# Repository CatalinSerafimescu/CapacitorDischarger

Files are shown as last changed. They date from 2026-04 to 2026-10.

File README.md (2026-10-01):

# 600V Capacitor Discharger

A professional, handheld capacitor discharger designed for safely discharging high-voltage capacitors in hobby electronics restoration — tube amplifiers, vintage radios, CRT televisions, and consumer power supplies.

---

## Features

- Discharges capacitors up to **600V** in **under 60 seconds** (up to ~1200µF)
- **Adaptive discharge:** controlled current above ~63 V (slow resistive path); fast dump below (MOSFET-switched). Switch point 55–83 V across Q1 hFE (25–300) and 0–60 °C corners; peak fast-dump current ≤ 1.6 A
- **Red LED danger indicator:** ON above ~10V, OFF when safe — powered directly from the capacitor, no external supply. Uses a low-current (2 mA) LED: the chain current is only ~50 µA at 30 V, where a standard LED looks dark
- **Integrated digital voltmeter:** Axiomet PM-128 3½-digit LCD reading volts directly ("600" at 600 V, 1 V steps) via a 10 000:1 divider, powered by any floating external 9 V source plugged into a panel DC jack (5.5×2.1)
- **Reverse polarity protection:** 1N4007 full-bridge rectifier
- **Protection fuse:** 600V-rated 2A fuse on the HV+ line guards against single-fault conditions
- **Thermal cutoff on R_fast:** if the probes touch a *live* supply below the threshold, Q2 stays on and R_fast would dissipate 41–74 W indefinitely (the 2 A fuse never blows) — a one-shot 133 °C thermal fuse clamped to R_fast opens the fast path; the slow path keeps working. **Still: never connect the tool to a powered circuit.**
- Designed for **DIY assembly** with through-hole components
- A residual ~1.2–1.4V remains on the capacitor (two bridge-diode drops) — below the 10V safe threshold

---

## Building it

Step-by-step build, wiring, test, calibration and use: **[instruction.md](instruction.md)**.
Single-sided board files: `KiCAD/fab_1s/`. 3D-printed case: [mechanical/enclosure/](mechanical/enclosure/README.md).

---

## Schematic

Schematic

---

## Bill of Materials

See **[bom.md](bom.md)** for the full component list with sourced vs. to-buy status.

**Note on DVM power:** the PM-128 draws ~1 mA from a 9 V source on its own DC jack (~500 h from an alkaline 9 V cell on a plug). Its datasheet requires the supply and the measured input to have separate grounds, so the source must float (battery or double-insulated adapter) — it is **not** connected to circuit GND.

**Note on DVM calibration:** set with the PM-128's own trimmer (R4) against a known DC voltage. The meter's >100 MΩ input doesn't load the divider. (The earlier 0–100 V LED module was dropped: its 0.525 MΩ input made the 6:1 divider uncalibratable.)

---

## Reference Designs

This design consolidates ideas from three published reference designs:

| Source | Designer | Reference File |
|---|---|---|
| [Pieraisa capacitor discharger kit](https://www.pieraisa.it) | Mark Maher/Pieraisa | [pieraisa.md](pieraisa.md) |
| [DIY 600V Capacitor Discharger — Constant Current](https://retronics.no/2024/03/30/diy-600-volts-capacitor-discharger-constant-current/) | Retronics.no | [600V_constant_current.md](600V_constant_current.md) |
| [Capacitor Discharger Deluxe – Smart, Fast & Safe High-Voltage Discharge](https://www.youtube.com/watch?v=5_QUd8iT3_g) | Manuel Caldeira / MAC Electronics | [deluxe.md](deluxe.md) |

---

## Improvements Over Reference Designs

### vs. Pieraisa
- Rated for **600V** (Pieraisa: 500V)
- **Automatic** threshold switching via MOSFET+NPN — no relay, no moving parts, no manual button
- Sharper LED cutoff: **~10.2V** Zener-defined threshold (Pieraisa: ~44V, divider-based)
- LED powered directly from HV+ — independent of relay state
- **Direct-reading voltmeter** with a 10 000:1 divider for the 600V range (Pieraisa's divider is mismatched at ~5:1)
- Each slow-path resistor explicitly stress-derated at 61% of rating at 600V

### vs. Retronics.no (constant current)
- **Faster discharge for large caps:** adaptive resistance allows higher initial current, not capped at 10mA
- Standard **FR4 through-hole PCB** — no aluminium PCB or SMD required
- No exotic ICs (Retronics requires LR8K4-G + 800V CoolMOS MOSFET pre-stage)
- **Integrated voltmeter**, calibratable (not present in Retronics design)
- Defined **10.2V LED cutoff** (Retronics LED is always in the current path — no threshold)

### vs. DeLuxe (Manuel Caldeira)
- MOSFET upgraded to **STP10NK80Z (800V, 0.9 Ω)** — IRF840 (500V) is marginal at 600V
- Slow path split into **5× 4.7kΩ/5W** in series — distributes heat; single 820Ω/10W in DeLuxe is a thermal bottleneck at high voltage with large caps
- **R1 and R5 properly rated** for 600V: 3W, 750V working voltage (DeLuxe leaves ratings unspecified)
- **Zener-defined LED threshold at 10.2V** — DeLuxe LED fades naturally with no defined safe cutoff; note the LED is dim below ~70V, so a low-current (2mA-rated) LED is used
- **Full voltmeter circuit added** with 10 000:1 divider, open-resistor input clamp, and battery-powered LCD meter (not present in DeLuxe)
- Every component carries explicit power and voltage stress analysis in the BOM

---

## Generating the Schematic and BOM

### Schematic

Requires [schemdraw](https://schemdraw.readthedocs.io/):

```
pip install schemdraw
python blocks/gen_full_schematic.py
```

Outputs `blocks/full_schematic.svg`.

### BOM

```
python bom.py
```

This prints a summary to the terminal **and** writes `bom.md` and the shopping list `TO_BUY_list.csv`.

The BOM (`bom.py`) is the single source of truth for all component data. It combines:
- **Design decisions** — part values, ratings, and stress calculations recorded directly in the BOM entries
- **Sourced components** — parts already in hand from the TME order (see [sourced_components.md](sourced_components.md)), marked `sourced` or `sourced_partial`
- **Parts to buy** — marked `buy`, with suggested part numbers

Schematic labels are generated from the same BOM data via the `LABEL` dictionary, so updating a value in `bom.py` automatically flows through to the schematic on the next generation run.

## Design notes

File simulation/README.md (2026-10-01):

# Simulation — 600 V Capacitor Discharger

Transient and DC-sweep SPICE simulations to verify every operating regime before PCB commit.

## Prerequisites

- **ngspice 46** at `E:\Catalin\Work\Electronics\NGSpice_46\bin\ngspice.exe`
- Python 3.x with `numpy`, `matplotlib`, `pandas`

Verify ngspice:
```
"E:\Catalin\Work\Electronics\NGSpice_46\bin\ngspice.exe" -v
```

## Running

```bash
cd simulation

# Run all scenarios
python run_sim.py --all

# Run one scenario
python run_sim.py A_full_600V_1mF

# List available scenarios
python run_sim.py --list
```

Results land in `results/<scenario_name>/`:
- `sim.cir` — rendered netlist fed to ngspice
- `out.csv` — time + node voltages + branch currents
- `plot.png` — 3-panel plot
- `summary.txt` — PASS/FAIL per assertion

Aggregate: `results/RESULTS.md`

## Scenarios

| Name | V0 | C_dut | Purpose |
|---|----|---|---|
| `A_full_600V_1mF` | 600 V | 1 mF | Full sweep, all regimes |
| `B_mid_300V_470uF` | 300 V | 470 µF  | Typical hobby cap |
| `C_mid_100V_100uF` | 100 V | 100 µF  | Brief slow then fast |
| `D_low_50V_100uF` |  50 V | 100 µF  | Fast-path-only from t=0 |
| `E_below_LED_8V_100uF` | 8 V | 100 µF  | LED stays OFF |
| `F_steady_state_600V`  | 600 V | 100 mF  | Quasi-steady-state probes |
| `G_threshold_sweep` | DC sweep 0→200 V | — | Confirm ~63 V switch point |
| `G2_threshold_lowbeta` | DC sweep 0→200 V | — | Worst-case low-hFE (BF=40) Q1 corner: switch point shifts only to ~68 V with R3 = 10 kΩ |
| `G3_threshold_cold_lowhfe` | DC sweep 0→200 V | — | Datasheet-min hFE (BF=25) at 0 °C: highest switch point (~83 V) → worst peak I_fast ≈ 1.6 A, still < 2 A |
| `G4_threshold_hot_highhfe` | DC sweep 0→200 V | — | BF=300 at 60 °C: lowest switch point (~55 V) |
| `H_dvm_divider_clamp` | DC sweep 0→600 V | — | PM-128 10 000:1 divider (5 × 100 kΩ over 2 × 100 Ω): reads 599.9 at 600 V (before R4 trim) and 10.00 at 10 V; with the bottom resistors open, D_clamp holds the meter input at 0.72 V |
| `I_reverse_600V_1mF` | −600 V | 1 mF | Reverse polarity: same 45 s discharge, −1.05 V residual, DVM still reads positive |
| `J_hotplug_600V` | 600 V | 1 mF | Probe contact onto a charged cap (1 µH leads, 1 µs contact): Q2 must not conduct |
| `K_bigcap_60V_47mF` | 60 V | 47 mF | ~85 J fast dump into R_fast — TF1 must not nuisance-trip |
| `L_live_supply_48V` | 48 V source | — | Probes on a live supply: R_fast would see ~41 W forever (F1 never blows) — TF1 must open |

(Scenario `H_dvm_led_module` was removed 2026-07-29: it documented that the parasitic Vcc dropper could not power a 20–30 mA LED-display DVM module; the real module measured 12–15 mA, so the dropper was replaced by an internal 9 V battery and the Vcc branch no longer exists in the netlists.)

## Adding a scenario

1. Add an entry to `scenarios.py::SCENARIOS` with `name`, `template`, `v0`, `cdut`, `tstep`, `tstop`, and an `assertions` function.
2. The assertions function receives a `pandas.DataFrame` (columns = ngspice output names) and returns `list[(bool, str)]`.
3. Run `python run_sim.py <your_name>`.

## Key nodes

| Node | Meaning |
|---|---|
| `V(HVp)` | Post-bridge discharge-network rail — ~1.2 V below the actual capacitor voltage (two diode drops through the reverse-polarity bridge D1-D4); all existing assertions are written against this rail |
| `V(n_probe_a)`, `V(n_probe_b)` | Capacitor terminals (transient scenarios only) — `V(n_probe_a) - V(n_probe_b)` is the true cap voltage, including the ~0.4-2.5 V permanent residual left by the bridge |
| `V(n_gate)` | MOSFET gate (~12 V = on, <1 V = off) |
| `V(n_sigout)` | PM-128 input — V(HVp) / 10 000 (×10 000 = displayed reading) |
| `I(V_islow)` | Slow path current |
| `I(V_ifast)` | Fast path (MOSFET) current |
| `I(V_iled)` | LED chain current |
| `V(n_temp)` | R_fast/TF1 body temperature in °C (behavioural thermal model) |
| `V(n_tf_latch)` | TF1 state: > 0.5 V = thermal cutoff has opened (one-shot) |

## Model notes

- **Q2 (fast-path MOSFET):** `STP10NK80Z` is a generic SPICE level-1 model standing in for the sourced BOM part (0.9 Ω Rds(on), 800 V, 9 A). It is not a vendor-supplied model — replace with one if available.
- **Q1 (threshold detector):** `QMPSA42` uses BF=150 (optimistic hFE). `QMPSA42LB` is a worst-case corner with BF=40, matching real MPSA42 hFE at ~1 mA collector current. With R3 = 10 kΩ (reduced from 100 kΩ on 2026-07-29) the switch point is nearly hFE-independent: scenario G measures 63 V with the nominal model, scenario G2 measures 68 V at the low-hFE corner. (With the old R3 = 100 kΩ these were 76 V and 154 V — the reduction was made precisely to close that spread.)
- **TF1 thermal model (assumed values):** R_fast power heats a 3 J/K heat capacity that leaks to 25 °C ambient through 25 K/W; TF1 (SEFUSE SF129E) opens permanently at 133 °C. These thermal constants are estimates for an Ohmite 27J (7 W) body with the TCO clamped on — confirm on the bench (48 V PSU on the probes should open TF1 within roughly 5–20 s; a 47 mF/60 V dump must not).
- **Corners:** G3/G4 use `discharger_dc_corner.cir.tmpl` with per-scenario `QMODEL`/`TEMP` substitutions. Scenarios can pass extra template substitutions through a `"subs"` dict; the transient template takes `DUT` and `IC` overrides (defaults in `run_sim.py`).
- **Error handling:** `run_sim.py` fails a scenario if ngspice exits non-zero *or* prints `fatal`/`error` anywhere in its output.
- **DVM power:** not modeled — the module is powered by an internal 9 V battery (its measured 12–15 mA draw exceeded what the former parasitic dropper could supply), so it presents no load to the HV circuit. Only its 600 kΩ signal divider remains in the netlists.

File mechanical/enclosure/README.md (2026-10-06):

# Enclosure: 3D-printable case for the single-sided board

There is one parametric FreeCAD script, [`gen_enclosure.py`](gen_enclosure.py), with all dimensions at the top.
[`assembly.py`](assembly.py) places the real board, the DC jack and stand-ins for the sockets, the PM-128 and the LED. It then
reports overlaps and HV distances. The result is saved as [`Enclosure_assembly.FCStd`](Enclosure_assembly.FCStd).

To regenerate, run both scripts inside FreeCAD (Python console or MCP), from `mechanical/enclosure/`:
```
exec(open("gen_enclosure.py", encoding="utf-8").read()); exec(open("assembly.py", encoding="utf-8").read())
```

The outside is **106.8 W × 132.8 D × 52 H mm**. It is designed for `CapacitorDischarger_1S` (100 × 75, FEPCU-075).

| Part | What it is | How to print |
|---|---|---|
| `Enclosure_base` (.step / .stl) | Open box: floor plus four walls, board standoffs, support posts, snap hooks, 4 screw bosses, socket, LED and jack holes, engraved 9 V warning | Floor down, no supports |
| `Enclosure_cover` (.step / .stl) | Top plate: meter window, baffled vents, lip inside the walls, 4 counterbored screw holes | **Upside down** (top on the bed), no supports |

- **Filament:** PETG or ASA, not PLA, because the resistors run hot.
- **Strength:** at least 3 perimeters and 25 % infill.
- **Style:** the same as the SursaTensiune case. It has R6 vertical corners, a 3 mm chamfer on the top edge and a 1.2 mm chamfer on the bottom edge.

## Layout
- **Front wall.** The sockets sit low (Z 15), in a 50 mm gap in front of the board.
  - **Danger LED (LED1)** at the top left, labelled "HV". It is on a 2-wire cable to J6 (JST XH) on the board.
  - It sits in a 5 mm panel clip (Ø8 collar, Ø6.5 body, 7 mm long) in a Ø6.6 hole at X 14.4. The hole is centred in the 8 mm gap between the front-left cover boss and the meter. Clip in from the front, LED pushed in from inside, no glue.
  - The black **−** socket (J2 → J4) and the green **+** socket (J1 → J3) are on the right, 20.5 mm apart.
  - Each socket lines up with the inner wire entry of its MKDS terminal block. Its M4 ring lug points straight into that entry, about 7 mm short of the block. The probe wires are short and straight, so they don't cross.
  - The terminal-block screws stay free to reach from the top.
- **Left wall, front end.** The 9 V DC jack sits low (Z 15) under an engraved warning triangle. Next to it:
  "9 V DC IN + centre / FLOATING SUPPLY ONLY / 9 V battery or isolated adapter. / NEVER an earthed / grounded supply!".
  The rear wall has no room for it: the board fills the box right up to it.
- **Cover.**
  - **PM-128 meter.** It sits above the socket gap: window 44.5 × 19.7 mm, plus two Ø3.2 holes 57.15 mm apart.
  - **Label.** "600 V MAX" is engraved under the meter.
  - **Vents.** Five 2 mm slots sit above R_slow1–5. Each slot has a solid baffle strip 3 mm below it, wide enough that no straight wire or probe tip can reach HV through a slot.
- **Board fixing.** The PCB has only 2 holes, so the base adds the rest:

  | Feature | Where | Job |
  |---|---|---|
  | 2 standoffs (6 mm) | H1, H3 | M3×12 **nylon** screws from the top, nuts in hex pockets under the floor |
  | 4 support posts | under J3/J4 (screwdriver force) and under the two F1 clip centres (pushing the fuse in) | carry the load |
  | 3 snap hooks | front-left, front-right and rear-left corners | a 45° ledge under the copper-free edge, and a nose 0.8 mm over the board top |
  | 4 side ribs | side walls | locate the board in X with 0.3 mm play |

  - The board clicks down into the hooks. To lift it out, take out the two screws and push the hooks outwards.
  - The board's top side has no copper, so the hooks only touch FR4. Leave the F1 clip centre holes empty, because the posts sit under them.
- **Cover fixing.** 4 × **M3×10** go into M3 heat-set inserts (Ø4.0 × 6.5 mm holes) in bosses hanging from the walls. The bosses have a 45° underside, so they print without support.
  - Three bosses are in corners. The fourth sits on the rear wall at X 20, so the LED cable can rise from J6 in that corner.
  - Opening the box needs a tool, which is right for an HV device. The magnets aren't needed.
- **Below the board.** The standoffs are 6 mm tall and all the HV copper is on the underside, so **trim every lead to ≤ 3 mm**. The stock TO-220 3D model shows uncut Q2 legs reaching the floor.

## Assembly
1. Fit the sockets (front wall) and the DC jack (left wall), with their nuts on the inside. Push the LED clip into the front wall from the outside,
   with its slots vertical so the body spreads up/down, away from the boss and the meter. Push the LED into it from inside:
   heat-shrink both legs, then crimp the XH housing onto ~15 cm of 1 kV silicone wire. Pin 1 = cathode (GND), pin 2 = anode.
2. Wire the sockets to J3/J4 with 1.5 mm² silicone wire (0.6/1 kV) and M4 ring lugs, and put heat-shrink over the lugs.
3. Press in the heat-set inserts.
4. Put the board on the standoffs, let it click into the hooks, and fit the two nylon screws. Plug the LED into J6
   (rear-left). Run its cable up and along the left wall, above the Q2 heatsink, then down to the front.
5. Fit the meter under the cover: two screws through the cover into the bezel. Wire the meter:
   - **Supply:** DC jack → PM-128 supply pins.
   - **Input:** J5 → PM-128 VIN / IN GND. This cable runs over the HV area, so use the same 1 kV silicone wire.
6. Leave the wires long enough that the cover can be laid down beside the box. Close it with the 4 M3×10 screws.
7. Stick rubber feet under the floor.

**9 V input:** any **floating** 9 V source on a 5.5×2.1 plug (centre +). A battery on a plug or a double-insulated adapter is fine. Never use a supply whose − is earthed or connected to the device under test, because circuit GND sits at the capacitor's negative terminal (see BOM, BT1).

## Fit check (FreeCAD, `assembly.py`)
- **Overlaps.** None between base and cover, or between either of them and the board, jack, sockets, meter or LED. The one exception is Q2's uncut 3D-model legs (see above).
- **Height.** The tallest part, R_fast1, tops out at Z 47.0, and the inner face of the cover is at Z 49.6.
  - Baffle strips → R_slow: ≥ 6.6 mm.
  - LED clip / LED flange → meter: 1.1 mm (clip → boss 0.75 mm). Both are LV; the meter only moves in Z when the cover goes on.
  - DC jack → meter: 8.3 mm.
- **HV clearances, all at least 6 mm:**
  - Meter → socket lugs/bolts: 6.9 mm.
  - Socket A metal → socket B metal: 12.5 mm.
  - Socket B → DC jack: 45.9 mm.
- **Tightest gap:** J3's terminal block and the front-right hook are 0.1 mm apart. That hook is 3 mm wide so it stays clear of the block.

## Check before printing
- **PM-128 (VERIFY):** 70 × 40 mm bezel, 23 mm deep, window 1.75 × 0.775 in, Ø3.2 holes 2.25 in apart (MPJA PM128 sheet). Measure your meter; the values are `MET`, `MET_WIN` and `MET_HOLE_*`.
- **Stäubli SLB4-G:** Ø12.1 hole with a flat 11.0 mm across, printed with the flat on top. The socket and nut in `assembly.py` are stand-ins; the real nut size isn't on the datasheet.
- **Heat-set inserts:** use one that fits a Ø4.0 hole and is ≤ 6 mm long. Otherwise change `INS_D` / `INS_L`. With `INS_D = 2.6` the screws thread straight into the PETG.
- **Test print:** print the front-right corner first (sockets, hook, boss) to check the socket fit and the hook snap.

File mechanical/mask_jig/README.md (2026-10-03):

# Solder-mask jig (single-sided board)

`Mask_jig.step` / `.stl`, made by `gen_mask_jig.py` (run in the FreeCAD GUI). For `CapacitorDischarger_1S`
(100 × 75 mm, Bungard FEPCU-075, 1.5 mm). 120.8 × 95.8 × 4.4 mm, print floor-down, no supports.

- **Pocket** 100.8 × 75.8 mm (0.4 mm per side around the board), **1.4 mm deep**: the 1.5 mm board sits 0.1 mm
  proud, so the film is pressed onto the board and then lies flat on the 10 mm frame. If your board is thinner
  than 1.4 mm, put a paper shim under it.
- **2 × Ø3.2 through holes** at the board's M3 holes H1 and H3, laid out for the board **copper side up**.
  Use Ø3 drill-bit shanks or M3 screws pushed up from below as registration pins. H1 and H3 aren't symmetric,
  so the board only fits one way round.
- Corner reliefs (square board corners in an FDM pocket) and 2 × Ø12 holes to push the board out from below.

## Use (UV solder mask)
1. Etched board **drilled**, cleaned, copper side up in the pocket. Pins up through H1 and H3.
2. Film: the B.Mask image on page 2 of `KiCAD/fab_1s/1S_films_1to1.pdf`, printed on transparency, **toner side down**.
   Punch or drill Ø3.2 through the two big H1/H3 dots. For a denser film, print it twice and stack the copies.
3. Paste on the board, film down over the pins, squeegee from the centre outwards. Excess goes into the gap and
   onto the frame. Tape the film edges to the frame.
4. Pull the pins out **downwards**, lay a sheet of glass on top for even pressure, expose. Ordinary picture-frame
   glass passes 395–405 nm LEDs well but cuts a lot at 365 nm: expose longer, or skip the glass with a 365 nm lamp.
5. Paste squeezed onto the frame cures there too. Cover the frame with one layer of packing tape before step 3 and
   peel it off afterwards, so the frame stays flat for the next board.
6. The HV slot under R1/R5 is already cut at this point (instruction.md step 4), so paste can squeeze through
   it onto the jig floor. Wipe the slot clean before exposing. Don't leave cured mask in it.

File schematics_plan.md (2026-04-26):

# Schematic Generation Plan

## Part 1 — HV Section (`hv_section.kicad_sch`)

**Components:**
- J1, J2 (banana sockets), J3, J4 (screw terminals) — input connectors
- D1–D4 (1N4007) — full-bridge rectifier
- R_slow1–R_slow5 (4.7 kΩ / 5W) — slow discharge path, series string to GND
- R_fast (50 Ω / 5W) — fast discharge path resistor
- Q2 (STF7NM80, TO-220) — MOSFET switch

**Interface nets (global labels):**
- `HV+` — rectified rail output
- `GATE` — Q2 gate input (driven by LV section)
- `GND`

---

## Part 2 — LV Section (`lv_section.kicad_sch`)

**Components:**
- Q1 (2N3904), R1 (1 MΩ), R2 (10 kΩ), R3 (100 kΩ), R4 (100 Ω), R5 (470 kΩ), D9 (12V Zener) — threshold detector + gate drive
- R_LED1–R_LED3 (100 kΩ), D_LED (8.2V Zener), LED1 (red 5mm) — danger indicator
- R_sig1–R_sig5 (100 kΩ), R_sig_bot (100 kΩ), R_cal (200 kΩ trimmer) — DVM divider
- R_drop1–R_drop4 (15 kΩ / 3W), D_Vcc (15V Zener), C_Vcc (10 µF), C_byp1, C_byp2 (100 nF) — DVM Vcc dropper
- DVM connector (3-pin: GND, Vcc, Signal)

**Interface nets consumed (global labels):**
- `HV+`, `GATE`, `GND`

---

## Part 3 — Assembly (`schematic.kicad_sch`)

- Combine both files into one `schematic.kicad_sch`
- Merge `lib_symbols` sections (deduplicate)
- Verify all global label pairs are matched
- Add `sheet_instances`, `title_block`, PWR_FLAGs

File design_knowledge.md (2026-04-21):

# Capacitor Discharger — Design Knowledge Base

---

# PART 1: Reference Designs

## Source 1: Pieraisa Kit (500V, Italian design)

See `pieraisa.md` for full analysis.

**Key lessons:**
1. Relay-based adaptive discharge is an excellent passive approach (no IC, no firmware)
2. Diode bridge polarity protection works but 1N4007 is marginal at high voltage — prefer IC-based ideal diode
3. Fast discharge bypass switch is a useful safety feature
4. Multiple series resistors validated for heat distribution
5. Zener-based LED threshold is clean and reusable — tune Zener + divider ratio for desired cutoff voltage
6. Voltmeter powered from same rail works, but only when cap is charged — ensure adequate voltage at all relevant levels

---

## Source 2: Capacitor Discharger DeLuxe (MAC / Electronics Old & New, REV 1.0, 2025-12-22)

See `deluxe.md` for full analysis.

**Key lessons:**
1. MOSFET + NPN transistor gives clean automatic threshold switching with no moving parts (vs. relay)
2. 71V threshold set by R1/R2 divider + Q1 Vbe — above: slow controlled discharge; below: fast discharge via low-side MOSFET
3. Gate clamp zener (12V) protects MOSFET gate and sets clean gate drive regardless of cap voltage
4. Q1 can be any common NPN (2N3904, BC547) — no high-voltage rating needed
5. IRF840 is marginal at 600V (rated 500V Vds) — substitute with 700V+ device (e.g. STF7NM80, IXTP2N80)
6. 1N4007 bridge adequate for 600V (PIV = 1000V) but IC-based protection is our preference
7. PCB is compact (74×30mm) — design fits a handheld tool form factor

---

# PART 2: Our Design Knowledge & Decisions

---

## PCB Design — High Discharge Current Requirements

### Peak Current Analysis

| Path | Condition | Resistance | Peak current |
|---|---|---|---|
| High-V path | V_cap = 600V, R ≈ 820Ω | 820Ω | ~731mA |
| Low-V path (via MOSFET) | V_cap = 71V (switch point), R = 56Ω | 56Ω | **~1.27A** |

Design target: traces and pads must handle **2A continuous** with adequate margin.

### Trace Width

Per IPC-2221A (1oz copper, 10°C temperature rise):
- 1A → ~0.5mm minimum
- 2A → ~1.0mm minimum
- **Recommendation: 1.5–2.0mm on all discharge-path traces**; use copper pour (polygon fill) on GND and HV discharge return nodes

### High-Voltage Clearance and Creepage (600V, uncoated PCB)

| Metric | Rule of thumb | 600V value |
|---|---|---|
| Air clearance | 1mm per 100V | **≥6mm** |
| Creepage (external, uncoated) | IPC-2221, 300–900V range | **≥6mm** |
| Creepage (conformal coated) | Reduced per IEC 60664-1 | ~3mm (if coated) |

- Apply between: HV input traces, discharge resistor pads, MOSFET drain pad, and any GND/LV traces
- The DeLuxe PCB (74×30mm) achieves this by physically separating the HV resistor area from the control section

### Input Terminal Pads

- Use **≥4mm diameter** copper pads (confirmed from DeLuxe Gerbers)
- Screw terminals or banana jack sockets rated for ≥600V, ≥2A
- 1.5mm slotted drill holes (as in DeLuxe) suit standard 4mm banana terminals
- Solder with adequate fillet; consider through-hole reinforcement for mechanical stress

### Power Resistors

- Use **axial wirewound** resistors (e.g. Arcol HS, Vishay RH series) — better pulse energy handling than ceramic
- Mount with **minimum 3mm standoff** from PCB surface for convection cooling
- Orient resistors so airflow is not blocked by adjacent tall components
- Footprint pad spacing must match resistor body length at rated wattage (10W axial body ≈ 30–40mm)

### MOSFET

- TO-220 package preferred — easy heatsink attachment
- Include **heatsink mounting hole** on PCB or thermal pad area
- Place MOSFET at board edge for heatsink clearance
- Drain pad should connect directly to the wide discharge trace; avoid long thin drain neck

### Layout Zones

```
[ INPUT TERMINALS ] ─── [ HV DISCHARGE PATH ] ─── [ POWER RESISTORS ]
                               │
                         [ MOSFET + Heatsink ]
                               │
                    ─────────────────────────────
                    [ CONTROL / BIAS CIRCUIT     ]   ← Low voltage
                    [ LED + VOLTMETER DIVIDER    ]   ← Keep separated from HV
```

- Physical separation of ≥10mm between HV discharge traces and LV bias/LED/voltmeter traces
- Route voltmeter divider resistors away from the discharge current loop to avoid inductive interference

### Additional Notes

- **No 90° corners** on HV traces — use 45° or curved routing
- **Conformal coating** strongly recommended on finished board — especially over HV traces, divider resistors, and input pad area
- **Silkscreen warning** on PCB: mark polarity, voltage rating, and "HIGH VOLTAGE" near input terminals

---

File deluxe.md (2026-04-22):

# Capacitor Discharger DeLuxe — Schematic Analysis

**Source:** https://www.youtube.com/watch?v=5_QUd8iT3_g
**Schematic** https://drive.google.com/drive/folders/14RW6CgVl9O2DX6QJiTpvzaHROwtBKmW-
**Designer:** MAC / Electronics Old & New — REV 1.0  

---

## Core Design Intent

> "At high voltage → controlled, safe discharge. As voltage drops → discharge speed increases."

The circuit automatically adjusts discharge resistance based on capacitor voltage — no manual switching needed.

---

## Circuit Topology

### 1. Reverse Polarity Protection — Diode Bridge
- **D1–D4:** 4× 1N4007, full-bridge rectifier
- Probes can be connected in either polarity; rectified rail is always correct polarity internally
- 1N4007 PIV = 1000V — adequate margin for 600V use
- Voltage drop: ~1.4V across two diodes in series (negligible at high voltage)

### 2. Voltage-Sensing / Threshold Circuit
- **R1 (1MΩ) + R2 (10kΩ):** Voltage divider from rectified rail to GND
- **R3 (100kΩ):** Base resistor into Q1
- **Q1 (MPSA42 or 2N3904 NPN):** Turns ON when cap voltage exceeds threshold

**Threshold calculation:**
```
V_base = V_cap × R2 / (R1 + R2) = V_cap × 10k / 1.01M
Q1 turns ON when V_base > 0.7V → V_cap > ~71V
```

### 3. Gate Drive Circuit
- **R5 (470kΩ):** Pulls IRF840 gate toward rail voltage
- **R4 (100Ω):** Series gate resistor (limits gate charge/discharge speed)
- **D9 (12V Zener, 1.3W):** Clamps gate to 12V max (protects IRF840 gate oxide)
- **Q1 collector → R4 → gate:** When Q1 is ON, pulls gate low (overrides R5 pull-up)

**Gate voltage with Q1 ON (KCL, R5=470k, R4=100Ω, Q1 Vce_sat=0.2V):**
```
V_gate ≈ (V_cap/R5 × R4) + 0.2V ≈ 0.33V at 600V → IRF840 OFF
```

**Gate voltage with Q1 OFF:**
```
V_gate = min(V_cap, 12V) via R5 and D9 clamp → IRF840 ON
```

### 4. Main Discharge Paths

| Condition | Q1 | IRF840 | Active Path | Resistance | Behavior |
|---|-----|---|---|---|---|
| V_cap > 71V | ON | OFF | R7 (820Ω/10W) | 820Ω | Controlled, safe |
| V_cap < 71V | OFF | ON | IRF840 + R6 (56Ω/10W) | ~56Ω | Fast discharge |
| V_cap < 3–4V | OFF | OFF (Vgs < Vth) | None | ∞ | Fully discharged |

- **R7 (820Ω/10W):** Always-on high-resistance path — handles high-voltage discharge safely  
  - At 600V, peak power = 600²/820 = **439W** (brief pulse — acceptable for small caps)  
  - At 90V, peak power = 90²/820 = **9.9W** — right at rating; suitable for large caps (33,000µF range)
- **R6 (56Ω/10W):** Low-resistance fast path — active only below 71V via IRF840

### 5. LED Danger Indicator
- **R8 (100kΩ) + LED1:** Series from rail to GND
- Powers directly from capacitor — no external supply
- At 600V: I ≈ 6mA (bright)
- Dims as voltage drops; effectively invisible below ~3–5V
- **LED ON = charge present / dangerous; LED OFF = safe**

---

## Component List

| Ref | Value | Rating | Function |
|-----|---|---|---|
| D1–D4 | 1N4007 | 1000V / 1A | Bridge rectifier (reverse polarity protection) |
| Q1 | MPSA42 or 2N3904 | NPN | Voltage threshold sense transistor |
| IRF840 | Power MOSFET | 500V / 8A | Main discharge switch |
| D9 | 12V Zener | 1.3W | IRF840 gate clamp |
| R1 | 1MΩ | — | Voltage divider top leg |
| R2 | 10kΩ | — | Voltage divider bottom leg (sets 71V threshold) |
| R3 | 100kΩ | — | Q1 base resistor |
| R4 | 100Ω | — | IRF840 gate series resistor |
| R5 | 470kΩ | — | IRF840 gate pull-up |
| R6 | 56Ω | 10W | Fast (low-V) discharge resistor |
| R7 | 820Ω | 10W | Slow (high-V) discharge resistor |
| R8 | 100kΩ | — | LED current limiter |
| LED1 | Red LED | — | Voltage/danger indicator |

---

## Design Notes & Observations

### Switching Threshold (71V)
- Derived from R1/R2 divider and Q1 Vbe (0.7V)
- Adjustable by changing R1 or R2: `V_th = 0.7 × (R1 + R2) / R2`
- Example: for 50V threshold → R1 ≈ 700kΩ; for 100V → R1 ≈ 1.43MΩ

### IRF840 Voltage Rating
- IRF840 rated for 500V Vds — **marginal for 600V use**
- For 600V designs, consider: IRFBF20 (900V), STP6NK90Z (900V), or IRFP9240 (200V P-ch, not suitable) — prefer a 700V+ N-ch MOSFET with similar gate characteristics
- Alternatively: IRF740 (400V — too low), IXTP2N80 (800V), STF7NM80 (800V)

### Q1 Transistor Note
- Original schematic listed MPSA42 (high-voltage NPN, 300V), but designer corrected: **any common NPN works** (2N3904, BC547, etc.)
- Q1 never sees more than a few volts (gate/base voltages are clamped) — voltage rating is irrelevant

### Reverse Polarity — Bridge vs. IC
- This design uses a 1N4007 bridge (passive, robust, no power needed)
- 1N4007 PIV = 1000V; adequate for 600V with margin
- Per our project preference, an IC-based ideal diode (e.g. LTC4359) would reduce voltage drop and is preferred — **bridge can be replaced if needed**

### R7 Power Handling — Large Capacitors
- At high voltage (>71V), only R7 (820Ω/10W) is in the discharge path
- **Safe for small/medium caps** at high voltage (energy = ½CV²; low C means low total energy)
- **Marginal for very large caps** (e.g. 33,000µF @ 90V → ~134J through R7 at ~9.9W average; borderline)
- For large caps at high voltage, consider increasing R7 wattage or splitting into 2× 1kΩ/10W in parallel = 500Ω/20W

---

## Adaptations Needed for Our Requirements

| Requirement | Original DeLuxe | Action Needed |
|---|---|---|
| 600V rating | IRF840 = 500V (marginal) | Replace with 700V+ MOSFET (e.g. STF7NM80) |
| Voltmeter (0–100V DVM, 6:1 divider) | Not present | Add R_high (500kΩ) + R_low (100kΩ) divider; power DVM from divider output |
| IC-based polarity protection | 1N4007 bridge | Optional: replace bridge with LTC4359/MAX16141 |
| Series resistor network | R6 + R7 only | Current distribution is limited; consider 2 resistors per path for heat spread |
| LED threshold (5–10V cutoff) | Fades naturally below ~5V | Acceptable; or add Zener for sharper threshold (Pieraisa approach) |
| Digital voltmeter power | Not present | Tap from rectified rail via series resistor (e.g. 470kΩ) to power 5–30V DVM |

---

## Voltage Divider for Voltmeter (to add)

6:1 divider for 0–600V → 0–100V (DVM input):
```
R_high = 500kΩ (HV-rated, e.g. 5× 100kΩ/2W in series)
R_low  = 100kΩ (1% tolerance)
Divider ratio = 100k / (500k + 100k) = 1/6
At 600V input → 100V DVM input ✓
```
DVM powered from the R_low node (0–100V range covers the 5–30V DVM supply requirement only if cap voltage > 5V; for lower voltages DVM may power off — acceptable).

---

## Key Design Strengths

1. **Fully automatic adaptation** — no switches, no user interaction
2. **Simple, few components** — Q1, one MOSFET, two resistors, zener
3. **LED indicator** powered directly from cap — no external supply needed
4. **Inherent LED shutoff** at ~3–5V (safe voltage)
5. **Fast at low voltage** — 56Ω gives fast final discharge

---

## PCB Information (from Gerber v2.0, 2025-11-12)

- **Board size:** 73.66mm × 30.48mm (~74mm × 30mm) — compact, single PCB
- **Designed in:** EasyEDA v6.5.51
- **Layers:** 2-layer (top + bottom copper)
- **Notable pad/drill sizes:**
  - 4.0mm circular pads — large input/output terminal pads (high current)
  - 2.6×1.8mm oval+rect pads — power resistor pads (R6, R7 axial footprints)
  - 1.5mm slotted drill holes (×4, at corners) — input connectors (banana jack or screw terminal)
  - 0.75mm holes (×3, in-line) — TO-92 transistor Q1
  - 0.90mm slotted holes — diodes (D1–D4, D9)
  - 1.0–1.2mm holes — standard resistor/MOSFET leads

---

## Key Limitations vs. Our Requirements

1. IRF840 is marginal at 600V → needs substitute
2. No voltmeter circuit (must be added)
3. No IC-based polarity protection (bridge is functional but not preferred)
4. R7 (820Ω/10W) may overheat with very large caps at high voltage

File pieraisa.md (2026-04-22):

# Source 1: Pieraisa Kit — Reference Analysis

**Origin:** https://www.pieraisa.it/forum_share/KITS/Discharge.Tool.Datasheet.pdf
**Based on Mend It Mark design** https://www.youtube.com/watch?v=pNkEchLQWDU

**Rating:** 500V max, RDS = 120Ω min / 940Ω typ / 5640Ω max  

---

## Topology: Diode Bridge for Reverse Polarity Protection

- 4× 1N4007 diodes form a full bridge (D1+D3 on top rail, D4+D5 on bottom rail)
- Ensures discharge current always flows in the same direction through the circuit regardless of probe polarity
- Simple, passive, no IC needed
- **Limitation:** 1N4007 PIV = 1000V — right at the limit for 1000V designs; at 1000V, voltage spikes or transients will exceed the rating
- **Trade-off:** ~1.4V forward drop across two diodes in series (acceptable for high-voltage discharge, minimal energy loss)
- **For 1000V designs:** Need higher-rated diodes (e.g., 1N5408 = 1000V, or HV series like FR107, P6KE series), or move to IC-based protection

---

## Topology: Relay-Based Adaptive Discharge (Passive, Elegant)

- R2 (10kΩ, 7W) connects directly from the rectified high-voltage rail to the relay (RL1) coil
- At high capacitor voltage → sufficient current through R2 → relay energizes → connects low-resistance discharge path (R5 = 120–220Ω, 5W)
- As voltage drops → coil current decreases → relay drops out at its dropout voltage → circuit switches to higher resistance path (R1+R4 = 940Ω)
- **This is fully passive and automatic — no control IC, no comparator, no firmware**
- The relay dropout voltage determines the switching threshold (typically 8–10V for a 12V relay)
- **Key insight:** The relay coil itself acts as a current sensor and threshold detector simultaneously

---

## Resistor Network

| Resistor | Value | Power | Role |
|---|---|---|---|
| R5 | 120 or 220Ω | 5W | Fast/low-resistance discharge path (relay energized) |
| R1 | 470Ω | 5W | Series discharge resistor (relay dropped out) |
| R4 | 470Ω | 5W | Series discharge resistor (relay dropped out), R1+R4 = 940Ω |
| R2 | 10kΩ | 7W | Relay coil current limiter / adaptive threshold setter |
| R6 | 4.7kΩ | 7W | Auxiliary discharge / part of resistor ladder |

- Multiple resistors in series distributes thermal load — no single large ceramic resistor
- Power rating must account for worst-case: E = ½CV² for largest expected capacitor

---

## Fast Discharge Override (Manual Switch)

- SW T2 and SW T4: two switches that bypass the diode bridge legs
- When both closed: R5 is connected directly in the discharge path, bypassing diode drops
- Activated by button W1 (labeled "FAST" mode)
- **Recommended use: only when voltage is above 70V** — below 70V the relay has dropped out and the slower path is sufficient
- At high voltage (>70V): R5 (120/220Ω) is included in the path, giving minimum resistance and maximum discharge current
- **Note:** Bypassing diodes means polarity protection is lost in fast discharge mode — user must ensure correct probe orientation
- **Design insight:** Fast mode is a user-initiated safety assist, not automatic — the operator judges when to use it based on voltage reading

---

## LED Danger Indicator

- Voltage divider: R3 (680kΩ) + R8 (100kΩ) scales down the capacitor voltage
  - Divider ratio: 100k / (680k + 100k) ≈ 0.128
- D2 (5.6V Zener, 1W) + R9 (470Ω) + LED1 form a threshold indicator
- **Behavior: LED ON = dangerous (high voltage present); LED OFF = safe**
  - High cap voltage → sufficient current through divider → D2 conducts → LED lights (warning)
  - Cap voltage drops below threshold → D2 stops conducting → LED goes OFF (safe to touch)
- The Zener threshold + divider ratio sets the turn-off point:
  - D2 threshold ≈ 5.6V at divider node → cap voltage at turn-off ≈ 5.6V / 0.128 ≈ **44V**
- Pieraisa's Zener-threshold approach is directly reusable for our design

---

## Voltmeter Integration

- Digital voltmeter W2 (P1): 3-wire type (VCC+, signal IN, GND)
- Powered from VCC rail (same as capacitor voltage through divider/relay)
- Input signal = output of R3/R8 voltage divider
- R3 (680kΩ) also doubles as the voltmeter VCC source resistor
- DVM range: 0–100V, so divider must scale max cap voltage to ≤100V
  - For 500V max: ratio needed = 100/500 = 0.2 → but actual ratio here is 0.128 → max reading = 64V at 500V (under-ranges slightly or voltmeter is calibrated)
  - **For our 600V design:** Need 6:1 divider (0–100V DVM → 6:1 → 0–600V range)

---

## Key Design Lessons from Pieraisa

1. **Relay-based adaptive discharge is an excellent passive approach** — worth adopting; need a 600V-capable relay or place relay on low-voltage side of divider
2. **Diode bridge polarity protection** works well but 1N4007 is marginal at high voltage; for our design use IC-based ideal diode (as per our requirement)
3. **Fast discharge bypass switch** is a useful safety feature — bypassing bridge or adding a direct low-resistance path
4. **Multiple series resistors** for discharge is validated — distribute heat across R1, R4, R5, R6
5. **Zener-based LED threshold** is clean — tune Zener voltage and divider ratio for desired safe threshold (5V or 10V per our requirement)
6. **Voltmeter powered from same rail** through a resistor — simple but means voltmeter only works when cap is charged; our design should ensure voltmeter has adequate power at all relevant voltages

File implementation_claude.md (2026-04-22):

# Capacitor Discharger — Implementation Plan

## Context

Build a professional handheld **600V Capacitor Discharger** for hobby electronics restoration — tube amps, vintage radios, CRT TVs, consumer linear/SMPS PSUs. The tool must:

- Discharge typical hobby caps (100µF–1mF at up to 600V) in **under 60 s**
- Adapt automatically: controlled current above ~71 V, fast dump below
- Red "danger" LED ON whenever V > ~10 V, OFF below (no external supply)
- Continuous **0–100 V digital voltmeter** readout via **6:1 input divider**
- Tolerate reverse probe polarity
- Reuse already-sourced components where possible; new parts limited to power-rated resistors (Ohmite WN-series), a higher-V MOSFET, and a handful of Zeners/diodes

This plan consolidates the **DeLuxe (MAC)** adaptive MOSFET topology, the **Pieraisa** parasitic DVM-power approach, and our PCB rules into one coherent design adapted for 600 V rating.

## Design decisions (confirmed with user)

| Decision | Chosen |
|---|---|
| Slow-path resistor network | **5× 4.7 kΩ / 5 W** Ohmite WN-series (or equivalent wirewound / ceramic cement) |
| Threshold detection | **Q1 NPN (DeLuxe-style)** — 2N3904 + divider, self-biased |
| DVM power | **Parasitic from cap rail (Pieraisa-adapted)** — dropper + 15 V Zener + smoothing cap |
| LED safe-cutoff | **~10 V** — 8.2 V Zener + red LED + 300 kΩ current limit |
| Polarity protection | **4× 1N4007 full-bridge** (bridge chosen over LTC4359: avoids a second HV bias rail that doubles circuit complexity for marginal gain at these voltages) |

## Topology

```
PROBE_A ─┐
         ├── [4× 1N4007 bridge] ─── HV+ RAIL ────────┬── R_slow  (5× 4.7kΩ/5W) ─────────────────── GND
PROBE_B ─┘                                           │
                                                     ├── R_fast (50Ω/5W) ── Q2 Drain
                                                     │                      Q2 Source ─ GND
                                                     │                      Q2 Gate ← R4 ← Q1_collector (GND when V>71V)
                                                     │                                   ← R5 ← HV+  (pull-up, clamped by D9 12V)
                                                     ├── R1 (1MΩ) ── node_A ── R2 (10kΩ) ── GND
                                                     │                 └── Q1 base (2N3904, emitter=GND)
                                                     ├── R_LED (3× 100kΩ) ── D_LED (8.2V Z) ── LED1 ── GND
                                                     ├── R_sig_top (5× 100kΩ) ── node_sig ── R_sig_bot (100kΩ) ── GND
                                                     │                            └── DVM Signal-In
                                                     └── R_drop (4× 15kΩ/3W) ── node_Vcc ── D_Vcc (15V Z) // C_Vcc (10µF) ── GND
                                                                                  └── DVM Vcc+
```

## Block-by-block design

### 1. Reverse-polarity protection
- **D1–D4**: 4× 1N4007 (DO-41 through-hole) — PIV 1000 V, I_F 1 A. 400 V margin over 600 V, ~1.4 V total forward drop (negligible at HV).

### 2. Slow discharge path (always on, dominant above 71 V)
- **R_slow**: 5× **4.7 kΩ / 5 W wirewound** in series (Ohmite WN series or equivalent ceramic cement).
- Total **23.5 kΩ / 25 W / 1750 V** working voltage.
- At 600 V: 25.5 mA, **3.06 W per resistor (61 % of rating)**, 120 V per resistor (well under 350 V part limit).
- 600 V → 71 V transition: τ · ln(600/71) = 23.5 s × 2.135 × C_cap
  - 100 µF → 5 s   ·   470 µF → 22 s   ·   1 mF → 50 s ✓   ·   1.2 mF → 60 s (practical ceiling)
- **Mount**: axial, ≥3 mm PCB standoff, in a row oriented for airflow.

### 3. Fast discharge path (MOSFET-switched, active below 71 V)
- **R_fast**: 50 Ω / 5 W wirewound (Ohmite WN or equivalent).
- **Q2**: **STF7NM80** (TO-220, 800 V V_ds, 6 A I_d, R_ds(on) 1.7 Ω typ). Alternatives: STP10NK80Z, IXTP2N80. IRF840 (500 V) rejected — marginal for 600 V.
- At switch-on (V_cap = 71 V): I_peak = 1.42 A, P_peak ≈ 100 W for τ = 50 Ω·C_cap seconds; energy for 1 mF cap = 2.5 J (trivial for TO-220 SOA).
- **Mount**: TO-220 at board edge with clip-on heatsink (~10 °C/W, e.g. Wakefield 637-10ABPE).

### 4. Threshold detector (Q1 NPN, DeLuxe-style)
| Ref | Value / Part | Source |
|---|---|---|
| Q1 | 2N3904 NPN TO-92 | **buy** |
| R1 | 1 MΩ / 1 W / ≥600 V metal film | **buy** |
| R2 | 10 kΩ / 0.25 W | **buy** |
| R3 | 100 kΩ / 0.6 W (Q1 base) | **stock** (MF006FF1003A50) |
| R4 | 100 Ω / 0.25 W (gate series) | **buy** |
| R5 | 470 kΩ / 1 W / ≥600 V metal film (gate pull-up) | **buy** |
| D9 | 12 V / 1.3 W Zener (BZX85C12) | **buy** |

- **Threshold**: V_th = 0.7 V · (R1 + R2) / R2 = **71 V**. Tune via R2 if desired.
- V_cap > 71 V → Q1 saturates → gate pulled to ~0.33 V → Q2 **OFF** → slow path only.
- V_cap < 71 V → Q1 off → gate pulled to V_rail clamped at 12 V by D9 → Q2 **ON** → fast path adds.

### 5. LED danger indicator (~10 V cutoff)
- **Chain**: HV+ → R_LED (3× 100 kΩ series = 300 kΩ) → D_LED (8.2 V / 0.5 W Zener, BZX55C8V2) → LED1 (5 mm red, V_f ≈ 2 V) → GND.
- **Cutoff**: V_cap > V_Z + V_f ≈ **10.2 V** → conduction; below → LED OFF.
- 600 V: I_LED ≈ 2 mA (bright);  100 V: 0.3 mA (dim-visible);  <10 V: 0.
- R_LED per-resistor stress: 200 V / 0.4 W at 600 V input (inside 250 V / 0.6 W rating).

### 6. DVM signal divider (6:1)
- **R_sig_top**: 5× 100 kΩ / 0.6 W / 250 V in series = 500 kΩ (each resistor sees 100 V at 600 V rail — well within 250 V rating).
- **R_sig_bot**: 1× 100 kΩ.
- Ratio **100 k / 600 k = 1/6**. At 600 V cap → 100 V at DVM signal pin (full scale).
- String current 1 mA total; 0.1 W per resistor (cool).
- **Optional calibration**: sourced 200 kΩ trimmer (T93YA200K) in series with R_sig_bot allows fine-tune of full-scale reading.

### 7. DVM Vcc dropper (parasitic, Pieraisa-adapted)
- **R_drop**: 4× **sourced MOF3WS-15K** (15 kΩ / 3 W / 500 V metal-oxide) in series = 60 kΩ / 12 W capacity.
- **D_Vcc**: 15 V / 1 W Zener (1N4744A) — shunt regulator.
- **C_Vcc**: 10 µF / 25 V electrolytic (reuse **sourced EEAGA1E100H**) across Zener for ripple smoothing.
- 600 V cap: I = (600−15) / 60 k = **9.75 mA** → P per resistor 1.42 W (49 % of 3 W — comfortable).
- DVM live when V_cap > ~20 V; below that DVM turns off (same behaviour as Pieraisa — acceptable because LED is also off by then).
- **Verify DVM current rating**: if the sourced DVM draws > 9 mA at 15 V V_cc, reduce R_drop to 3× 15 kΩ (45 kΩ, 13 mA headroom).

## Complete BOM

### Reuse from stock
| Qty | Used for | Part / sourced # |
|---|---|---|
| 10 | R3, R_LED×3, R_sig_top×5, R_sig_bot | 100 kΩ / 0.6 W / 250 V (MF006FF1003A50) |
| 4 | R_drop×4 | 15 kΩ / 3 W / 500 V MOF3WS-15K |
| 1 | C_Vcc | 10 µF / 25 V electrolytic (EEAGA1E100H) |
| 1 (optional) | DVM calibration trimmer | 200 kΩ (T93YA200K) |
| 2 | Input terminals | SLB4-G-21/-22 banana sockets or MKDS5/2-9.5 screw terminals |
| 2 (bypass) | Local decoupling near Q1/DVM | 100 nF / 50 V ceramic (K104K10X7RF5UH5) |

### To buy
| Qty | Ref | Part / value | Suggested P/N |
|---|---|---|---|
| 5 | R_slow | 4.7 kΩ / 5 W wirewound | Ohmite WN-series or Vishay AC05 |
| 1 | R_fast | 50 Ω / 5 W wirewound | Ohmite WN-series |
| 1 | Q2 | 800 V N-MOSFET TO-220 | STF7NM80 / STP10NK80Z / IXTP2N80 |
| 4 | D1–D4 | Bridge diodes | 1N4007 |
| 1 | Q1 | Small-signal NPN | 2N3904 |
| 1 | R1 | 1 MΩ / 1 W / ≥600 V metal film | any (verify voltage rating) |
| 1 | R2 | 10 kΩ / 0.25 W | any |
| 1 | R4 | 100 Ω / 0.25 W | any |
| 1 | R5 | 470 kΩ / 1 W / ≥600 V metal film | any (verify voltage rating) |
| 1 | D9 | 12 V / 1.3 W Zener | BZX85C12 |
| 1 | D_LED | 8.2 V / 0.5 W Zener | BZX55C8V2 |
| 1 | D_Vcc | 15 V / 1 W Zener | 1N4744A |
| 1 | LED1 | 5 mm red LED | any (V_f ≈ 2 V) |
| 1 | Heatsink | TO-220 clip-on, ~10 °C/W | Wakefield 637-10ABPE |

## PCB design rules (from `design_knowledge.md`)

- Trace width ≥ **1.5 mm** on all discharge-current nets (HV+, drain, source, slow/fast resistor strings); copper pour on GND return.
- HV clearance/creepage ≥ **6 mm** (IPC-2221, 600 V, uncoated).
- Input pads ≥ **4 mm** diameter.
- Axial power resistors on ≥ 3 mm standoff, aligned in a row for airflow.
- Q2 at board edge with heatsink mounting hole; wide drain trace, no narrow neck.
- Physical separation ≥ **10 mm** between HV section (bridge → R_slow / R_fast / Q2) and LV section (Q1, LED, DVM divider, Vcc dropper).
- No 90° corners on HV traces — use 45° or curves.
- Silkscreen: "HIGH VOLTAGE — UP TO 600 V DC" near input terminals; polarity hint; Zener / LED / electrolytic polarity marks.
- Conformal coating strongly recommended on finished board, especially across HV nets and divider strings.

## Critical files / deliverables

| File | Purpose |
|---|---|
| `schematic.kicad_sch` (new) | Full KiCad 7+ schematic — ideally mirror block structure above |
| `pcb.kicad_pcb` (new) | 2-layer PCB following the rules section |
| `bom.md` (new) | Consolidated BOM with sourced vs. to-buy status |
| `assembly_notes.md` (new) | Mount orientation for R_slow, Q2 heatsink, polarity of bridge / Zeners / electrolytic |
| `CLAUDE.md` (reference) | Top-level requirements, voltage rating, PCB rules |
| `design_knowledge.md` (reference) | PCB / layout guidance, reused verbatim |
| `deluxe.md`, `pieraisa.md` (reference) | Cross-check topology and component-value rationale |
| `sourced_components.md` (reference) | Confirm stock parts before ordering |

## Verification / test procedure

### Phase 1 — low-voltage bench test (≤ 30 V, on breadboard)
1. Wire up threshold + MOSFET + LED + DVM sections with breadboard jumpers; use a bench DC supply in place of cap+bridge.
2. Sweep 0 → 30 V at the "HV+" node:
   - LED turns ON above ~10 V, OFF below ✓
   - DVM reads proportionally (use optional 200 kΩ trimmer to zero the span)
   - At these voltages Q1 stays OFF, Q2 stays ON, fast path is live — verify with a small test cap (1 µF) that it discharges quickly.

### Phase 2 — mid-voltage test (100–300 V, assembled PCB, charged electrolytic)
1. Charge a 100 µF / 450 V cap to 300 V via a current-limited HV source (variac + bridge, or HV bench supply).
2. Connect probes; time the discharge with a scope on the DVM signal node (or the DVM itself).
3. Verify:
   - LED stays on until V_cap ≈ 10 V, then off
   - DVM tracks from 300 V down to ~20 V (then goes dark as dropper output dips below 5 V)
   - No visible smoke, resistor body temps < 80 °C after 10 consecutive discharges (IR gun)

### Phase 3 — full 600 V test (post-conformal-coat)
1. Charge a test cap rated ≥ 700 V (e.g. 470 µF / 700 V film or a test jig with 2× 450 V electrolytics in series) to exactly 600 V.
2. Discharge via tool; measure time with a stopwatch + DVM:
   - 470 µF / 600 V → expect ~22 s to reach 71 V, then sub-second fast path. Total < 25 s ✓
   - 1 mF / 600 V → expect ~50 s. Total < 52 s ✓
3. Repeat 5× to confirm repeatability. Inspect for discolouration on R_slow bodies.
4. **Safety checks**:
   - Reverse-polarity test: apply 50 V backwards, confirm bridge routes correctly, no smoke.
   - Probe short-circuit test: short probes together with tool powered — nothing should happen (no current unless a cap is attached).
   - Leave tool connected to a charged 1 mF / 600 V cap after discharge completes; verify MOSFET + dropper resistors do not heat up in steady state (MOSFET should be OFF below 71 V and no sustained current should flow after cap reaches ~10 V).

### Calibration
- With a known reference voltage (e.g. a 300 V bench HV supply), adjust the optional 200 kΩ trimmer in series with R_sig_bot until DVM reads 50.0 V (300 V / 6).
- Repeat at 100 V and 500 V to confirm linearity.

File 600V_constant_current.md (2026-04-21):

# 600V Constant Current Capacitor Discharger — Circuit Analysis

**Source:** https://retronics.no/2024/03/30/diy-600-volts-capacitor-discharger-constant-current/  
**Schematic:** https://retronics.no/wp-content/uploads/2024/03/capdisc_constantcurrent2.jpg  
**GitHub:** https://github.com/donpivo/CapacitorDischarger/tree/main/Discharger_ConstantCurrent

---

## Operating Principle

Constant current discharge using the **LR8K4-G** high-voltage adjustable linear regulator configured as a current source. The LR8 maintains 1.2V (its internal reference) between its OUT and ADJ pins. A shunt resistor R1 between ADJ and OUT sets the discharge current:

```
I_discharge = V_ref / R1 = 1.2V / 120Ω = 10mA (constant)
```

This is a **true constant-current** discharge regardless of capacitor voltage (within operating range), unlike resistive designs where current drops with voltage.

---

## Full Component List (from BOM + KiCAD)

| Ref | Value | Package | Function |
|---|---|---|---|
| U1 | LR8K4-G | TO-252-2 | HV adjustable linear regulator (CC source) |
| Q1 | IPD80R1K0CEATMA1 | TO-252-2 | N-ch MOSFET, 800V, series pass / voltage limiter |
| D3 | ABS10 | Diode_Bridge_Diotec  | Bridge rectifier — polarity protection |
| D4 | 200V 3W | D_SMB (handsoldering)| Zener — gate voltage clamp / voltage limiter |
| D2 | 10V 0.5W | SOD-123 | Zener — Q1 gate-source protection |
| D1 | LED | 1206 | Visual discharge indicator |
| R1 | 120Ω | 0805 | LR8 current-set shunt (10mA) |
| R2 | 100Ω 1W (KiCAD) / 1kΩ 1W (BOM) | 2512 | Protective fuse/series resistor |
| R3 | 100kΩ 1W | 2512 | Gate voltage divider (1/3) |
| R4 | 100kΩ 1W | 2512 | Gate voltage divider (2/3) |
| R5 | 100kΩ 1W | 2512 | Gate voltage divider (3/3) |
| C1 | 1µF | 0805 | LR8 output/ADJ filter |
| C2 | 100nF 250V | 1206 | Slows voltage rise, prevents transients |
| J1/J2  | Input pads | TestPoint D4.0mm | Probe connection |
| H1–H8  | M3 holes | MountingHole 3.2mm | PCB mounting |

> **Note:** R2 value discrepancy between KiCAD (100Ω 1W) and BOM (1kΩ 1W) — likely a revision difference. Either value functions as a protective series element.

---

## Circuit Topology

### 1. Polarity Protection — ABS10 Bridge Rectifier (D3)
- Input probes (J1/J2) feed into a full-bridge rectifier
- Output is always positive regardless of probe polarity
- Rated: 1kV, 1A — handles the full voltage range
- **Trade-off:** ~1.4V forward drop (2 diodes in series) — negligible at high voltage but dissipates heat

### 2. Voltage Limiting Stage — Q1 + D4 + R3/R4/R5
The LR8K4-G is rated for a maximum of **450V input**. To support 600V operation, a MOSFET source-follower stage limits the voltage seen by the LR8:

- **Q1 (IPD80R1K0CEATMA1):** 800V N-channel CoolMOS, very low RDS(on) (~1Ω)
  - Drain: connected to high-voltage rail (post-bridge, up to 600V)
  - Source: feeds LR8 input — clamped to ~200V max
  - Gate: driven by R3+R4+R5 voltage divider from input rail
- **D4 (200V zener):** In the gate drive network, clamps gate or Vds to limit LR8 input to ≤200V
- **D2 (10V zener):** Gate-source protection (Vgs clamp), prevents Vgs from exceeding 10V
- **C2 (100nF 250V):** Slows gate voltage rise, prevents transient spikes on power-up

**Operating behavior:**
- When Vcap > ~200V: Q1 absorbs excess voltage across Vds; LR8 sees ~200V
- When Vcap < ~200V: Q1 passes voltage through with minimal loss; LR8 follows input
- The 300kΩ divider (R3+R4+R5 in series) provides high-impedance gate bias with low power loss (~2mA at 600V)

### 3. Constant Current Source — U1 (LR8K4-G) + R1
- LR8K4-G configured with R1 (120Ω) between ADJ and OUT pins
- Internal Vref = 1.2V → I = 1.2V / 120Ω = **10mA constant**
- Current stays at 10mA for any input voltage within LR8 operating range

### 4. LED Indicator — D1
- LED is in the discharge current path
- Illuminates whenever current flows (capacitor voltage > LED Vf)
- Brightness decreases as voltage drops (current is constant, but at very low voltage the LED circuit changes behavior)
- No separate supply needed — powered directly from capacitor

### 5. Filtering — C1
- 1µF capacitor on LR8 output/ADJ node
- Stabilizes the regulation loop

---

## Discharge Performance

Constant current discharge follows:
```
dV/dt = I / C = 10mA / C
```

| Capacitor | Voltage | Discharge Time |
|---|---|---|
| 100µF | 600V | 6 seconds |
| 1000µF | 600V | 60 seconds |
| 10000µF | 600V | 600 seconds |
| 100µF | 400V | 4 seconds |

> **Key insight:** Discharge time scales linearly with capacitance. For the 1 minute target, this design supports up to **1000µF at 600V**. Larger caps will take longer.

**Power dissipation during discharge (worst case, Vcap = 600V):**
- Total: V × I = 600V × 10mA = **6W** (distributed between Q1 and LR8)
- Q1 handles: (Vcap - 200V) × 10mA = 400V × 10mA = 4W
- LR8 handles: 200V × 10mA = 2W
- Heat on aluminum PCB is negligible at these power levels

---

## Design Decisions & Trade-offs

| Decision | Rationale |
|---|---|
| LR8K4-G as CC source | Simple, elegant — just one IC + one resistor for constant current |
| MOSFET voltage limiter | Extends operation to 600V while protecting 450V-rated LR8 |
| Bridge rectifier D3 | Simple polarity protection without external supply |
| 3× series 100kΩ resistors | Distributes power dissipation vs. single resistor |
| Aluminum PCB | Better thermal performance vs. FR4 (requires hot-plate soldering) |
| 10mA current | Conservatively safe for probes and components at high voltage |

---

## Limitations Relative to Our Requirements

| Our Requirement | This Design | Gap |
|---|---|-----|
| Up to 1000V | Max 600V | LR8 + MOSFET stage would need redesign for 1000V |
| Under 1 min for large caps | ~60s for 1000µF | Fails for caps > 1000µF |
| No bridge rectifier | ABS10 bridge used | Conflicts with our preferred IC-based polarity protection |
| Digital voltmeter | Not included | Missing |
| 10:1 voltage divider | Not included | Missing |

---

## Applicable Ideas for Our Design

1. **LR8K4-G as current source:** Elegant approach — single IC sets constant current. But 450V limit means we need a MOSFET pre-stage for 1000V.
2. **MOSFET voltage limiter concept:** Using a CoolMOS MOSFET to absorb excess voltage above the regulator's rating is a valid technique to extend range. For 1000V, we'd need an 800V+ MOSFET and a higher zener voltage or different clamping strategy.
3. **Series resistor network (R3+R4+R5):** Distributing high-voltage bias resistors across multiple 1W components is a sound approach we should adopt.
4. **C2 for slowing voltage rise:** Good practice for protecting the IC from inrush transients.
5. **LED in discharge path:** Simple, no-power-required indicator — works for us as the high-voltage danger LED.

---

## Concerns for Adaptation to 1000V / Our Design

- **LR8K4-G is only rated to 450V input.** For 1000V, we cannot use it directly — even with a MOSFET pre-stage, we'd need Vgs clamping designed for a higher voltage swing, and the MOSFET Vds would see up to 800V.
- **Discharge current of 10mA may be insufficient** for large capacitors (>1000µF at 1000V would take >100 seconds).
- **Increasing current to 50–100mA** would require a different current-setting resistor (R1 = 1.2V / 50mA = 24Ω or 12Ω) but increases power dissipation proportionally.
- **Bridge rectifier vs. IC polarity protection:** The ABS10 solution is simple but our design spec requires IC-based protection.

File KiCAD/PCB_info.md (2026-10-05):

# PCB Design Notes — Capacitor Discharger

---

## Status — 2026-10-01: two boards, both script-generated

| Board | Files | Size | Copper | Parts | Height |
|---|---|---|---|---|---|
| **Single-sided, home etch** | `CapacitorDischarger_1S.*` + `fab_1s/` | **100 × 75 mm** (Bungard FEPCU-075) | B.Cu only, no jumpers | power resistors and small parts **standing** | ~40 mm (R_fast1 standing) |
| **2-layer, for a PCB fab** | `CapacitorDischarger.*` | **120 × 90 mm** (was 180 × 130) | both layers, autorouted | R_slow / R_fast / TF1 **flat**, small parts standing | ~25 mm |

Both pass DRC with schematic parity: **0 errors, 0 unconnected, 0 parity issues**. The only findings are 2 silkscreen notes where the R1/R5 outlines cross their milled slot, which is intended.

**Edit the scripts, not the KiCad files.** Run them from `KiCAD/`:

| Step | Command | Produces / checks |
|---|---|---|
| 0 | `python gen_3d.py` (needs CadQuery; only when a part changes) | `CapDis.3dshapes/`: true-size STEP bodies for the custom footprints (MKDS 5, CSO clips + fuse, Ohmite 45F/27J, SEFUSE, FMP300, HS-S01 on Q2) |
| 1 | `python gen_footprints.py` | `CapDis.pretty/`: custom footprints (F1 CSO clips, MKDS 5, Ohmite 45F/27J flat + standing, SEFUSE flat + standing, FMP300 standing, TO-220 with spread legs) |
| 2 | `python gen_kicad_sch.py` and `python gen_kicad_sch.py --project CapacitorDischarger_1S` | Two schematics: same circuit, footprints per board (`VARIANTS`) |
| 3 | `python check_kicad.py` | Netlist vs. `simulation/discharger.cir.tmpl`, pin by pin, plus ERC. **PASS.** |
| 4 | `"C:\Program Files\KiCad\10.0\bin\python.exe" gen_pcb.py --freerouting <freerouting-2.4.1.jar>` | 2-layer board: placement, slot, Q2/chain/GND pre-routes, Freerouting, DRC |
| 5 | `"C:\Program Files\KiCad\10.0\bin\python.exe" board_1s.py` | Single-sided board: placement and hand routes, DRC |

**Clearance rules (`hv_rules.py` → `*.kicad_dru`).**
- CLAUDE.md asks for ≥ 6 mm, based on 1 mm per 100 V. Each net pair gets **1 mm per 100 V of the worst-case difference it can actually see**. The worst case is taken over normal / reversed probes, F1 blown, TF1 open, and Q2 conducting at 85 V.
- **HV to GND/LV, probes and BRIDGE_P to anything: 6 mm.** HVp to the R_fast–TF1 node: 0.9 mm. Neighbouring chain nodes: 1.2–1.5 mm. Minimum 0.4 mm.
- The 2-layer board passes the same matrix to Freerouting as per-net classes plus `class_class` rules, so the router and the DRC agree.
- **One exception, the Q2 pin field.** Only drain-related items get 2.5 mm: the legs are bent out to 5.08 mm, and the part is rated 800 V between pins.

**Single-sided layout (100 × 75).**
- **Probes:** they enter at the top edge (J3 = PROBE_A, J4 = PROBE_B, both poles of each block on the same net).
- **Bridge and F1:** the bridge is four vertical diodes right below the probes, with the GND anodes on the outside. F1 sits below it, and its right clip is the HVp hub.
- **GND ring and pour:** a 2 mm GND ring along the board edge joins both bridge anodes and every return. This is what lets a single layer work without jumpers. A GND pour fills the rest of the bottom, using the voltage-aware rules (6 mm from HV copper, 0.4 mm from LV). It cuts the copper to etch to about 40 % for home etching, and gives a low-impedance return. `board_1s.py` fills it with `kicad-cli pcb drc --refill-zones --save-board`.
- **Track widths for home etching:** HV 2 mm, chains 1.2 mm, LV 1 mm. One exception: the D_LED1-K link is 0.8 mm, to keep 1.5 mm from R_LED4.
- **Top-right pocket:** R_fast1 standing, with TF1 standing 0.5 mm from its body (clamp them together). Q2 has the HS-S01 slipped onto its tab. The gate drive is LV and runs along the GND ring. R1 and R5 stand on their LV pad, with the bare HVp lead across a 17.5 × 3 mm slot.
- **Bottom-left:** R_slow1–5 standing, 2.3 mm air between bodies.
- **Bottom-right:** the divider and LED chains as staircases, then D_LED1, J6 (XH, front-panel LED cable) with its clamp zener D_clamp2, the divider bottom, D_clamp1 and J5.
- **Holes:** two M3 holes, H1 and H3. Use nylon screws; H2 and H4 don't fit on this board.
- **`fab_1s/`:**
  - `1S_B.Cu_exposure_1to1.pdf`: positive, as seen from the component side. Print 1:1 on transparency and lay it **toner side down** on the copper. Small drill marks help centring the drill.
  - `1S_films_1to1.pdf` (made by `gen_films.py`): A4 portrait, boards turned 90° and both at the top of the sheet. Page 1 has the B.Cu positive and negative, for toner transfer or photoresist. Page 2 has the B.Cu positive and the B.Mask film, where black = pad openings, for UV solder mask with `mechanical/mask_jig/`. Every image is seen from the component side: print at 100 % and lay it toner side down.
  - `1S_copper_components_1to1.pdf`: B.Cu positive plus the components (F.Fab + F.SilkS), the latter **mirrored**, for toner transfer onto the component side.
  - `1S_solder_mask_1to1.pdf`: two copies of the B.Mask image, to stack for a denser UV film.
  - Both are also made by `gen_films.py`.
  - `1S_assembly_top.pdf`: part references and outlines.
  - `CapacitorDischarger_1S.drl`: hole sizes.
  - `CapacitorDischarger_1S.step`: 3D board with parts, for designing the enclosure (`fab_2l/CapacitorDischarger_2L.step` for the 2-layer board).
- **The slot** is the outlined rectangle: cut it with a saw or rotary tool.

**2-layer layout (120 × 90).**
- **Same top-left block** as the single-sided board.
- **Fast path:** R_fast1 lies flat along the top, with TF1 under it (1 mm body gap) and Q2 tab-down with the HS-S01.
- **Gate drive:** packed right of Q2, with R1/R5 across a 23 × 3 mm slot.
- **Slow path:** the R_slow columns are flat, bottom-left.
- **Divider and LED chains:** the same staircases as on the single-sided board.
- **No copper pours.** Four M3 holes; use nylon screws.

**Check before building:**
- **MKDS 5/2-9.5:** which face the pin row is 4.6 mm from. This sets the wire-entry side.
- **Schurter CSO clip:** the 3.4 mm centre hole is plated as part of the pad; make sure it doesn't foul the clip.
- **HS-S01 on Q2 with the MST 220 insulator:** check it fits. It must not touch R4/C_byp2 (2-layer) or the GND ring (single-sided).
- Print the board 1:1 and lay the real parts on it.

---

## Q: Where does the HV part end? I have to separate it from the LV part, right? How would I do that on the PCB?

**HV zone** — high voltage AND significant current:
- Input terminals (HVp, GND)
- Slow path: R_slow1–5 (4.7kΩ × 5) — carry up to 25mA at 600V, get hot
- Fast path: R_fast (50Ω) → Q2 drain/source — up to 1.35A peak

**Boundary components** — high voltage on one pin, LV on the other (they straddle the slot):
- R1 (1MΩ) → Q1 base divider
- R5 (470kΩ) → gate clamp
- R_LED4 (100kΩ) — bottom of the LED chain (top pin ≈ ¼ of HVp, bottom ≈ 10 V)
- R_sig5 (100kΩ) — bottom of the signal divider (top pin ≈ ⅕ of HVp, bottom ≤ 60 mV)

R_LED1–3 and R_sig1–4 are entirely HV (their nodes sit at 120–480 V) and stay in the HV zone.

**LV zone** — everything downstream of the zeners:
- D9 clamps n_gate_top to 12V → Q1, R2, R3, R4, C_byp2
- R_sig_bot1/2 + D_clamp, J5 (2-pin, to the off-board PM-128)
- LED

The standard separation method is a **PCB slot (moat)**:

```
┌─────────────────────────────────────────────────┐
│  HV ZONE                                        │
│  [Input+]──[R_slow1-5]──[GND]──[Input−]         │
│       └──[R_fast]──[Q2 TO-220 + heatsink]──[GND]│
│                                                  │
│  R1, R5, R_LED4, R_sig5 (top pins)              │
│                                                  │
│══════════ PCB SLOT (≥1mm wide) ════════════════  │  ← enforces creepage ≥6mm
│                                                  │
│  LV ZONE                                        │
│  R1, R5, R_LED4, R_sig5 (bottom pins)           │
│  Q1, D9, J5 (DVM), LED, R_sig_bot1/2, D_clamp   │
└─────────────────────────────────────────────────┘
```

Key PCB rules:

| Rule | Value |
|---|---|
| Min trace clearance HV↔GND | 8mm |
| Min trace clearance HV↔LV signals | 6mm |
| Creepage (enforced by slot) | 6mm |
| HVp / GND return traces | 2mm min or copper pour |
| Q2 drain/source traces | 2mm min |
| Slow path resistors | standoff from PCB surface, no copper pour underneath |
| Spacing between consecutive resistor bodies | 3–5mm |
| Q2 | TO-220 with heatsink tab, mounting hole |

Practical layout tips:
1. Put input terminals and Q2 at the top edge — short HV current loop
2. Run the GND return as a copper pour directly under the discharge path
3. The four boundary resistors straddle the slot — top pin in HV zone, body across the gap, bottom pin in LV zone
4. Leave 3–5mm air gap between consecutive resistor bodies (R_slow1–5) — reduces creepage risk between adjacent HV nodes
5. No copper pour under resistor bodies — bare FR4 only; reduces surface tracking risk under high dissipation
6. R_sig_bot1/2 + D_clamp right next to J5 in the LV zone
7. DVM connector on the board edge, in LV zone only

---

## Q: The slot is an area where copper is missing, right? But then how do I pass GND from HV to LV?

The slot doesn't span the full board width — it's a targeted partial cut. GND routes **around the ends** of the slot:

```
                    board edge
┌──────────────────────────────────────────┐
│                                          │
│  HVp ══════════════════════              │
│                            ║             │
│  GND ══════════════════════╝ (HV zone)   │
│                     │                    │
│              ╔══════╝  ← GND goes        │
│              ║            around end     │
│   ┌──────────╨──────────────┐            │
│   │       S L O T           │  ← cut     │
│   └─────────────────────────┘            │
│              ║                           │
│              ╚══ GND (LV zone) ══════    │
│                                          │
│  LV signals ═════════════════════════    │
└──────────────────────────────────────────┘
```

- The slot interrupts the shortest surface path between HVp and LV signal traces → enforces ≥6mm creepage
- GND is at 0V so needs no separation from anything — routes freely around the slot end
- HVp never crosses the slot — stays entirely in the HV zone

---

## Q: Is the slot a physical cut in the board, or just a copper-free area? Is GND a copper pour? Does HVp reach the LV zone only through those resistors? Do LV signals have zero contact with HV?

**Slot** — physical cut through the PCB material (FR4 milled away), not just copper-free.  
Reason: surface contamination (flux residue, humidity, dust) allows current to creep along the PCB surface. A physical cut forces the creepage path to go around the slot edges through air, which is far more resistant. Copper-free alone is not sufficient.

**GND** — yes, copper pour for GND is the standard and correct approach. Individual traces for all other signals. This also minimises return-path inductance and resistance for the discharge current.

**HVp to LV** — all four boundary resistors bridge the gap (not just R1 and R5):
- R1 (1MΩ), R5 (470kΩ), R_LED4 (100kΩ), R_sig5 (100kΩ)

The HVp copper trace stays entirely in the HV zone. Each resistor's top pin solders to HVp in the HV zone, body spans the cut, bottom pin lands in the LV zone. Voltage is already reduced before the LV copper begins.

**LV signals** — zero copper contact with HVp. GATE, GATE_TOP, SIGOUT, LED_A are all LV-only nodes, entirely within the LV copper zone. The only thing crossing the slot is the physical body of those four resistors.

---

## Q: The slot does not have to cut the whole board, right? I want it to stay one piece.

Correct — the slot is a partial cut, not a full separation. It's a rectangle milled into the board, closed on both ends. The board stays physically one piece. GND copper connects around both ends of the slot.

```
┌────────────────────────────────────────┐
│  HVp ══════════════════                │
│                          ║             │
│  GND pour (HV zone)      ║             │
│                     ┌────╨─────────┐   │
│                     │   S L O T    │   │  ← partial cut, board stays one piece
│                     └──────────────┘   │
│  GND pour (LV zone)      ║             │
│                          ║             │
│  GATE, GATE_TOP, SIGOUT  ║             │
└────────────────────────────────────────┘
```

The only rule: shortest path from any HVp copper to any LV copper — measured along the board surface going around the slot — must be ≥6mm.

---

## Q: I have two 2-pin screw terminals to connect the banana sockets to the PCB. Should I use one connector for both probes (with a copper cut between pins), or two separate connectors?

Both screw terminals are in the HV zone — they are the PCB entry points for the two probes. Full chain:

```
Capacitor → banana plug → banana socket (on enclosure) → wire → PCB screw terminal
```

**Do not use one 2-pin connector for both probes.** Standard screw terminal pitch is 3.5–5mm — that puts 600V across a gap below the 6mm minimum. The connector body is not rated for that.

**Use two separate connectors**, one per probe, placed in the HV zone with ≥6mm copper clearance between the HV+ pad and GND pad on the PCB:

```
HV ZONE
┌────────────────────────────┐
│ [PROBE_A screw term]  HV+  │
│         ← ≥6mm →           │
│ [PROBE_B screw term]  GND  │
│                            │
│ discharge resistors, Q2... │
└────────────────────────────┘
```

Each connector uses one functional pin (the probe wire). The second pin of each 2-pin block can be left unused or used to daisy-chain to the discharge resistors.

---

## Q: Is it OK to link HV and LV to the same GND?

Yes — correct and intentional for this design. The LV section is **not isolated**: it derives all power directly from HVp through resistive dividers. All sections (slow path, fast path, gate drive, LED, signal divider) share the same GND, which is the negative terminal of the capacitor under test.

The PM-128 **input** (VIN / IN GND via J5) must share GND with the divider for the reading to be correct. Its **supply** is the opposite: the PM-128 needs separate supply and input grounds, so the 9 V source (BT1, on the panel DC jack) floats and never touches circuit GND.

The one real concern: PCB GND is at whatever potential the capacitor's negative terminal is at relative to earth. Touching the PCB while probing is dangerous — handled by enclosure design, not circuit isolation. The probes are the only user-touch points and are rated 1000V.

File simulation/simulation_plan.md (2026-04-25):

# Simulation Plan — 600 V Capacitor Discharger

## Context

The schematic in `implementation_claude.md` and `blocks/full_schematic.svg` describes an adaptive 600 V capacitor discharger with five interacting analog blocks (slow R-string, MOSFET fast path with NPN threshold detector, LED danger indicator, 6:1 DVM signal divider, parasitic 15 V DVM Vcc dropper). Before committing to PCB, we want a transient simulation that proves every operating regime works: slow-only above 71 V, fast-path takeover below 71 V, LED on/off at the ~10 V cutoff, DVM signal tracking 1/6 of V_cap, and DVM Vcc losing regulation below V_cap ~195 V (Zener cutout) and DVM going dark below V_cap ~27 V. The simulation must also let us read instantaneous current through every branch so we can verify resistor stress numbers in `bom.py` and the timing claims in `implementation_claude.md` (e.g. 50 s for 1 mF / 600 V).

The project has **no existing SPICE infrastructure** (verified — no `.cir`/`.sp`/`.asc`/PySpice). All deliverables are new.

## Tooling decision

- **Engine: ngspice** — already shipped with KiCad 10 (as `ngspice.dll`) and also available standalone. Two ways to run; pick whichever is more convenient:
  - **(A) Standalone ngspice CLI (preferred for automated batch runs).** Install with `winget install ngspice` or `scoop install ngspice`, then `ngspice -b sim.cir`. KiCad's bundled DLL is **not** a standalone executable on Windows — there is no `ngspice.exe` inside `C:\Program Files\KiCad\10.0\bin\`, so KiCad cannot drive headless batch runs.
  - **(B) KiCad 10 Simulator GUI** (interactive, no extra install). See "Running in KiCad" below.
- Output: `wrdata` to dump CSV; post-process in Python with `numpy` + `matplotlib`. PySpice is **not** used (extra dependency for no gain since ngspice CLI suffices).
- **Models** ship in-tree as `simulation/models.lib`:
  - `1N4007`: `.model D BV=1000 IS=1e-9 N=2`.
  - `2N3904`: standard Gummel-Poon `.model` (well-known parameter set).
  - `STF7NM80`: vendor SPICE model from ST (download `STF7NM80.lib`); fallback = generic 800 V N-MOSFET subckt with `Vto=4 Kp=2 Rds=1.7`.
  - Zeners (BZX85C12 12 V, BZX55C8V2 8.2 V, 1N4744A 15 V): `.model DZxx D BV=Vz IBV=5mA N=1.5`.
  - LED: `.model DLED D IS=1e-20 N=2 Vj=2.0` to give Vf ≈ 2 V at 2 mA.
  - 10 µF electrolytic: ideal `C` (ESR irrelevant at these frequencies).

## Architecture

```
simulation/
  simulation_plan.md      # this file
  models.lib              # all .model / .subckt definitions
  discharger.cir.tmpl     # parameterised netlist with {{V0}} {{CDUT}} placeholders
  discharger_dc.cir.tmpl  # DC sweep variant for scenario G
  run_sim.py              # renders template, runs ngspice, parses .csv, plots, asserts
  scenarios.py            # list of (name, V0, Cdut, expected) tuples
  results/<scenario>/
      sim.cir             # rendered netlist actually fed to ngspice
      out.csv             # time + node voltages + branch currents
      plot.png            # multi-panel plot
      summary.txt         # PASS/FAIL line per assertion + key timestamps
  README.md               # how to run + how to read results
```

## Netlist structure (`discharger.cir.tmpl`)

The reverse-polarity bridge is a no-op for simulation purposes (DUT is connected straight; bridge polarity tested only in scenario F). All measurement points use **0 V voltage sources as ammeters** so currents are exact and easy to extract.

```
* 600V Capacitor Discharger — transient
.include models.lib
.param V0={{V0}} CDUT={{CDUT}}

* DUT capacitor with initial condition
C_dut HVp 0 {CDUT} IC={V0}

* --- Slow path (5 × 4.7 k) ---
V_islow HVp n_slow1 0           ; ammeter: I(V_islow) = slow current
R_slow1 n_slow1 n_slow2 4.7k
R_slow2 n_slow2 n_slow3 4.7k
R_slow3 n_slow3 n_slow4 4.7k
R_slow4 n_slow4 n_slow5 4.7k
R_slow5 n_slow5 0       4.7k

* --- Fast path (R_fast → Q2 drain → source → GND) ---
V_ifast HVp n_rfast 0
R_fast  n_rfast n_drain 50
M_Q2    n_drain n_gate 0 0 STF7NM80
* gate drive: pull-up R5 from HVp to gate, clamped by D9 to 12 V; Q1 collector pulls gate low
R5      HVp n_gate_top 470k
D_D9    0   n_gate_top DZ12               ; clamps n_gate_top at 12 V (cathode at top, BV=12)
R4      n_gate_top n_gate 100
* Q1 NPN: base from R1/R2 divider via R3, collector to n_gate_top, emitter to GND
R1      HVp n_base_top 1Meg
R2      n_base_top 0   10k
R3      n_base_top n_q1b 100k
Q1      n_gate_top n_q1b 0 Q2N3904

* --- LED danger indicator ---
V_iled  HVp n_led1 0
R_LED1  n_led1 n_led2 100k
R_LED2  n_led2 n_led3 100k
R_LED3  n_led3 n_dled 100k
D_DLED  n_dled n_led_a DZ8V2              ; 8.2 V Zener, reversed in chain
D_LED1  n_led_a 0      DLED               ; red LED, Vf ≈ 2 V

* --- DVM signal divider 6:1 ---
V_isig  HVp n_sig1 0
R_sig1  n_sig1 n_sig2 100k
R_sig2  n_sig2 n_sig3 100k
R_sig3  n_sig3 n_sig4 100k
R_sig4  n_sig4 n_sig5 100k
R_sig5  n_sig5 n_sigout 100k
R_sigb  n_sigout 0     100k                ; node n_sigout is the DVM signal probe

* --- DVM Vcc dropper + 15 V Zener + smoothing cap ---
V_idrop HVp n_drop1 0
R_drop1 n_drop1 n_drop2 15k
R_drop2 n_drop2 n_drop3 15k
R_drop3 n_drop3 n_drop4 15k
R_drop4 n_drop4 n_vcc   15k
D_DVcc  0       n_vcc   DZ15
C_Vcc   n_vcc 0 10u
* Optional resistive load to model DVM current draw (≈3 mA typical)
R_dvm_load n_vcc 0 5k

.ic V(HVp)={V0} V(n_vcc)=0

.tran 10m 120 uic                          ; 0–120 s, 10 ms step
.save V(HVp) V(n_gate) V(n_gate_top) V(n_sigout) V(n_vcc) V(n_led_a)
.save I(V_islow) I(V_ifast) I(V_iled) I(V_isig) I(V_idrop)

.control
run
wrdata results/{{NAME}}/out.csv
+   V(HVp) V(n_gate) V(n_gate_top) V(n_sigout) V(n_vcc) V(n_led_a)
+   I(V_islow) I(V_ifast) I(V_iled) I(V_isig) I(V_idrop)
quit
.endc
.end
```

## Scenarios (`scenarios.py`)

| Name | V0 | C_dut | Purpose | Expected (assertions) |
|---|---|---|---|---|
| `A_full_600V_1mF` | 600 V | 1 mF | full sweep, all regimes | t(V<71V) ≈ 31 s (not 50 s — parallel branches add ~15 mA load, effective R ~15 kΩ not 23.5 kΩ); t(V<10V) < 42 s; LED off ≤ ~10.2 V; max I_slow ≈ 25.5 mA; max I_fast > 1 A; V(n_sigout)/V(HVp) ≈ 1/6 within 1 % from 600 V down to 30 V |
| `B_mid_300V_470uF` | 300 V | 470 µF | typical hobby cap | LED on until V_cap ~10 V; t(V<71V) ≈ 10 s; V(n_vcc) ≥ 5 V while V(HVp) > 30 V (Zener regulates at 15 V above ~195 V; below that Vcc tracks V_cap/13; DVM goes dark at V_cap ~27 V by design) |
| `C_mid_100V_100uF` | 100 V | 100 µF | brief slow segment then fast | slow segment < 1 s; fast path turns on near t≈0.7 s; total to 10 V < 2 s |
| `D_low_50V_100uF` | 50 V | 100 µF | fast-path-only from t=0 | I_fast > 0 at t=0+; gate near 12 V; total to 10 V < 1 s |
| `E_below_LED_8V_100uF` | 8 V | 100 µF | LED stays OFF | I(V_iled) < 1 µA throughout; V(n_vcc) < 5 V (DVM dark) |
| `F_steady_state_600V` | 600 V | 100 mF (≈ rail) | quasi-steady probes | at t=1 s: I_slow=25.5 mA ±5%; I_drop=9.75 mA ±5%; V(n_vcc)=15 V ±0.5 V; V(n_sigout)=100 V ±2 V; V(n_gate)<1 V (Q2 off) |
| `G_threshold_sweep` | (DC sweep, not transient) | n/a | confirm 71 V switch point | DC sweep V(HVp) 0→200 V: V(n_gate) flips from ~12 V to <1 V at V(HVp) = 71 V ±3 V |

Scenario G uses a separate `.dc` analysis netlist (`discharger_dc.cir.tmpl`) — same topology but `.tran` swapped for `.dc V_HVp 0 200 0.5`, and `C_dut` replaced by a stimulus voltage source `V_HVp HVp 0 0`.

## Meter / probe placement (rationale)

| Quantity | How read | Conversion |
|---|---|---|
| V_cap (HV+) | `V(HVp)` | direct volts |
| Slow path I | `I(V_islow)` | direct A; P_total = V·I, per-resistor = I² × 4.7 k |
| Fast path I (through MOSFET) | `I(V_ifast)` | direct A; instantaneous P_R_fast = I² × 50 |
| LED chain I | `I(V_iled)` | direct; LED on iff > 50 µA |
| DVM signal divider I | `I(V_isig)` | direct; divider loading negligible vs DVM input |
| DVM Vcc dropper I | `I(V_idrop)` | direct; per-resistor P = I² × 15 k |
| Q2 gate state | `V(n_gate)` | <1 V = off, ~12 V = on |
| DVM signal output | `V(n_sigout)` | should equal V(HVp)/6 |
| DVM Vcc rail | `V(n_vcc)` | 15 V Zener-regulated while V_cap > ~195 V; tracks V_cap/13 below that; drops below 5 V (DVM dark) at V_cap ~27 V |
| LED anode (post-Zener) | `V(n_led_a)` | ≈ V_f ≈ 2 V when on, 0 when off |

Placing each ammeter as a **0 V source at the head of the branch** (between HVp and the first element of that branch) means the per-branch current is read directly with no extra arithmetic — Sonnet doesn't need to subtract anything.

## Running the simulation

### Option A — Standalone ngspice CLI (recommended for batch / automation)

ngspice 46 is already installed at `E:\Catalin\Work\Electronics\NGSpice_46\bin\ngspice.exe`.

Verify it works:
```
"E:\Catalin\Work\Electronics\NGSpice_46\bin\ngspice.exe" -v
```

`run_sim.py` must invoke it with the full path (it is not on the system PATH):
```python
NGSPICE = r"E:\Catalin\Work\Electronics\NGSpice_46\bin\ngspice.exe"
```

1. Run all scenarios:
   ```
   cd simulation
   python run_sim.py --all
   ```
   `run_sim.py` renders each `*.cir.tmpl` to `results/<name>/sim.cir`, then invokes `ngspice -b results/<name>/sim.cir`, parses `out.csv`, runs assertions, writes `summary.txt` and `plot.png`.
3. Run a single scenario:
   ```
   python run_sim.py A_full_600V_1mF
   ```
4. Inspect: open `results/<name>/plot.png` and `summary.txt`.

### Option B — KiCad 10 built-in Simulator (interactive GUI)

KiCad 10 ships ngspice as a DLL inside `C:\Program Files\KiCad\10.0\bin\ngspice.dll` and exposes it via the schematic editor's Simulator tool. Use this when you want to eyeball waveforms without leaving KiCad, or if you don't want to install standalone ngspice.

Two ways to load our netlist into KiCad's simulator:

**B1. Load a hand-written .cir directly (fastest)**

1. Open KiCad → **Tools → Simulator** (or open *any* schematic and use **Inspect → Simulator** — KiCad needs a schematic context window even to run a raw netlist).
2. In the Simulator window: **File → Open Workbook…** is for `.wbk` only. Instead use **Simulation → Settings…** *or* edit the netlist directly: click the **"Custom"** tab in Simulation Command, paste the contents of `simulation/results/<name>/sim.cir` (already rendered by `run_sim.py`), and uncheck "Generate netlist from schematic" so the simulator uses your custom netlist verbatim.
   - Alternative: launch KiCad's bundled ngspice in interactive mode from a terminal — it isn't on PATH, but you can call it via Python's `ctypes` against the DLL. Not worth it; just install standalone ngspice (Option A) if you want CLI.
3. Click **Run**. Add signals to the plot via **Add Signals…** — enter `V(HVp)`, `V(n_gate)`, `V(n_sigout)`, `V(n_vcc)`, `I(v_islow)`, `I(v_ifast)`, etc. (KiCad lower-cases vsource names).
4. Cursors: right-click on a trace → **Add Cursor** to read out (t, V) pairs. Use this to measure t(V_HVp = 71 V) and t(V_HVp = 10 V) for the timing assertions.
5. Export: **File → Export Plot as CSV** to compare with `out.csv` from Option A.

**B2. Build a KiCad schematic and let KiCad netlist it**

Only worth doing if you also want a KiCad-native schematic deliverable. Steps: place SPICE-modeled symbols (the `pspice` library has `R`, `C`, `D`, `Q_NPN`, `MOS_N` with editable model fields), wire them to match `discharger.cir.tmpl`, set initial condition on `C_dut` via `Symbol Properties → Simulation Model → Initial Condition (IC)`, and add a `.tran 10m 120 uic` directive via **Simulation → Settings**. Then **Run**. This duplicates information already in the `.cir` template — skip unless we decide to maintain the schematic in KiCad as a second source of truth.

**Common pitfalls in KiCad's simulator:**
- KiCad's simulator quietly **lower-cases all node and reference names**. `I(V_islow)` becomes `i(v_islow)`. Match case in plot expressions.
- `wrdata` works inside `.control` blocks but writes relative to KiCad's working directory (usually the project folder), not the netlist directory. Use absolute paths if you need scripted output from inside KiCad.
- KiCad 10 simulator does **not** support `.include` with relative paths the way the CLI does — if `models.lib` isn't found, copy its contents inline or use an absolute path.
- For long transients (scenario A is 120 s simulated time with 10 ms step = 12 000 points), KiCad's plotter is fine but the GUI may stutter on pan/zoom; export CSV and plot in Python if it gets sluggish.

### Sanity check (either option)

Smoke-test the Zener and MOSFET models in isolation **before** running the full discharger:

```
* zener_test.cir
.include models.lib
V1 1 0 PWL(0 0 1 20)
R1 1 2 1k
D1 0 2 DZ12
.tran 1m 1
.control
run
print V(2)
.endc
.end
```

Should clamp `V(2)` at ≈ 12 V once V1 > 12 V. Repeat for `DZ8V2`, `DZ15`, `DLED`. Five-line tests per device take <1 s and catch model errors before they confuse the main simulation.

## Critical files to be created

- `simulation/models.lib` — all device models in one file
- `simulation/discharger.cir.tmpl` — main transient netlist (above)
- `simulation/discharger_dc.cir.tmpl` — DC sweep variant for scenario G
- `simulation/scenarios.py` — table above as Python data, plus per-scenario assertion lambdas
- `simulation/run_sim.py` — for each scenario: render template → write `.cir` to `results/<name>/sim.cir` → `subprocess.run(["ngspice", "-b", "sim.cir"])` → load `out.csv` with `numpy.loadtxt` → compute derived quantities → run assertions → write `summary.txt` → produce `plot.png` (3 panels: V_cap & V_gate & V_sigout vs t; I_slow & I_fast vs t; I_led & I_drop & V_vcc vs t) → print PASS/FAIL line.
- `simulation/README.md` — short version of the "Running the simulation" section above, plus how to add a new scenario.

## Reuse from existing project

- `bom.py` — Sonnet should `from bom import BOM` and pull resistor / Zener / cap values from there rather than hard-coding them, so a BOM change auto-propagates to the netlist (mirror the same single-source-of-truth pattern as `gen_full_schematic.py`).
- Layout convention (HV section / LV section, grouped branches) from `blocks/gen_full_schematic.py` — keep the same grouping in the netlist comments so a reader can map netlist ↔ schematic.

## Execution order for Sonnet

1. Install ngspice (Option A); verify with `ngspice -v`. *Or* confirm KiCad 10 is installed if going Option B.
2. Create `simulation/models.lib` with the five device models above. Smoke-test each with the 5-line standalone netlist shown above before integrating.
3. Write `discharger.cir.tmpl` and run scenario **F (steady state, 100 mF rail) first** — easiest assertions, validates the topology before any timing math is involved.
4. Run scenario **G (DC threshold sweep)** — validates the Q1/Q2 gate logic in isolation.
5. Run **A → E** in order; each is a strictly easier transient than A.
6. Generate plots; eyeball them against the expected curves in `implementation_claude.md` §2 (timing) and §5 (LED cutoff).
7. Write `summary.txt` per scenario, plus a top-level `simulation/results/RESULTS.md` aggregating all PASS/FAIL.

## Verification

End-to-end test = `python simulation/run_sim.py --all` exits 0 and every scenario shows PASS in `RESULTS.md`. Spot-check expected against `implementation_claude.md`:

- Scenario A: time-to-71 V is **~31 s** (sim confirmed), not the 50 s single-path estimate. The 50 s figure assumes only the 23.5 kΩ slow path; in practice the LED chain, DVM signal divider, DVM Vcc dropper, and base divider add ~15 mA of parallel load, reducing effective R to ~15 kΩ and τ to ~15 s.
- Scenario F: I_slow = 600 V / 23.5 kΩ = **25.5 mA**; I_drop = (600−15)/60 kΩ = **9.75 mA**; per-resistor stresses match `bom.py` notes within 5 %.
- Scenario G: threshold at V_th = 0.7·(1 M+10 k)/10 k = **70.7 V** ±3 V tolerance for V_BE variation.

If any of those three numerical anchors disagrees with sim by > 10 %, stop and re-check models before running the rest.

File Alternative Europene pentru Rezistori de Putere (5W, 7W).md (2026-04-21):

# Alternative Europene pentru Rezistori de Putere (5W, 7W)

Utilizatorul caută rezistori de putere de 5W și 7W, non-ceramici (similari cu Ohmite WN/WH - military grade, molded wirewound), disponibili la distribuitori din Europa.

## 1. Vishay Seria RS (Military Grade / Precision)
- **Descriere**: Rezistori bobinați de precizie, înveliți în silicon (nu ceramici), echivalenți cu standardele militare (MIL-PRF-26).
- **Disponibilitate**: 
  - **TME.eu**: Disponibili sub brandul Vishay.
  - **Mouser Europe**: Stoc mare pentru seria RS.
  - **Farnell**: Disponibili (de verificat stocul specific pentru 5W/7W).
- **Modele**: RS005 (5W), RS007 (7W).

## 2. Welwyn (TT Electronics) Seria WHS
- **Descriere**: Rezistori bobinați de putere, cu înveliș ignifug (flameproof coating), performanțe ridicate.
- **Disponibilitate**:
  - **TME.eu**: Stoc semnificativ pentru seria WHS (ex: WHS5, WHS7).
  - **Farnell**: Disponibilitate bună în România/Europa.
- **Modele**: WHS5 (5W), WHS7 (7W).

## 3. Arcol (Ohmite) Seria RWS
- **Descriere**: Rezistori de precizie bobinați, optimizați pentru montare THT, profil redus.
- **Disponibilitate**:
  - **TME.eu**: Arcol este un brand european (UK) acum parte din Ohmite, foarte prezent pe TME.
  - **Mouser Europe**: Stoc disponibil.

## 4. Ohmite Seria WH/WN (Originalul)
- **Disponibilitate**: 
  - **Mouser Europe**: Este principala sursă pentru seria originală WH/WN. Deși Mouser este un distribuitor global, site-ul lor european (eu.mouser.com) gestionează livrările către România, incluzând adesea taxele vamale în prețul final sau oferind transport gratuit peste o anumită valoare (aprox. 50 EUR).
  - **TME.eu**: Oferă o gamă largă de produse **Arcol/Ohmite**. Arcol (brand britanic achiziționat de Ohmite) produce serii echivalente care sunt stocate direct în Europa (Polonia), oferind cel mai rapid timp de livrare pentru România.
  - **Farnell România**: Are în stoc anumite valori pentru seria WH, dar stocul este mai limitat comparativ cu Mouser.

## Distribuitori Recomandați în Europa:
1. **TME (Transfer Multisort Elektronik)** - tme.eu (Depozit în Polonia, livrare rapidă în România).
2. **Farnell România** - ro.farnell.com (Livrare din UK/Belgia).
3. **Mouser Europe** - eu.mouser.com (Livrare rapidă, taxe incluse pentru România la comenzi peste o anumită sumă).
4. **RS Components România** - ro.rsdelivers.com.

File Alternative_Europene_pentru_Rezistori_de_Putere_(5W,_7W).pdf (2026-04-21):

# Alternative Europene pentru Rezistori de Putere (5W, 7W)

Utilizatorul caută rezistori de putere de W și W, non-ceramici (similari cu Ohmite WN/WH -military grade, molded wirewound), disponibili la distribuitori din Europa.

## . Vishay Seria RS (Military Grade / Precision)

- Descriere: Rezistori bobinați de precizie, înveliți în silicon (nu ceramici), echivalenți cu

standardele militare (MIL-PRF-).
- Disponibilitate:
- TME.eu: Disponibili sub brandul Vishay.
- Mouser Europe: Stoc mare pentru seria RS.
- Farnell: Disponibili (de verificat stocul specific pentru W/W).
- Modele: RS (W), RS (W).

## . Welwyn (TT Electronics) Seria WHS

- Descriere: Rezistori bobinați de putere, cu înveliș ignifug (flameproof coating),

performanțe ridicate.
- Disponibilitate:
- TME.eu: Stoc semnificativ pentru seria WHS (ex: WHS, WHS).
- Farnell: Disponibilitate bună în România/Europa.
- Modele: WHS (W), WHS (W).

## . Arcol (Ohmite) Seria RWS

- Descriere: Rezistori de precizie bobinați, optimizați pentru montare THT, profil redus.
- Disponibilitate:
- TME.eu: Arcol este un brand european (UK) acum parte din Ohmite, foarte prezent

pe TME.
- Mouser Europe: Stoc disponibil.

## . Ohmite Seria WH/WN (Originalul)

- Disponibilitate:

- Mouser Europe: Este principala sursă pentru seria originală WH/WN. Deși Mouser

este un distribuitor global, site-ul lor european (eu.mouser.com) gestionează livrările către România, incluzând adesea taxele vamale în prețul final sau oferind transport gratuit peste o anumită valoare (aprox. EUR).
- TME.eu: Oferă o gamă largă de produse Arcol/Ohmite. Arcol (brand britanic

achiziționat de Ohmite) produce serii echivalente care sunt stocate direct în Europa (Polonia), oferind cel mai rapid timp de livrare pentru România.
- Farnell România: Are în stoc anumite valori pentru seria WH, dar stocul este mai

limitat comparativ cu Mouser.

## Distribuitori Recomandați în Europa:

. TME (Transfer Multisort Elektronik) - tme.eu (Depozit în Polonia, livrare rapidă în România).

. Farnell România - ro.farnell.com (Livrare din UK/Belgia).

. Mouser Europe - eu.mouser.com (Livrare rapidă, taxe incluse pentru România la comenzi peste o anumită sumă).

. RS Components România - ro.rsdelivers.com.

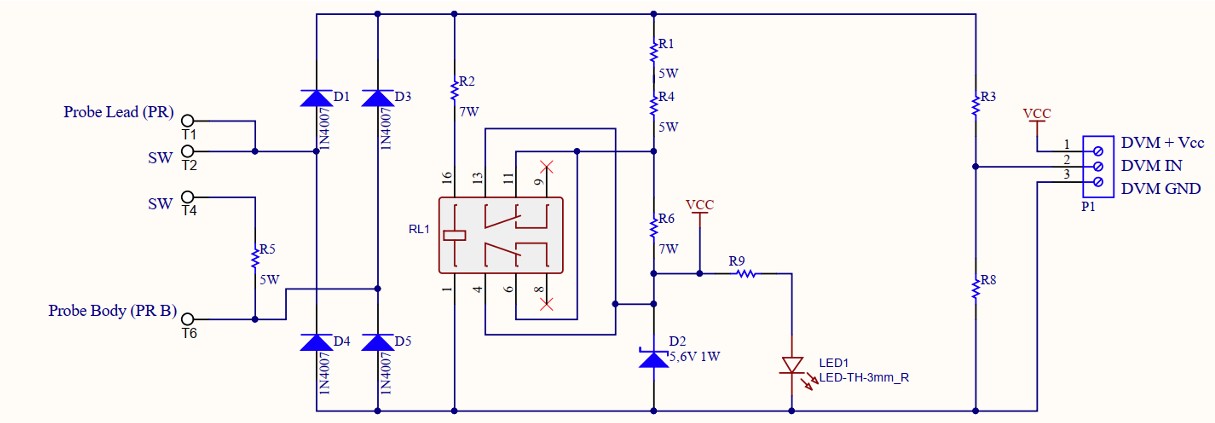
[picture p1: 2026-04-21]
Pieraisa.jpg

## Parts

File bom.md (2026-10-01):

# Bill of Materials — 600V Capacitor Discharger

> Generated by `bom.py`. Edit that file to update this document.

## To Buy

| Ref(s) | Qty | Description | Part Number / Suggestion |
|---|-----|---|---|
| F1 | 1 | Fuse, 2 A, 1000 VDC, gR (super-fast, full-range), 30 kA breaking capacity, ceramic, 10.3×38 mm cartridge | ESKA 1038820  (TME 1038820, in stock 2026-10-01; alt DF ELECTRIC 491602, Littelfuse KLKD002.T) — buy 2 (1 spare) |
| — | 2 | Fuse clip, PCB through-hole solder, for 10.3×38 mm cartridge fuses, silver-plated copper, 1500 VAC/VDC, 32 A | SCHURTER 0751.0506  (CSO, TME 0751.0506) — 2 per fuse |
| TF1 | 1 | Thermal cutoff (thermal fuse), one-shot, organic-pellet type, Tf 133 °C, 15 A / 250 VAC, metal case, axial leads | SCHOTT SEFUSE SF129R0  (TME SF129R0; alt AUPO BF133) — buy 2 (1 spare) |
| LED1 | 1 | LED, red, 5 mm (T-1¾), low-current type (specified at 2 mA), Vf ≈ 1.8–2 V, diffused, THT | HLMP-4700  (Broadcom, low-current red, TME HLMP-4700)  — fallback: kit 5 mm red LED (ComponentsDB) |
| R_sig_bot1, R_sig_bot2 | 2 | Resistor, metal film, 100 Ω, 0.6 W, ±1%, 50 ppm/°C, axial THT | YAGEO MF0207FTE52-100R  (TME MF0207FTE-100R; any 100 Ω 1% metal film fits) |
| DVM1 | 1 | Digital panel meter, 3½-digit LCD, 13 mm digits, 199.9 mV full scale, input >100 MΩ, ±0.5 %, 7–11 V DC supply at ~1 mA, decimal point by wire jumper, 68×44 mm | AXIOMET PM-128  (TME PAN.PM128) — 1 needed, 2nd optional as a spare |
| — | 1 | Enclosure, 3D-printed PETG (not PLA), 106.8 × 132.8 × 52 mm: base + screwed top cover, holding the single-sided PCB, PM-128, front-panel LED, 2 banana sockets and the 9 V DC jack | Self-printed — mechanical/enclosure/ (gen_enclosure.py → Enclosure_base / Enclosure_cover .stl/.step) |
| — | 1 | 4× M3 heat-set insert (Ø4.0 hole, ≤ 6 mm long), 4× M3×10 socket-head screw (cover), 2× M3×12 nylon screw + 2× M3 nut (PCB H1/H3), 4 stick-on rubber feet | Any — M3 hardware, PMMA rod Ø5 |

## Sourced (In Hand)

| Ref(s) | Qty | Part Number |
|---|-----|---|
| D1, D2, D3, D4 | 4 | 1N4007  (Diotec, Mouser 637-1N4007) |
| R_slow1, R_slow2, R_slow3, R_slow4, R_slow5 | 5 | 45F4K7E  (Ohmite, Mouser 588-45F4K7E) |
| R_fast | 1 | 27J50RE  (Ohmite, Mouser 588-27J50RE) |
| Q2 | 1 | STP10NK80Z  (alt: STF7NM80, IXTP2N80) |
| — | 1 | TO-220 insulating mounting set — Fischer Elektronik MST 220  (ComponentsDB; alt: Stonecold TO220-SET) |
| HS1 | 1 | Stonecold HS-S01  (TME, ComponentsDB comp_225 — 1 left) |
| R4 | 1 | RN60D1000FB14  (Vishay, Mouser 71-RN60D-F-100) |
| R5 | 1 | FMP300FRF73-470K  (YAGEO, Mouser 603-FMP300FRF73-470K) |
| D9 | 1 | BZX85C12  (onsemi, Mouser 512-BZX85C12) |
| Q1 | 1 | MPSA42-FAI  (onsemi, TME MPSA42-FAI) |
| R1 | 1 | FMP300FRF73-1M  (YAGEO, Mouser 603-FMP300FRF73-1M) |
| R2 | 1 | MFR-25FTE52-10K  (YAGEO, Mouser 603-MFR-25FTE52-10K) |
| R3 | 1 | MFR-25FTE52-10K  (YAGEO, Mouser 603-MFR-25FTE52-10K) |
| R_LED1, R_LED2, R_LED3, R_LED4 | 4 | MF006FF1003A50 |
| D_LED | 1 | BZX55C8V2-TAP  (Vishay, Mouser 78-BZX55C8V2-TAP) |
| J6 | 1 | B2B-XH-A + XHP-2  (ComponentsDB comp_156, XH2.54 connector kit) |
| D_clamp2 | 1 | BZX55C8V2-TAP  (ComponentsDB comp_126, same as D_LED) |
| R_sig1, R_sig2, R_sig3, R_sig4, R_sig5 | 5 | MF006FF1003A50 |
| D_clamp | 1 | 1N4007  (spare from the bridge batch, ComponentsDB) |
| J5 | 1 | TE narrow flat pin header 2P  (ComponentsDB) |
| BT1 | 1 | Mufa DC mama 5.5x2.1 (ComponentsDB comp_231, same jack as SursaTensiune J5) |
| C_byp2 | 1 | K104K10X7RF5UH5 |
| J1 | 1 | SLB4-G-21 |
| J2 | 1 | SLB4-G-22 |
| J3, J4 | 2 | MKDS5/2-9.5 |
| — | 1 | Silicone wire 1.0 mm², red + black — LAPP 1249584 (red) + 1249524 (black)  (TME HEAT180SIF-A1.0RD/BK, ComponentsDB) |
| — | 1 | CT2900A test leads — CT2900A |

## Sourced — Not Used in Current Revision

| Part Number | Description | Notes |
|---|---|---|
| 647-10ABEP, 637-10ABPE  (Wakefield, Mouser order 39007986) | Heatsinks, TO-220, board-mount with solder pins (3.8 / 5.8 °C/W) | Too big for the 100 × 75 / 120 × 90 mm boards; replaced by the HS-S01. |
| Voltmetru de panou 0-100V cu 3 fire  (ComponentsDB) | Digital panel voltmeter module, 0–100 V, 3-wire, LED display, 5–30 V supply, 12–15 mA, input 0.525 MΩ (measured) | Replaced 2026-10-01 by the PM-128: 0.525 MΩ input loaded the 6:1 divider beyond the trimmer's range, display read V/6, 12–15 mA battery drain. |
| 3296W-1-103LF  (Bourns, TME 3296W-1-103LF) | Potentiometer, cermet trimmer, 10 kΩ, 25-turn, 0.5 W, THT | Was R_cal (DVM trim); removed 2026-10-01 — the PM-128 is calibrated with its own trimmer R4. |
| EEAGA1E100H, K104K10X7RF5UH5, B2B-XH-A | C_Vcc (EEAGA1E100H), C_byp1 (K104K10X7RF5UH5), former J6 (B2B-XH-A; ref J6 now reused for the LED cable) | Were the battery-fed Vcc rail on the PCB; removed 2026-10-01 — the floating battery now wires straight to the PM-128. |
| MOF3WS-15K | Resistor, metal oxide, 15 kΩ, 3 W, ±5%, 500 V, Ø5×15 mm, axial THT | 20 pcs sourced. Was R_drop1–4 (DVM Vcc dropper); removed 2026-07-29 — DVM (12–15 mA measured) is battery-powered now. |
| 1N4744A-T50A  (onsemi, Mouser 512-1N4744AT50A) | Zener diode, 15 V, 1 W, DO-41, THT | Was D_Vcc (parasitic 15 V shunt regulator); removed 2026-07-29 together with the dropper. |
| MF006FF8203A50 | Resistor, metal film, 820 kΩ, 0.6 W, ±1%, 250 V, axial THT | 100 pcs sourced. Not used in current design revision. |
| MF0207FTE-1M8 | Resistor, metal film, 1.8 MΩ, 0.6 W, ±1%, 350 V, axial THT | 5 pcs sourced. Not used in current design revision. |
| MBB0207VC2204FCT00 | Resistor, metal film, 2.2 MΩ, 0.6 W, ±1%, 350 V, axial THT | 10 pcs sourced. Not used in current design revision. |
| 3386P-1-103LF  (Bourns, TME 3386P-1-103LF) | Potentiometer, cermet trimmer, 10 kΩ, 1-turn, 0.5 W, THT | 5 pcs sourced. Single-turn variant of R_cal trimmer. Not placed — 3296W (25-turn) used instead for finer adjustment. |
| LM393AP | IC, dual comparator, 300 ns, 2–30 V supply, DIP-8, THT | 3 pcs sourced. Not used — NPN transistor threshold detector chosen instead. |

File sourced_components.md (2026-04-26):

# Sourced Components

## Previously Sourced
- 1000V-rated probes and input sockets
- 0–100V digital voltmeter (3-wire, 5–30V DC powered)
- LED, red, 5 mm, Vf ≈ 2 V (from kit, no part number)

---

## TME Order (2026-04-15)

### Capacitors
| Qty | Part Number | Description | Manufacturer |
|-----|---|---|---|
| 5 | EEAGA1E100H | Electrolytic, 10µF, 25VDC, Ø4×7mm, 2.5mm pitch, THT | PANASONIC |
| 5 | K104K10X7RF5UH5 | Ceramic, 100nF, 50V, X7R, ±10%, 5mm pitch, THT | VISHAY |

### Resistors
| Qty | Part Number | Description | Manufacturer |
|-----|---|---|---|
| 5 | MF0207FTE-1M8 | Metal film, 1.8MΩ, 0.6W, ±1%, 350V, axial THT | YAGEO |
| 10 | MBB0207VC2204FCT00 | Metal film, 2.2MΩ, 0.6W, ±1%, 350V, axial THT | VISHAY |
| 100 | MF006FF1003A50 | Metal film, 100kΩ, 0.6W, ±1%, 250V, axial THT | ROYALOHM |
| 100 | MF006FF8203A50 | Metal film, 820kΩ, 0.6W, ±1%, 250V, axial THT | ROYALOHM |
| 20 | MOF3WS-15K | Metal oxide, 15kΩ, 3W, ±5%, 500V, Ø5×15mm, THT | SR PASSIVES |

### Potentiometers
| Qty | Part Number | Description | Manufacturer |
|-----|---|---|---|
| 2 | T93YA200K | Trimmer, wirewound, 200kΩ, 500mW, ±10%, THT | VISHAY |

### ICs
| Qty | Part Number | Description | Manufacturer |
|-----|---|---|---|
| 3 | LM393AP | Dual comparator, 300ns, 2–30V supply, DIP-8, THT | TEXAS INSTRUMENTS |

### Connectors & Hardware
| Qty | Part Number | Description | Manufacturer |
|-----|---|---|---|
| 1 set | CT2900A | Test leads, 12A, 1.2m, -20÷80°C | CAL TEST |
| 1 | SLB4-G-21 | 4mm banana socket (green), 1kV, 32A, Ø12.2mm hole | STÄUBLI |
| 1 | SLB4-G-22 | 4mm banana socket (black), 1kV, 32A, Ø12.2mm hole | STÄUBLI |
| 2 | MKDS5/2-9.5 | PCB screw terminal block, 2-pin, 32A, 1kV, 9.5mm pitch | PHOENIX CONTACT |

---

## Mouser Order 39007986 (2026-04-26)

### Resistors
| Qty | Part Number | Description | Manufacturer |
|-----|---|---|---|
| 5 | 45F4K7E | Wirewound, 4.7 kΩ, 5 W, ±1%, axial THT | Ohmite |
| 1 | 27J50RE | Wirewound, 50 Ω, 7 W, ±5%, axial THT | Ohmite |
| 1 | RN60D1000FB14 | Metal film, 100 Ω, 0.25 W, ±1%, axial THT | Vishay |
| 1 | FMP300FRF73-470K | Metal film, 470 kΩ, 3 W, ±1%, 750 V, axial THT | YAGEO |
| 1 | FMP300FRF73-1M | Metal film, 1 MΩ, 3 W, ±1%, 750 V, axial THT | YAGEO |
| 1 | MFR-25FTE52-10K | Metal film, 10 kΩ, 0.25 W, ±1%, axial THT | YAGEO |

### Semiconductors
| Qty | Part Number | Description | Manufacturer |
|-----|---|---|---|
| 4 | 1N4007 | Rectifier diode, 1 A, 1000 V, DO-41, THT | Diotec |
| 1 | STP10NK80Z | MOSFET N-Ch, 800 V, 9 A, TO-220, THT | STMicroelectronics |
| 1 | 2N3904TFR | BJT NPN, 40 V, 200 mA, TO-92, THT | onsemi |
| 1 | BZX85C12 | Zener, 12 V, 1 W, DO-41, THT | onsemi |
| 1 | BZX55C8V2-TAP | Zener, 8.2 V, 0.5 W, DO-35, THT | Vishay |
| 1 | 1N4744A-T50A | Zener, 15 V, 1 W, DO-41, THT | onsemi |

### Heatsinks
| Qty | Part Number | Description | Manufacturer |
|-----|---|---|---|
| 1 | 637-10ABPE | Heatsink, TO-220, 5.8 °C/W, 25.4×34.9×12.7 mm | Wakefield Thermal |
| 1 | 647-10ABEP | Heatsink, TO-220, 3.8 °C/W, 41.9×25.4×25.4 mm | Wakefield Thermal |

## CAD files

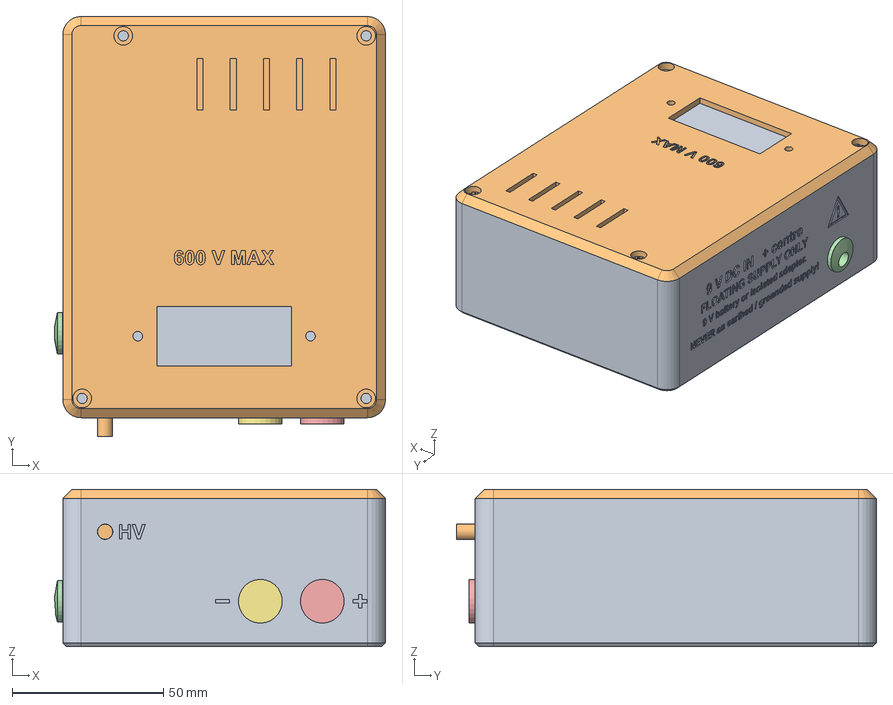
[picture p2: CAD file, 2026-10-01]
mechanical/enclosure/Enclosure_assembly.FCStd
109.6 x 139.0 x 52.0 mm
Base
Cover
Board
Jack
Sock_A
Sock_A_metal
Sock_B
Sock_B_metal
Meter
LED

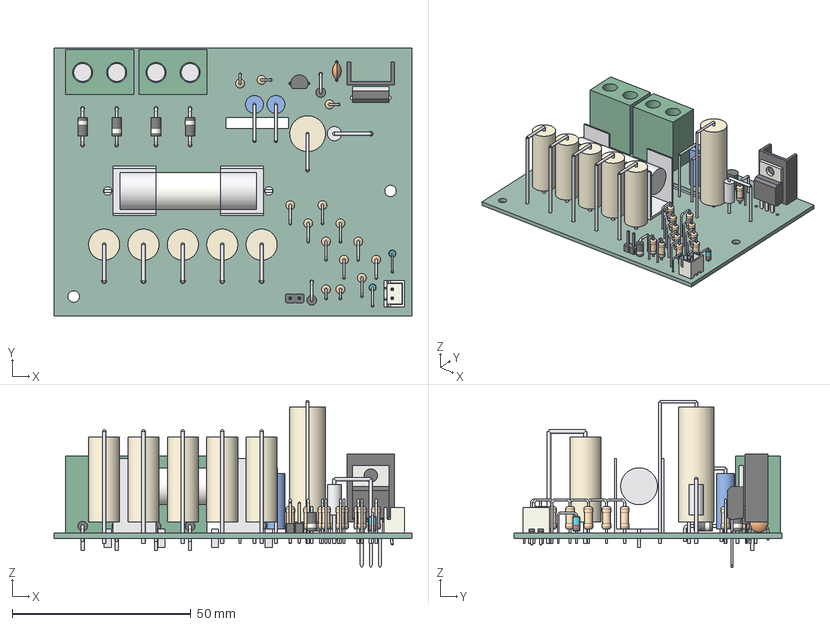
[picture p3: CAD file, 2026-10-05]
KiCAD/fab_1s/CapacitorDischarger_1S.step
100.0 x 75.0 x 46.8 mm
D_DO-41_SOD81_P10.16mm_Horizontal x 4
D_DO-35_SOD27_P5.08mm_Vertical_AnodeUp x 2
R_Axial_DIN0207_L63mm_D25mm_P508mm_Vertical x 9
p0 x 13
p1 x 12
R_Axial_DIN0207_L63mm_D25mm_P254mm_Vertical x 5
PinHeader_1x02_P254mm_Vertical
D_DO-41_SOD81_P5.08mm_Vertical_AnodeUp x 2
JST_B2B_XH_A
C_Disc_D50mm_W25mm_P500mm
TO-220-3_Vertical
TO-92_Inline_Wide
CapacitorDischarger_1S_PCB

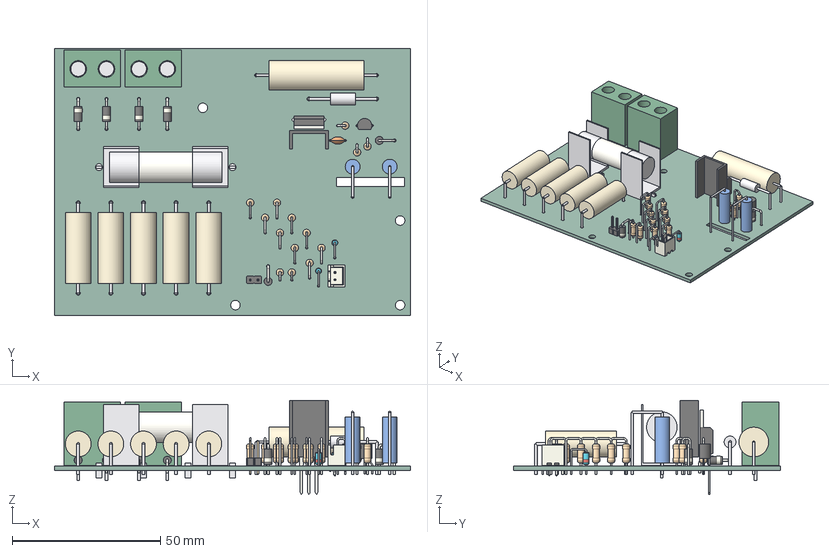
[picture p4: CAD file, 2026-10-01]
KiCAD/fab_2l/CapacitorDischarger_2L.step
120.0 x 90.0 x 31.8 mm
R_Axial_DIN0207_L63mm_D25mm_P254mm_Vertical x 5
JST_B2B_XH_A
PinHeader_1x02_P254mm_Vertical
R_Axial_DIN0207_L63mm_D25mm_P508mm_Vertical x 9
p0 x 13
p1 x 12
D_DO-35_SOD27_P5.08mm_Vertical_AnodeUp x 2
D_DO-41_SOD81_P10.16mm_Horizontal x 4
D_DO-41_SOD81_P5.08mm_Vertical_AnodeUp x 2
TO-92_Inline_Wide
TO-220-3_Vertical
C_Disc_D50mm_W25mm_P500mm
CapacitorDischarger_PCB

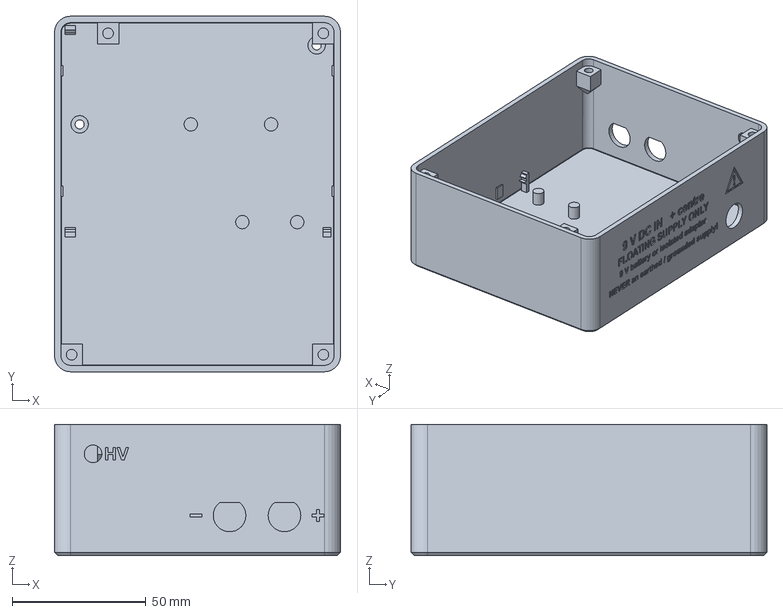
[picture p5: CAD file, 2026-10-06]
mechanical/enclosure/Enclosure_base.step
106.8 x 132.8 x 49.0 mm

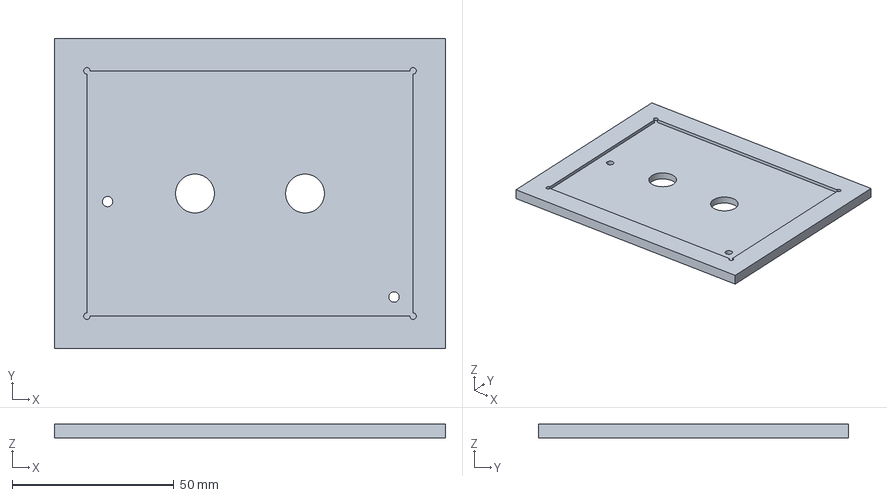
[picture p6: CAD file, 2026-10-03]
mechanical/mask_jig/Mask_jig.step
120.8 x 95.8 x 4.40 mm

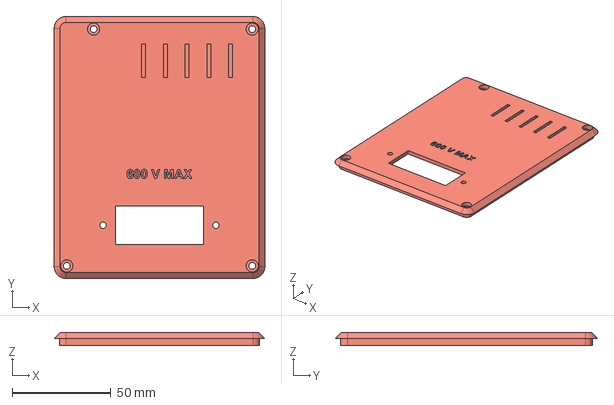
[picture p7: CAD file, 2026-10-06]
mechanical/enclosure/Enclosure_cover.step
106.8 x 132.8 x 6.60 mm

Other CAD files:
mechanical/enclosure/Enclosure_base.stl
mechanical/enclosure/Enclosure_cover.stl
mechanical/mask_jig/Mask_jig.stl

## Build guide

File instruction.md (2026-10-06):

# Build instructions: 600 V capacitor discharger (single-sided board + 3D-printed case)

This guide covers building, wiring, testing, calibrating and using the unit.
- Part data: [bom.md](bom.md).
- Design details: [README.md](README.md), [KiCAD/PCB_info.md](KiCAD/PCB_info.md), [simulation/](simulation/README.md).
- Enclosure: [mechanical/enclosure/README.md](mechanical/enclosure/README.md).

> **HV warning.** This tool is connected to capacitors charged up to 600 V. While a capacitor is connected,
> circuit GND sits at the capacitor's negative terminal and most of the board sits at hundreds of volts.
> Work on the board only with the probes disconnected. Close the cover before use.

---

## 1. What you are building

```
 probe + ─► banana J1 (green) ─► J3 ┐                     ┌─► R_slow1-5 (23.5 kΩ) ─────────────────► GND   always on
 probe − ─► banana J2 (black) ─► J4 ┴─► bridge D1-D4 ─► F1 ┼─► R_fast1 (50 Ω) ─► TF1 ─► Q2 ─────────► GND   only below ~63 V
                                       (any polarity)      ├─► R1/R2 ► Q1 ► R5/D9 (threshold, gate drive of Q2)
                                                           ├─► R_LED1-4 ► D_LED1 ► J6 ═ cable ═► LED1 (front panel)   on above ~10 V
                                                           └─► R_sig1-5 ► R_sig_bot (10 000:1) ► J5 ═ cable ═► PM-128 (cover)
 floating 9 V ─► DC jack (left wall) ═ cable ═► PM-128 supply
```

- **Above ~63 V:** only R_slow is connected, so the current stays at 25 mA or less. A 1 mF cap at 600 V takes about 45 s to discharge.
- **Below ~63 V:** Q2 adds R_fast, so the rest goes in under a second.
- **LED:** it is ON above ~10.2 V and OFF below.
- **Meter:** it reads in volts, with 1 V resolution ("600" at 600 V).
- **Protection:**
  - F1 (2 A, 1000 V DC) opens if Q2 fails short at high voltage.
  - TF1 (133 °C, mounted on R_fast) opens if the probes stay on a live supply below 63 V.

---

## 2. Parts and tools

Every part is in [bom.md](bom.md) with its inventory ID. The **still to buy** list is
[TO_BUY_list.csv](TO_BUY_list.csv). It includes the fuse, the CSO clips, TF1, the HLMP-4700 LED and the enclosure hardware:
- 4× M3 heat-set inserts.
- 4× M3×10 screws.
- 2× M3×12 **nylon** screws and nuts.
- Rubber feet.

**Wire:**
- **Probe leads (J1/J2 → J3/J4):** 1.5 mm² silicone, rated 0.6/1 kV.
- **J5 cable, LED cable and 9 V wires:** thin silicone wire rated 1 kV. They run over HV parts.
- **Lugs:** M4 ring lugs for the banana sockets.

**Tools:**
- UV exposure box, NaOH developer, etchant, 0.8–3.4 mm drills and a saw or rotary tool for the slot.
- Soldering iron, multimeter, JST XH crimp tool and heat-shrink.
- Soldering iron tip for the heat-set inserts.

---

## 3. Making the PCB (100 × 75 mm: toner transfer, or Bungard FEPCU-075 photoresist)

The board is **single-sided**: copper only on the bottom, no vias, no jumpers. Parts go on the top.

- **Traces:** HV tracks are 2 mm, the divider/LED chains 1.2 mm and the LV tracks 1 mm (one LED link is 0.8 mm), so they survive toner transfer and etching.
- **GND pour:** the rest of the bottom is copper. It keeps 6 mm from every HV track and pad, and 0.4 mm from LV ones. You only etch away about 40 % of the board, which makes the etch shorter and protects the narrow traces from undercutting.

**Toner transfer (blue paper):**
1. Print page 1, left image (**B.Cu POSITIVE**), of [KiCAD/fab_1s/1S_films_1to1.pdf](KiCAD/fab_1s/1S_films_1to1.pdf) on the blue paper. Use a laser printer at **100 %**, **not mirrored**, with toner density at maximum.
2. Check the 100 × 75 mm outline with a ruler.
3. Lay the print **toner side down on the copper** and iron it evenly. The large GND areas need even pressure and heat.
4. Touch up pinholes in the big black areas with an etch-resist pen, then etch as in step 2 below.
5. **Component outlines on the top side (optional).** [KiCAD/fab_1s/1S_copper_components_1to1.pdf](KiCAD/fab_1s/1S_copper_components_1to1.pdf) has the B.Cu positive and the component outlines and references (F.Fab + F.SilkS) on one A4 sheet.
   - The components image is already **mirrored**. Iron it toner side down onto the bare component side after drilling, and use the holes to line it up.

**Photoresist (Bungard FEPCU-075, positive):**

1. **Print the film.** Print [KiCAD/fab_1s/1S_B.Cu_exposure_1to1.pdf](KiCAD/fab_1s/1S_B.Cu_exposure_1to1.pdf) on transparency. Set the size to **100 %** (not fit-to-page) and toner density to maximum. Check the 100 × 75 mm outline with a ruler.
   - The film is a positive, drawn as seen from the component side. **Lay it toner side down on the copper.**
   - For toner transfer, or for a negative photoresist, use page 1 of [KiCAD/fab_1s/1S_films_1to1.pdf](KiCAD/fab_1s/1S_films_1to1.pdf): B.Cu positive and negative side by side, same orientation.
2. **Expose, develop, etch.** Expose, then develop in NaOH (about 7 g/l). Rinse, then etch: sodium persulfate at 40–45 °C, or FeCl₃.
   - Do a test strip first, because exposure time depends on your UV box.
   - To strip the leftover resist, re-expose the whole board and develop again, or use acetone.
3. **Drill.** The small marks in each pad help centre the drill.

   | Drill | Holes | Parts |
   |---|---|---|
   | 0.8 mm | 37 | small resistors, D_LED1, D_clamp2, Q1, C_byp2 |
   | 1.0 mm | 8 | J5, J6, R1, R5 |
   | 1.1 mm | 14 | D1–D4, D9, D_clamp1, R_fast1 |
   | 1.2 mm | 3 | Q2 |
   | 1.3 mm | 2 | TF1 |
   | 1.4 mm | 14 | J3, J4, R_slow1–5 |
   | 2.35 mm | 4 | F1 clip pins |
   | 3.4 mm | 2 | F1 clip centre holes (leave them empty) |
   | 3.2 mm | 2 | H1, H3 mounting holes |

4. **Cut the slot.** It is the 17.5 × 3 mm outlined rectangle under R1/R5. Cut it with a saw or rotary tool. Its job is to lengthen the 600 V creepage path between the two pads of R1 and of R5.
5. **Protect the copper (recommended).** Clean the board and coat the copper side with your green solder mask, leaving the pads open. For UV mask, use [KiCAD/fab_1s/1S_solder_mask_1to1.pdf](KiCAD/fab_1s/1S_solder_mask_1to1.pdf). It has two identical B.Mask images: print it on transparency, cut them out, and stack them toner to toner, lined up on the pads, for a denser film, and the board goes in the jig in [mechanical/mask_jig/](mechanical/mask_jig/README.md). If you don't have it, use PCB lacquer. Uncoated copper also works, because the clearances are designed for it.

---

## 4. Board assembly (low parts first)

Use [KiCAD/fab_1s/1S_assembly_top.pdf](KiCAD/fab_1s/1S_assembly_top.pdf) as the placement map. Almost every part stands vertically.

1. **Small resistors, standing:** R_sig1–5, R_LED1–4, R_sig_bot1/2, R2–R4. Put the body on the pad marked by the outline circle.
2. **Diodes and zeners** (check the band):
   - D_LED1 and D_clamp2: both BZX55C8V2.
   - D9: BZX85C12.
   - D_clamp1 and D1–D4: 1N4007.

   D_clamp2 sits next to J6. Its cathode connects to LED_A and its anode to GND.
3. **Small parts:** Q1 (MPSA42, flat side as drawn), C_byp2, J5 (pin header), and **J6 (JST XH 2-pin)**.
4. **R1 and R5 (3 W):** the body stands on the LV pad, and the bare lead crosses the slot to the HVp pad. Keep that lead straight and clear of everything else.
5. **J3 and J4 (MKDS 5):** wire entries face the board edge.
6. **F1 clips (Schurter CSO):** solder both pins of each clip. Leave the centre holes empty, because the case has support posts under them.
7. **R_slow1–5 (5 W):** standing, about 3 mm above the board. The gap between bodies is for airflow.
8. **R_fast1 (7 W) and TF1:** stand R_fast1 up. Clamp TF1's body against it with stainless wire or a clip, using a thin layer of thermal compound. TF1's metal case is at HV.
9. **Q2 (STP10NK80Z):**
   - Bend the gate and source legs out to the 5.08 mm pitch.
   - Slip the HS-S01 heatsink onto the tab with the **Fischer MST 220** insulator under it.
   - **Check** with an ohmmeter that the heatsink is not connected to the tab (drain): it must read open.
10. **Trim every lead to ≤ 3 mm** under the board. The case standoffs are only 6 mm high, and all the HV copper is on the underside.
11. **Clean off all flux** with isopropyl alcohol. Flux residue leaks at 600 V.

**Cold checks (multimeter):**

| Check | Expected |
|---|---|
| F1 fitted: clip A ↔ clip B | ~0 Ω |
| R_fast1 pad ↔ Q2 drain (through TF1) | ~0 Ω |
| HVp (F1 clip B, red lead) ↔ GND ring (black lead) | ≈ 22 kΩ: 23.5 kΩ for R_slow, in parallel with the divider chains. With the leads reversed it reads low, through Q2's body diode and R_fast1. |
| Q2 heatsink ↔ Q2 tab | open |

---

## 5. Enclosure

Full details are in [mechanical/enclosure/README.md](mechanical/enclosure/README.md).
1. **Print.** Print `Enclosure_base.stl` floor-down and `Enclosure_cover.stl` upside-down, both in **PETG or ASA (not PLA)**, with no supports. Use at least 3 perimeters and 25 % infill.
2. **Test print (recommended).** Print the front-right corner first to check the socket fit and how the board hooks snap.
3. **Heat-set inserts.** Press the 4 M3 inserts into the corner bosses with the soldering iron.
4. **Check before printing:**
   - **PM-128:** measure yours. The script assumes 70 × 40 mm, 23 mm deep, a 44.5 × 19.7 mm window and holes 57.15 mm apart (`MET*` in `gen_enclosure.py`).
   - **Insert hole:** it is Ø4.0 × 6.5 mm (`INS_D`, `INS_L`).

---

## 6. Wiring and final assembly

1. **Banana sockets (front wall):**
   - Fit the green socket J1 on the right ("+") and the black J2 next to it ("−"). Their nuts go inside, and the flat of each hole is on top.
   - Crimp M4 ring lugs on 1.5 mm² silicone wire. Bolt them to the sockets and heat-shrink the lugs.
   - Each lug points straight at its terminal block: J1 → **J3**, J2 → **J4**.
   - Both poles of a block are the same probe, so use either entry.
2. **DC jack (left wall, under the warning).** Fit it with its nut inside.
3. **Front-panel LED (LED1, HLMP-4700):**
   - Heat-shrink both legs.
   - Crimp the XH housing onto about 15 cm of 1 kV wire: **pin 1 = cathode (GND), pin 2 = anode.**
   - Push the 5 mm panel clip into the front-wall hole from the outside, with its slots vertical. Then push the LED into it from inside until it snaps in.
4. **Board:** put it on the standoffs and press it down until the 3 hooks click. Fit the two **nylon** M3×12 screws (H1, H3), with nuts in the hex pockets under the floor.
5. **Connect the probe wires** into J3/J4 and tighten the screws. They stay reachable from the top.
6. **Plug the LED into J6** (rear-left). Run the cable up and along the left wall, above the Q2 heatsink, then down to the front panel.
7. **PM-128:**
   - Leave the factory **RB** wire jumper in place. Don't fit **RA**, and leave the decimal-point jumpers **P1–P3 open**.
   - Mount the meter under the cover with two screws through the cover into its bezel.
   - **Supply:** DC jack centre (+) → PM-128 +9 V; jack sleeve (−) → PM-128 −9 V. **Never connect the jack to circuit GND.**
   - **Input:** J5 pin 1 (VIN) → PM-128 VIN; J5 pin 2 (GND) → PM-128 IN GND. Use a 2-pin plug on the J5 header.
8. **Close up.** Leave the cover wires long enough that the cover can lie beside the box. Close it with 4× M3×10 screws and stick rubber feet under the floor.

**Wiring table**

| From | To | Wire |
|---|---|---|
| J1 green socket (M4 lug) | J3 (either entry) | 1.5 mm² silicone, 1 kV |
| J2 black socket (M4 lug) | J4 (either entry) | 1.5 mm² silicone, 1 kV |
| DC jack centre (+) / sleeve (−) | PM-128 +9 V / −9 V | thin silicone, 1 kV |
| J5 pin 1 / pin 2 | PM-128 VIN / IN GND | thin silicone, 1 kV |
| J6 pin 1 / pin 2 (XH) | LED1 cathode / anode | thin silicone, 1 kV |

**9 V supply:** any **floating** 9 V source on a 5.5×2.1 plug (centre +), drawing ~1 mA. A 9 V battery on a plug or a double-insulated adapter is fine. Never use a supply whose − is earthed or tied to the device under test (see the warning on the case).

---

## 7. Tests

Do them in this order. Use capacitors rated above the test voltage.

1. **Meter power.**
   - Probes open, 9 V plugged in: the PM-128 shows `0` (or `000`).
   - The jack sleeve ↔ GND ring reads open.
2. **Low voltage.**
   - Charge an electrolytic to about 24 V from a bench supply (e.g. 1000 µF / 35 V through 100 Ω), then disconnect the supply.
   - Touch the probes to it: the LED lights, the meter reads ~24 and drops fast, and the LED goes out around 10 V.
   - **Don't test on a live bench supply below 63 V.** The tool is then a 50 Ω load, and TF1 (one-shot) will open within seconds.
3. **Mid voltage.**
   - Charge a 470 µF / 450 V capacitor to 300 V from a current-limited HV source, then disconnect the source.
   - Expect: the meter reads ~300, the slow phase lasts ~15 s down to 63 V, then a fast drop, and the LED goes off around 10 V. *(Simulation B: 14.7 s.)*
4. **Full voltage.**
   - Charge a 1 mF cap rated ≥ 700 V to 600 V (or a series stack of caps with balancing resistors).
   - Expect ~45 s total *(simulation A: 45.2 s)*, peak R_slow current ≈ 25 mA, and fast-path peak ~1.2 A.
   - Repeat 5×, letting it cool in between. The R_slow bodies must not discolour, and the case must stay below ~60 °C.
5. **Reverse polarity.** Repeat a 300 V discharge with the probes swapped. It should behave the same, and the meter still reads positive.
6. **Probes shorted together.** Nothing happens: no source, no current.

---

## 8. Calibration (PM-128 trimmer R4)

The divider is 10 000:1 within 1 %. The PM-128 trimmer R4 corrects the remaining error.

- **Best method:** apply a steady DC voltage of 100–300 V from an HV bench supply (the tool draws V / ~22 kΩ, e.g. 14 mA at 300 V). Measure it with a DMM at the probes and turn R4 until the display matches. Then check at a second voltage.
- **Without an HV supply:**
  1. Unplug J5.
  2. Feed a stable ~50 mV (a resistor divider from the 9 V) into PM-128 VIN / IN GND.
  3. Set R4 so the display shows the DMM reading in mV × 10. For example, 50.0 mV should read `500`.
  4. Reconnect J5.

  This doesn't correct the divider's own ±1 %.

---

## 9. Using the tool

1. Plug in the 9 V source and check that the meter shows `0`.
   Without it the tool still discharges and the LED still works (both run from the capacitor); only the meter stays blank.
2. Connect both probes to the capacitor (any polarity). The LED lights and the meter shows the voltage.
3. Wait until **the LED is off and the meter reads 0–1**, then keep the probes on for a few more seconds.
4. Check with a separate multimeter before touching the capacitor. Electrolytics recover a few volts after discharge.
5. **Limits:**
   - 600 V maximum.
   - **Never** on live circuits or mains-connected equipment.
   - With large caps (≥ 1 mF at 600 V, ~180 J), let the resistors cool between discharges.

---

## 10. Troubleshooting

| Symptom | Likely cause |
|---|---|
| Discharge slows down and never finishes below ~63 V | TF1 has opened (live supply, or Q2 stuck on). Replace TF1 and check Q1/D9/Q2. The slow path still works. |
| Nothing discharges, LED and meter dead with a charged cap | F1 is blown (check for a shorted Q2 first), or a probe wire is loose in J3/J4. |
| LED never lights | LED plugged in backwards on J6 (pin 1 = cathode), LED wire broken, or D_LED1/D_clamp2 fitted backwards. |
| Meter shows `1` (overrange) as soon as a charged cap is connected | R_sig_bot1/2 open, so the meter input sits at D_clamp1's 0.7 V. Check the divider bottom and J5. |
| Meter dead | 9 V not plugged in, polarity reversed at the jack, or supply below 7 V. |
| Meter reads ~10× too low or high | Decimal-point or RA/RB jumpers changed on the PM-128 (see §6). |

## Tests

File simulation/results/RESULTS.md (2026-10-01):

# Simulation Results

| Scenario | Result |
|---|---|
| A_full_600V_1mF | **PASS** |
| B_mid_300V_470uF | **PASS** |
| C_mid_100V_100uF | **PASS** |
| D_low_50V_100uF | **PASS** |
| E_below_LED_8V_100uF | **PASS** |
| F_steady_state_600V | **PASS** |
| G_threshold_sweep | **PASS** |
| G2_threshold_lowbeta | **PASS** |
| G3_threshold_cold_lowhfe | **PASS** |
| G4_threshold_hot_highhfe | **PASS** |
| H_dvm_divider_clamp | **PASS** |
| I_reverse_600V_1mF | **PASS** |
| J_hotplug_600V | **PASS** |
| K_bigcap_60V_47mF | **PASS** |
| L_live_supply_48V | **PASS** |

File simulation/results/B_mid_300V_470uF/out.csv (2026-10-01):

 5.00000000e-05  2.98287802e+02  5.00000000e-05  4.33362192e-02  5.00000000e-05  5.20034630e-02  5.00000000e-05  2.98257437e-02  5.00000000e-05  2.01201490e+00  5.00000000e-05  2.99143106e+02  5.00000000e-05 -8.55304218e-01  5.00000000e-05  1.26930980e-02  5.00000000e-05  2.91531764e-10  5.00000000e-05  7.20359378e-04  5.00000000e-05  5.96515953e-04  5.00000000e-05  2.50000000e+01  5.00000000e-05  0.00000000e+00
 5.14030629e-05  2.98287758e+02  5.14030629e-05  4.44324174e-02  5.14030629e-05  5.22453116e-02  5.14030629e-05  2.98257393e-02  5.14030629e-05  2.01154409e+00  5.14030629e-05  2.99143062e+02  5.14030629e-05 -8.55304212e-01  5.14030629e-05  1.26930961e-02  5.14030629e-05  2.91524293e-10  5.14030629e-05  7.20360444e-04  5.14030629e-05  5.96515864e-04  5.14030629e-05  2.50000000e+01  5.14030629e-05  0.00000000e+00
 5.42091888e-05  2.98287668e+02  5.42091888e-05  4.64204547e-02  5.42091888e-05  5.27768274e-02  5.42091888e-05  2.98257304e-02  5.42091888e-05  2.01154407e+00  5.42091888e-05  2.99142973e+02  5.42091888e-05 -8.55304191e-01  5.42091888e-05  1.26930923e-02  5.42091888e-05  2.91536189e-10  5.42091888e-05  7.20360221e-04  5.42091888e-05  5.96515685e-04  5.42091888e-05  2.50000000e+01  5.42091888e-05  0.00000000e+00
 5.98214405e-05  2.98287490e+02  5.98214405e-05  4.93814817e-02  5.98214405e-05  5.35771199e-02  5.98214405e-05  2.98257125e-02  5.98214405e-05  2.01154404e+00  5.98214405e-05  2.99142794e+02  5.98214405e-05 -8.55304153e-01  5.98214405e-05  1.26930847e-02  5.98214405e-05  2.91532801e-10  5.98214405e-05  7.20359775e-04  5.98214405e-05  5.96515329e-04  5.98214405e-05  2.50000000e+01  5.98214405e-05  0.00000000e+00
 7.10459438e-05  2.98287133e+02  7.10459438e-05  5.27086860e-02  7.10459438e-05  5.44415137e-02  7.10459438e-05  2.98256769e-02  7.10459438e-05  2.01154397e+00  7.10459438e-05  2.99142437e+02  7.10459438e-05 -8.55304082e-01  7.10459438e-05  1.26930695e-02  7.10459438e-05  2.91524073e-10  7.10459438e-05  7.20358884e-04  7.10459438e-05  5.96514615e-04  7.10459438e-05  2.50000000e+01  7.10459438e-05  0.00000000e+00
 9.34949506e-05  2.98286420e+02  9.34949506e-05  5.48319858e-02  9.34949506e-05  5.49908229e-02  9.34949506e-05  2.98256055e-02  9.34949506e-05  2.01154383e+00  9.34949506e-05  2.99141724e+02  9.34949506e-05 -8.55303951e-01  9.34949506e-05  1.26930391e-02  9.34949506e-05  2.91534439e-10  9.34949506e-05  7.20357101e-04  9.34949506e-05  5.96513189e-04  9.34949506e-05  2.50000000e+01  9.34949506e-05  0.00000000e+00
 1.25772752e-04  2.98285394e+02  1.25772752e-04  5.50572466e-02  1.25772752e-04  5.50379858e-02  1.25772752e-04  2.98255030e-02  1.25772752e-04  2.01154364e+00  1.25772752e-04  2.99140698e+02  1.25772752e-04 -8.55303770e-01  1.25772752e-04  1.26929955e-02  1.25772752e-04  2.91532545e-10  1.25772752e-04  7.20354538e-04  1.25772752e-04  5.96511137e-04  1.25772752e-04  2.50000000e+01  1.25772752e-04  0.00000000e+00
 1.72150814e-04  2.98283920e+02  1.72150814e-04  5.50307149e-02  1.72150814e-04  5.50385342e-02  1.72150814e-04  2.98253556e-02  1.72150814e-04  2.01154335e+00  1.72150814e-04  2.99139224e+02  1.72150814e-04 -8.55303510e-01  1.72150814e-04  1.26929328e-02  1.72150814e-04  2.91525736e-10  1.72150814e-04  7.20350854e-04  1.72150814e-04  5.96508190e-04  1.72150814e-04  2.50000000e+01  1.72150814e-04  0.00000000e+00
 2.54005403e-04  2.98281319e+02  2.54005403e-04  5.50391758e-02  2.54005403e-04  5.50334237e-02  2.54005403e-04  2.98250955e-02  2.54005403e-04  2.01154285e+00  2.54005403e-04  2.99136622e+02  2.54005403e-04 -8.55303052e-01  2.54005403e-04  1.26928221e-02  2.54005403e-04  2.91518735e-10  2.54005403e-04  7.20344354e-04  2.54005403e-04  5.96502988e-04  2.54005403e-04  2.50000000e+01  2.54005403e-04  0.00000000e+00
 4.17714580e-04  2.98276117e+02  4.17714580e-04  5.50343487e-02  4.17714580e-04  5.50395110e-02  4.17714580e-04  2.98245753e-02  4.17714580e-04  2.01154186e+00  4.17714580e-04  2.99131419e+02  4.17714580e-04 -8.55302135e-01  4.17714580e-04  1.26926007e-02  4.17714580e-04  2.91524511e-10  4.17714580e-04  7.20331353e-04  4.17714580e-04  5.96492585e-04  4.17714580e-04  2.50000000e+01  4.17714580e-04  0.00000000e+00
 7.45132936e-04  2.98265713e+02  7.45132936e-04  5.50382911e-02  7.45132936e-04  5.50333696e-02  7.45132936e-04  2.98235350e-02  7.45132936e-04  2.01153986e+00  7.45132936e-04  2.99121013e+02  7.45132936e-04 -8.55300302e-01  7.45132936e-04  1.26921580e-02  7.45132936e-04  2.91494895e-10  7.45132936e-04  7.20305352e-04  7.45132936e-04  5.96471779e-04  7.45132936e-04  2.50000000e+01  7.45132936e-04  0.00000000e+00
 1.39996965e-03  2.98244906e+02  1.39996965e-03  5.50352113e-02  1.39996965e-03  5.50400387e-02  1.39996965e-03  2.98214545e-02  1.39996965e-03  2.01153586e+00  1.39996965e-03  2.99100202e+02  1.39996965e-03 -8.55296635e-01  1.39996965e-03  1.26912726e-02  1.39996965e-03  2.91490151e-10  1.39996965e-03  7.20253352e-04  1.39996965e-03  5.96430169e-04  1.39996965e-03  2.50000000e+01  1.39996965e-03  0.00000000e+00
 2.70964307e-03  2.98203296e+02  2.70964307e-03  5.50389388e-02  2.70964307e-03  5.50341683e-02  2.70964307e-03  2.98172939e-02  2.70964307e-03  2.01152788e+00  2.70964307e-03  2.99058585e+02  2.70964307e-03 -8.55289301e-01  2.70964307e-03  1.26895019e-02  2.70964307e-03  2.91457847e-10  2.70964307e-03  7.20149363e-04  2.70964307e-03  5.96346957e-04  2.70964307e-03  2.50000000e+01  2.70964307e-03  0.00000000e+00
 5.00000000e-03  2.98130542e+02  5.00000000e-03  5.50368594e-02  5.00000000e-03  5.50416118e-02  5.00000000e-03  2.98100193e-02  5.00000000e-03  2.01151391e+00  5.00000000e-03  2.98985818e+02  5.00000000e-03 -8.55276475e-01  5.00000000e-03  1.26864060e-02  5.00000000e-03  2.91380421e-10  5.00000000e-03  7.19967543e-04  5.00000000e-03  5.96201464e-04  5.00000000e-03  2.50000000e+01  5.00000000e-03  0.00000000e+00
 5.26193468e-03  2.98122223e+02  5.26193468e-03  5.50384169e-02  5.26193468e-03  5.50384763e-02  5.26193468e-03  2.98091875e-02  5.26193468e-03  2.01151231e+00  5.26193468e-03  2.98977498e+02  5.26193468e-03 -8.55275007e-01  5.26193468e-03  1.26860520e-02  5.26193468e-03  2.91360821e-10  5.26193468e-03  7.19946752e-04  5.26193468e-03  5.96184827e-04  5.26193468e-03  2.50000000e+01  5.26193468e-03  0.00000000e+00
 5.78580405e-03  2.98105585e+02  5.78580405e-03  5.50387799e-02  5.78580405e-03  5.50387343e-02  5.78580405e-03  2.98075239e-02  5.78580405e-03  2.01150911e+00  5.78580405e-03  2.98960857e+02  5.78580405e-03 -8.55272073e-01  5.78580405e-03  1.26853440e-02  5.78580405e-03  2.91349551e-10  5.78580405e-03  7.19905172e-04  5.78580405e-03  5.96151555e-04  5.78580405e-03  2.50000000e+01  5.78580405e-03  0.00000000e+00
 6.83354279e-03  2.98072312e+02  6.83354279e-03  5.50391046e-02  6.83354279e-03  5.50391564e-02  6.83354279e-03  2.98041969e-02  6.83354279e-03  2.01150272e+00  6.83354279e-03  2.98927578e+02  6.83354279e-03 -8.55266206e-01  6.83354279e-03  1.26839282e-02  6.83354279e-03  2.91321724e-10  6.83354279e-03  7.19822019e-04  6.83354279e-03  5.96085015e-04  6.83354279e-03  2.50000000e+01  6.83354279e-03  0.00000000e+00
 8.92902026e-03  2.98005777e+02  8.92902026e-03  5.50401295e-02  8.92902026e-03  5.50400875e-02  8.92902026e-03  2.97975441e-02  8.92902026e-03  2.01148994e+00  8.92902026e-03  2.98861032e+02  8.92902026e-03 -8.55254472e-01  8.92902026e-03  1.26810969e-02  8.92902026e-03  2.91259665e-10  8.92902026e-03  7.19655741e-04  8.92902026e-03  5.95951959e-04  8.92902026e-03  2.50000000e+01  8.92902026e-03  0.00000000e+00
 1.31199752e-02  2.97872752e+02  1.31199752e-02  5.50418168e-02  1.31199752e-02  5.50418669e-02  1.31199752e-02  2.97842430e-02  1.31199752e-02  2.01146438e+00  1.31199752e-02  2.98727983e+02  1.31199752e-02 -8.55231006e-01  1.31199752e-02  1.26754363e-02  1.31199752e-02  2.91140187e-10  1.31199752e-02  7.19323296e-04  1.31199752e-02  5.95685936e-04  1.31199752e-02  2.50000000e+01  1.31199752e-02  0.00000000e+00
 1.81199752e-02  2.97714126e+02  1.81199752e-02  5.50440935e-02  1.81199752e-02  5.50440525e-02  1.81199752e-02  2.97683819e-02  1.81199752e-02  2.01143388e+00  1.81199752e-02  2.98569329e+02  1.81199752e-02 -8.55203008e-01  1.81199752e-02  1.26686862e-02  1.81199752e-02  2.90971232e-10  1.81199752e-02  7.18926868e-04  1.81199752e-02  5.95368714e-04  1.81199752e-02  2.50000000e+01  1.81199752e-02  0.00000000e+00
 2.31199752e-02  2.97555583e+02  2.31199752e-02  5.50461381e-02  2.31199752e-02  5.50461873e-02  2.31199752e-02  2.97525293e-02  2.31199752e-02  2.01140338e+00  2.31199752e-02  2.98410758e+02  2.31199752e-02 -8.55175008e-01  2.31199752e-02  1.26619397e-02  2.31199752e-02  2.90815033e-10  2.31199752e-02  7.18530653e-04  2.31199752e-02  5.95051662e-04  2.31199752e-02  2.50000000e+01  2.31199752e-02  0.00000000e+00
 2.81199752e-02  2.97397126e+02  2.81199752e-02  5.50484178e-02  2.81199752e-02  5.50483778e-02  2.81199752e-02  2.97366852e-02  2.81199752e-02  2.01137289e+00  2.81199752e-02  2.98252273e+02  2.81199752e-02 -8.55147008e-01  2.81199752e-02  1.26551968e-02  2.81199752e-02  2.90666482e-10  2.81199752e-02  7.18134648e-04  2.81199752e-02  5.94734778e-04  2.81199752e-02  2.50000000e+01  2.81199752e-02  0.00000000e+00
 3.31199752e-02  2.97238753e+02  3.31199752e-02  5.50504699e-02  3.31199752e-02  5.50505181e-02  3.31199752e-02  2.97208495e-02  3.31199752e-02  2.01134239e+00  3.31199752e-02  2.98093872e+02  3.31199752e-02 -8.55119009e-01  3.31199752e-02  1.26484576e-02  3.31199752e-02  2.90511505e-10  3.31199752e-02  7.17738855e-04  3.31199752e-02  5.94418064e-04  3.31199752e-02  2.50000000e+01  3.31199752e-02  0.00000000e+00
 3.81199752e-02  2.97080464e+02  3.81199752e-02  5.50527521e-02  3.81199752e-02  5.50527130e-02  3.81199752e-02  2.97050223e-02  3.81199752e-02  2.01131189e+00  3.81199752e-02  2.97935555e+02  3.81199752e-02 -8.55091009e-01  3.81199752e-02  1.26417219e-02  3.81199752e-02  2.90353527e-10  3.81199752e-02  7.17343274e-04  3.81199752e-02  5.94101519e-04  3.81199752e-02  2.50000000e+01  3.81199752e-02  0.00000000e+00
 4.31199752e-02  2.96922260e+02  4.31199752e-02  5.50548116e-02  4.31199752e-02  5.50548589e-02  4.31199752e-02  2.96892035e-02  4.31199752e-02  2.01128140e+00  4.31199752e-02  2.97777323e+02  4.31199752e-02 -8.55063010e-01  4.31199752e-02  1.26349898e-02  4.31199752e-02  2.90195299e-10  4.31199752e-02  7.16947903e-04  4.31199752e-02  5.93785142e-04  4.31199752e-02  2.50000000e+01  4.31199752e-02  0.00000000e+00
 4.81199752e-02  2.96764141e+02  4.81199752e-02  5.50570964e-02  4.81199752e-02  5.50570582e-02  4.81199752e-02  2.96733932e-02  4.81199752e-02  2.01125090e+00  4.81199752e-02  2.97619176e+02  4.81199752e-02 -8.55035011e-01  4.81199752e-02  1.26282613e-02  4.81199752e-02  2.90041246e-10  4.81199752e-02  7.16552744e-04  4.81199752e-02  5.93468935e-04  4.81199752e-02  2.50000000e+01  4.81199752e-02  0.00000000e+00
 5.31199752e-02  2.96606105e+02  5.31199752e-02  5.50591632e-02  5.31199752e-02  5.50592097e-02  5.31199752e-02  2.96575913e-02  5.31199752e-02  2.01122040e+00  5.31199752e-02  2.97461112e+02  5.31199752e-02 -8.55007012e-01  5.31199752e-02  1.26215364e-02  5.31199752e-02  2.89893058e-10  5.31199752e-02  7.16157795e-04  5.31199752e-02  5.93152896e-04  5.31199752e-02  2.50000000e+01  5.31199752e-02  0.00000000e+00
 5.81199752e-02  2.96448155e+02  5.81199752e-02  5.50614507e-02  5.81199752e-02  5.50614134e-02  5.81199752e-02  2.96417978e-02  5.81199752e-02  2.01118991e+00  5.81199752e-02  2.97303134e+02  5.81199752e-02 -8.54979014e-01  5.81199752e-02  1.26148151e-02  5.81199752e-02  2.89742074e-10  5.81199752e-02  7.15763058e-04  5.81199752e-02  5.92837026e-04  5.81199752e-02  2.50000000e+01  5.81199752e-02  0.00000000e+00
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

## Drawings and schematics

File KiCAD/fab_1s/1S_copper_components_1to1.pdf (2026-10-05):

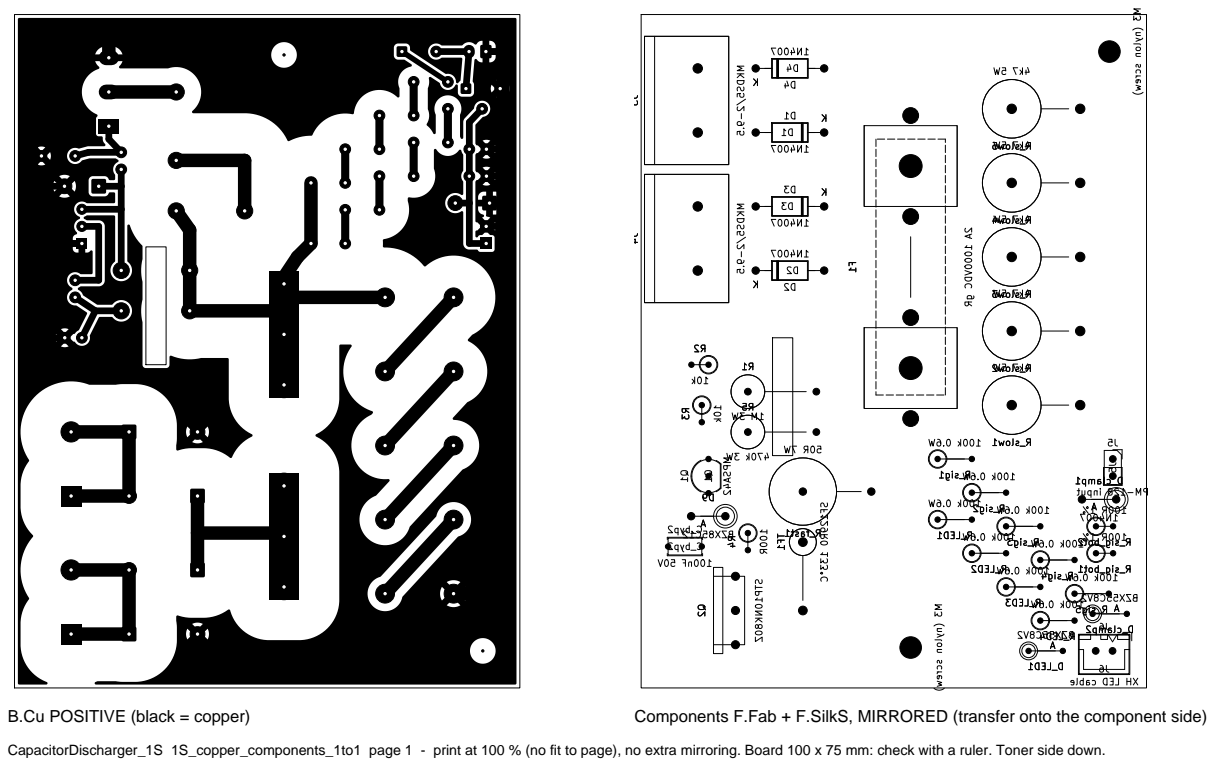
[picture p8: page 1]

100R J5 input PM-128 J5 R_LED2 0.6W 100k M3 (nylon screw) H3 D_clamp1 1N4007 A D4 1N4007 D4 K R_sig10.6W 100k

Components F.Fab + F.SilkS, MIRRORED (transfer onto the component side)

CapacitorDischarger_1S 1S_copper_components_1to1 page 1 - print at 100 % (no fit to page), no extra mirroring. Board 100 x 75 mm: check with a ruler. Toner side down.

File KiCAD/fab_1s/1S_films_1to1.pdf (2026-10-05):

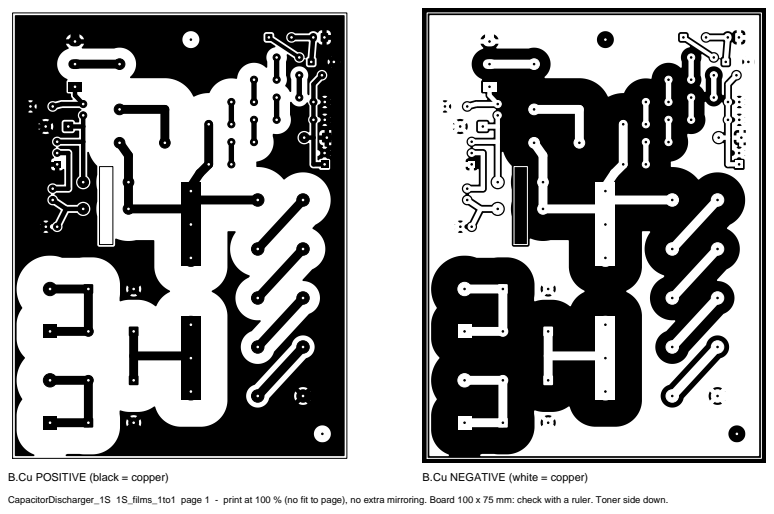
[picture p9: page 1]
B.Cu POSITIVE (black = copper); B.Cu NEGATIVE (white = copper)

CapacitorDischarger_1S 1S_films_1to1 page 1 - print at 100 % (no fit to page), no extra mirroring. Board 100 x 75 mm: check with a ruler. Toner side down.

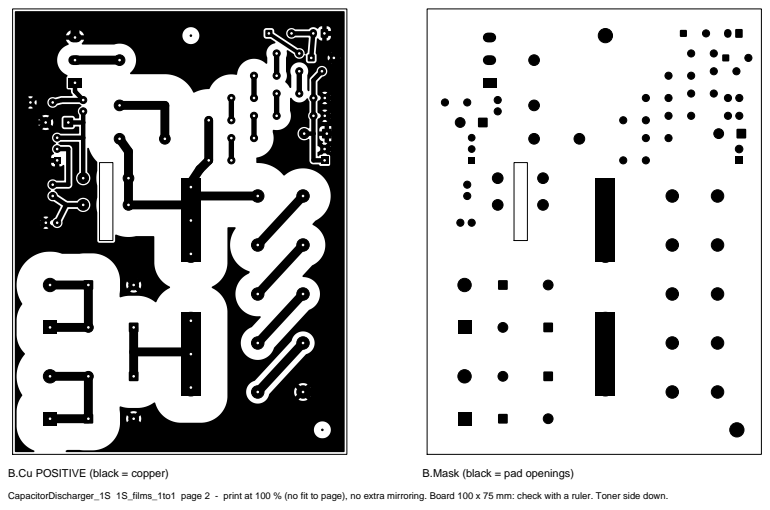
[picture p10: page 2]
B.Cu POSITIVE (black = copper); B.Mask (black = pad openings)

CapacitorDischarger_1S 1S_films_1to1 page 2 - print at 100 % (no fit to page), no extra mirroring. Board 100 x 75 mm: check with a ruler. Toner side down.

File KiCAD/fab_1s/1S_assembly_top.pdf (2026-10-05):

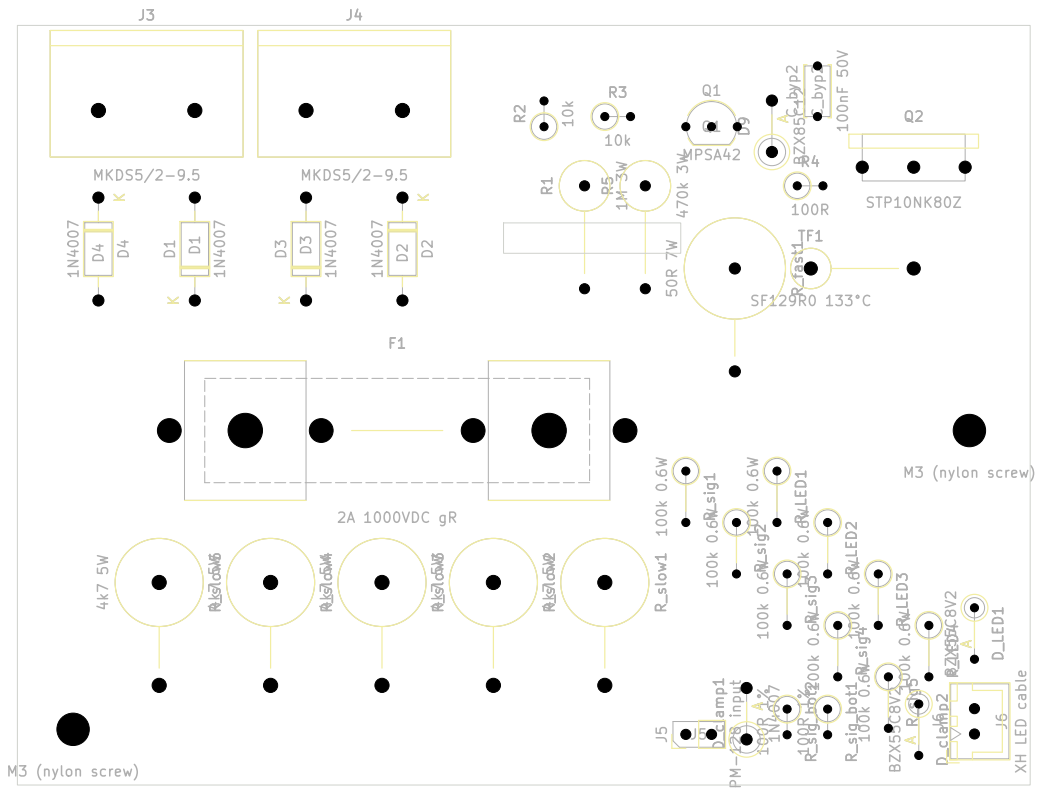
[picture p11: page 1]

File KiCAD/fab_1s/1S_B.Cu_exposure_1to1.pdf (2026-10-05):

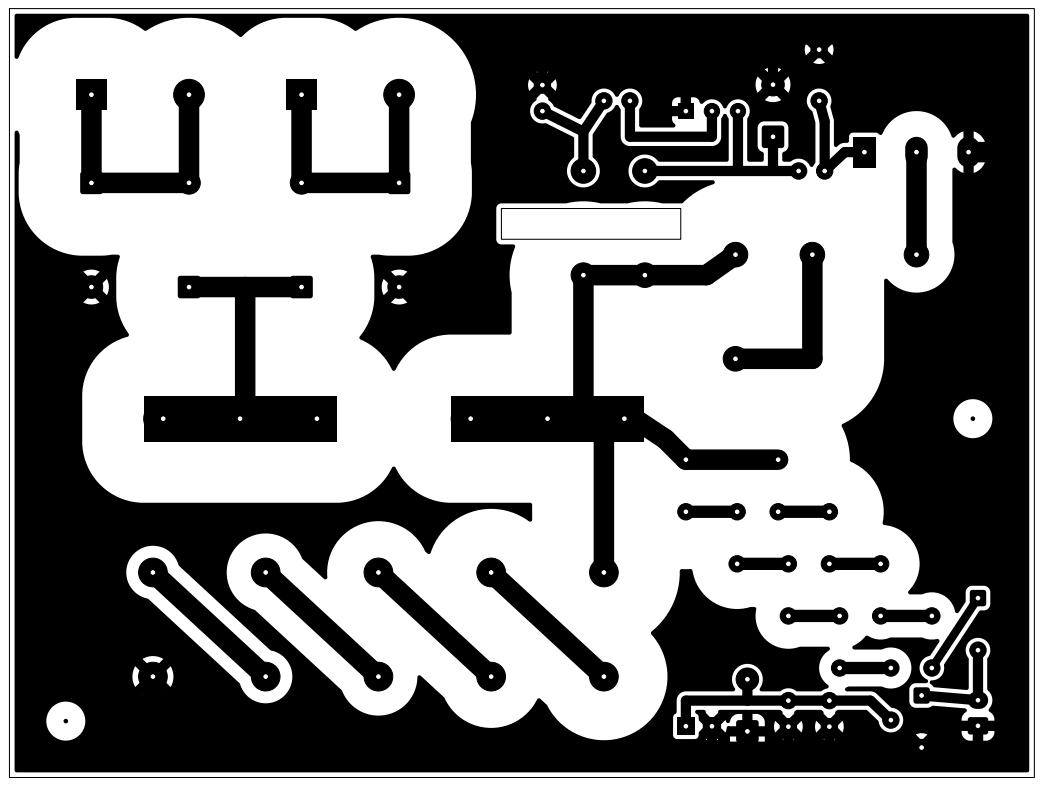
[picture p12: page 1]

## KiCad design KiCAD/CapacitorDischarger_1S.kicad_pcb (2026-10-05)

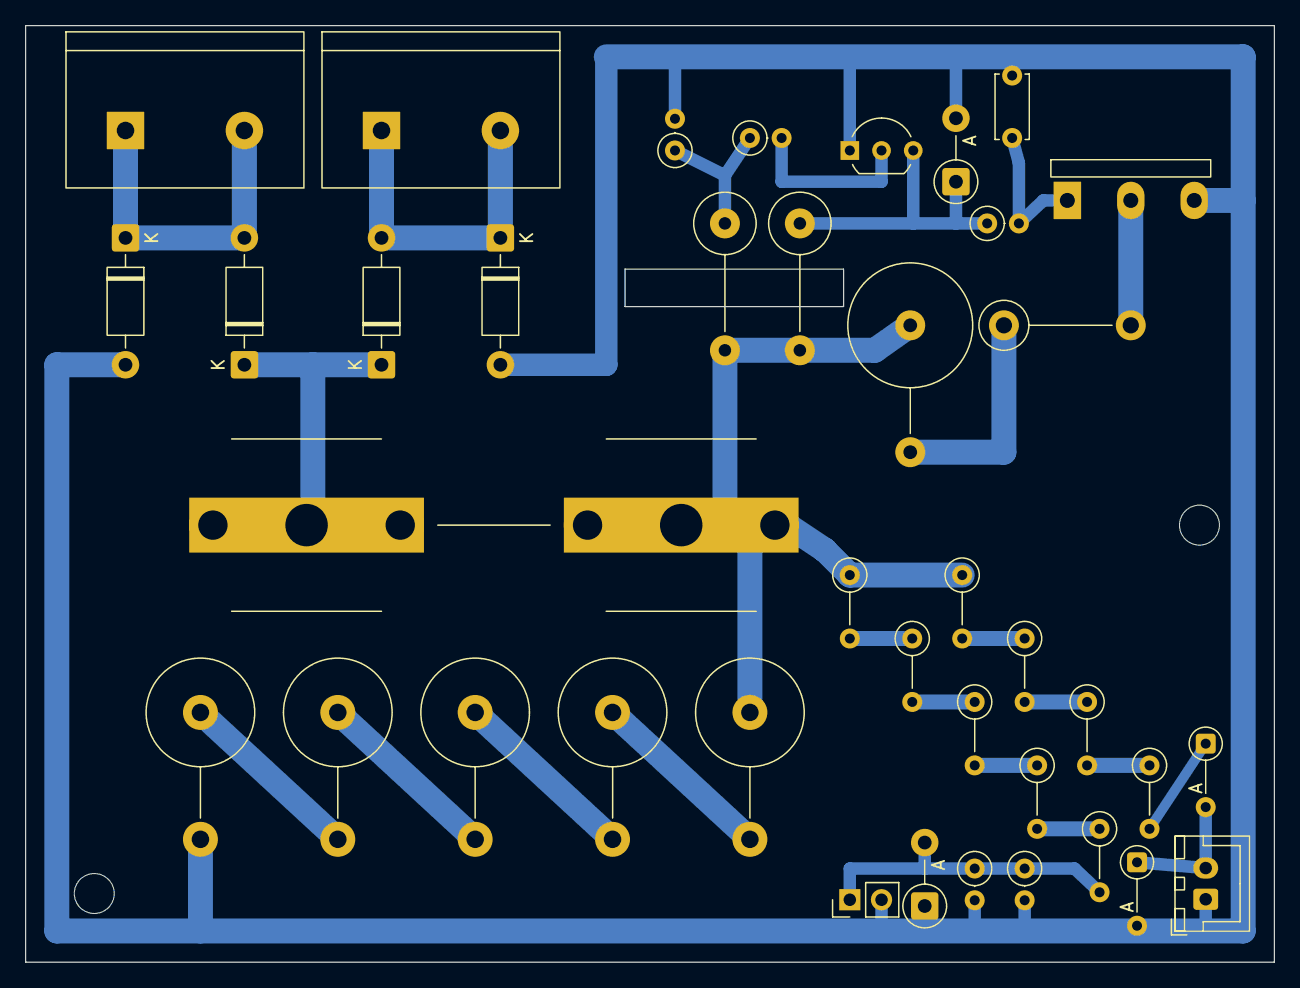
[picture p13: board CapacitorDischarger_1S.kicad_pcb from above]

Board: 2 copper layers, 100.0 x 75.0 mm, 41 parts (0 on the bottom side), 25 nets.

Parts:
C_byp2: 100nF 50V; C_Disc_D5.0mm_W2.5mm_P5.00mm
D1, D2, D3, D4: 1N4007; D_DO-41_SOD81_P10.16mm_Horizontal
D9: BZX85C12; D_DO-41_SOD81_P5.08mm_Vertical_AnodeUp
D_LED1: BZX55C8V2; D_DO-35_SOD27_P5.08mm_Vertical_AnodeUp
D_clamp1: 1N4007; D_DO-41_SOD81_P5.08mm_Vertical_AnodeUp
D_clamp2: BZX55C8V2; D_DO-35_SOD27_P5.08mm_Vertical_AnodeUp
F1: 2A 1000VDC gR; Fuseholder_Clip-10.3x38mm_Schurter_CSO_0751.0506
H1, H3: M3 (nylon screw); MountingHole_3.2mm_M3
J3, J4: MKDS5/2-9.5; TerminalBlock_Phoenix_MKDS-5-2-9.5_1x02_P9.52mm
J5: PM-128 input; PinHeader_1x02_P2.54mm_Vertical
J6: XH LED cable; JST_XH_B2B-XH-A_1x02_P2.50mm_Vertical
Q1: MPSA42; TO-92_Inline_Wide
Q2: STP10NK80Z; TO-220-3_Vertical_LegsSpread_P5.08mm
R1: 1M 3W; R_Axial_DIN0516_L15.5mm_D5.0mm_P10.16mm_Vertical_BodyOnPad2
R2, R3: 10k; R_Axial_DIN0207_L6.3mm_D2.5mm_P2.54mm_Vertical
R4: 100R; R_Axial_DIN0207_L6.3mm_D2.5mm_P2.54mm_Vertical
R5: 470k 3W; R_Axial_DIN0516_L15.5mm_D5.0mm_P10.16mm_Vertical_BodyOnPad2
R_LED1, R_LED2, R_LED3, R_LED4: 100k 0.6W; R_Axial_DIN0207_L6.3mm_D2.5mm_P5.08mm_Vertical
R_fast1: 50R 7W; R_Axial_Ohmite_27J_7W_Vertical
R_sig1, R_sig2, R_sig3, R_sig4, R_sig5: 100k 0.6W; R_Axial_DIN0207_L6.3mm_D2.5mm_P5.08mm_Vertical
R_sig_bot1, R_sig_bot2: 100R 1%; R_Axial_DIN0207_L6.3mm_D2.5mm_P2.54mm_Vertical
R_slow1, R_slow2, R_slow3, R_slow4, R_slow5: 4k7 5W; R_Axial_Ohmite_45F_5W_Vertical
TF1: SF129R0 133°C; ThermalCutoff_SEFUSE_SF_Vertical

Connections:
/BASE_DIV: R1.2, R2.1, R3.1
/BRIDGE_P: D1.1, D3.1, F1.1
/GATE: C_byp2.1, Q2.1, R4.2
/GATE_TOP: D9.1, Q1.3, R4.1, R5.2
/GND: C_byp2.2, D2.2, D4.2, D9.2, D_clamp1.1, D_clamp2.2, J5.2, J6.1, Q1.1, Q2.3, R2.2, R_sig_bot1.2, R_sig_bot2.2, R_slow5.2
/HVp: F1.2, R1.1, R5.1, R_LED1.1, R_fast1.1, R_sig1.1, R_slow1.1
/LED_A: D_LED1.2, D_clamp2.1, J6.2
/PROBE_A: D1.2, D4.1, J3.1, J3.2
/PROBE_B: D2.1, D3.2, J4.1, J4.2
/SIGOUT: D_clamp1.2, J5.1, R_sig5.2, R_sig_bot1.1, R_sig_bot2.1
unnamed: D_LED1.1, R_LED4.2
unnamed: Q1.2, R3.2
unnamed: Q2.2, TF1.2
unnamed: R_LED1.2, R_LED2.1
unnamed: R_LED2.2, R_LED3.1
unnamed: R_LED3.2, R_LED4.1
unnamed: R_fast1.2, TF1.1
unnamed: R_sig1.2, R_sig2.1
unnamed: R_sig2.2, R_sig3.1
unnamed: R_sig3.2, R_sig4.1
unnamed: R_sig4.2, R_sig5.1
unnamed: R_slow1.2, R_slow2.1
unnamed: R_slow2.2, R_slow3.1
unnamed: R_slow3.2, R_slow4.1
unnamed: R_slow4.2, R_slow5.1

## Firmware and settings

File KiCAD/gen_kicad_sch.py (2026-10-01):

"""Generate CapacitorDischarger.kicad_sch (flat, single sheet) from a part/net list.

Connectivity is defined by net labels on pin stubs (and by pins that touch,
for the resistor chains), so the netlist is exact by construction; check it
with check_kicad.py (kicad-cli netlist + ERC, compared to the SPICE netlist).

Run with KiCad's python or any python 3:  python gen_kicad_sch.py
"""
import math
import os
import re
import sys
import uuid

HERE = os.path.dirname(os.path.abspath(__file__))
sys.path.insert(0, os.path.dirname(HERE))
from bom import BOM  # noqa: E402

KICAD_SYMS = r"C:\Program Files\KiCad\10.0\share\kicad\symbols"
PROJECT = "CapacitorDischarger"
ROOT_UUID = "c3000000-0003-0003-0003-000000000003"
NS = uuid.UUID(ROOT_UUID)
G = 1.27  # schematic grid

# ── Footprints ──────────────────────────────────────────────────────────────
FP = {
    "R0207":   "Resistor_THT:R_Axial_DIN0207_L6.3mm_D2.5mm_P10.16mm_Horizontal",
    "R3W":     "Resistor_THT:R_Axial_DIN0516_L15.5mm_D5.0mm_P20.32mm_Horizontal",
    "R_slow":  "CapDis:R_Axial_Ohmite_45F_5W",
    "R_fast":  "CapDis:R_Axial_Ohmite_27J_7W",
    "DO41":    "Diode_THT:D_DO-41_SOD81_P10.16mm_Horizontal",
    "DO35":    "Diode_THT:D_DO-35_SOD27_P7.62mm_Horizontal",
    "TF":      "CapDis:ThermalCutoff_SEFUSE_SF_Axial",
    "C":       "Capacitor_THT:C_Disc_D5.0mm_W2.5mm_P5.00mm",
    "TO92":    "Package_TO_SOT_THT:TO-92_Inline_Wide",
    "TO220":   "CapDis:TO-220-3_Vertical_LegsSpread_P5.08mm",
    "LED":     "LED_THT:LED_D5.0mm",
    "FUSE":    "CapDis:Fuseholder_Clip-10.3x38mm_Schurter_CSO_0751.0506",
    "MKDS":    "CapDis:TerminalBlock_Phoenix_MKDS-5-2-9.5_1x02_P9.52mm",
    "HDR2":    "Connector_PinHeader_2.54mm:PinHeader_1x02_P2.54mm_Vertical",
    "XH2":     "Connector_JST:JST_XH_B2B-XH-A_1x02_P2.50mm_Vertical",
    "MH":      "MountingHole:MountingHole_3.2mm_M3",
    "": "",
}


def u(*key):
    return str(uuid.uuid5(NS, "/".join(map(str, key))))


# ── Library symbol extraction ───────────────────────────────────────────────
def _block(text, start):
    d = 0
    for k in range(start, len(text)):
        if text[k] == "(":
            d += 1
        elif text[k] == ")":
            d -= 1
            if d == 0:
                return text[start:k + 1]
    raise ValueError("unbalanced")


_lib_cache = {}


def lib_symbol(lib, name):
    """Return the symbol s-expression text as stored in the .kicad_sym file."""
    if lib == "CapDis":
        path = os.path.join(HERE, "CapDis.kicad_sym")
    else:
        path = os.path.join(KICAD_SYMS, lib + ".kicad_sym")
    if path not in _lib_cache:
        _lib_cache[path] = open(path, encoding="utf8").read()
    t = _lib_cache[path]
    m = re.search(r'\n\t\(symbol "%s"\n' % re.escape(name), t)
    if not m:
        raise KeyError(lib + ":" + name)
    s = _block(t, m.start() + 2)
    assert "(extends" not in s, f"{lib}:{name} uses extends; use the parent symbol"
    return s


def embed(lib, name):
    s = lib_symbol(lib, name)
    s = s.replace(f'(symbol "{name}"', f'(symbol "{lib}:{name}"', 1)
    return "\t" + s.replace("\n", "\n\t")


def pins_of(lib, name):
    """{number: (x, y, angle)} in library coordinates (y up)."""
    s = lib_symbol(lib, name)
    out = {}
    for m in re.finditer(r"\(pin \w+ \w+\s*\(at ([-\d.]+) ([-\d.]+) (\d+)\)", s):
        num = re.search(r'\(number "([^"]+)"', s[m.end():m.end() + 800]).group(1)
        out[num] = (float(m.group(1)), float(m.group(2)), int(m.group(3)))
    return out


# ── Parts ───────────────────────────────────────────────────────────────────
SYM = {
    "R": ("Device", "R"), "D": ("Device", "D"), "DZ": ("Device", "D_Zener"),
    "LED": ("Device", "LED"), "C": ("Device", "C"), "F": ("Device", "Fuse"),
    "BAT": ("Device", "Battery"), "NPN": ("Transistor_BJT", "Q_NPN_EBC"),
    "NMOS": ("Transistor_FET", "Q_NMOS_GDS"), "CONN1": ("Connector_Generic", "Conn_01x01"),
    "CONN2": ("Connector_Generic", "Conn_01x02"), "MH": ("Mechanical", "MountingHole"),
    "HS": ("Mechanical", "Heatsink"), "DVM": ("CapDis", "PM-128"),
}

parts = []   # dicts
texts = []   # (x, y, text, size)


def part(ref, kind, value, fp, x, y, rot=0, nets=None, on_board=True, in_bom=True):
    parts.append(dict(ref=ref, kind=kind, value=value, fp=FP[fp], x=x * G, y=y * G, rot=rot,
                      nets=nets or {}, on_board=on_board, in_bom=in_bom))


def note(x, y, txt, size=1.27):
    texts.append((x * G, y * G, txt, size))


def vchain(prefix, n, kind, value, fp, x, y0, top_net, bot_net):
    """Vertical chain of 2-pin parts whose pins touch (pitch 6 grid = 7.62 mm)."""
    for i in range(n):
        nets = {}
        if i == 0 and top_net:
            nets["1"] = top_net
        if i == n - 1 and bot_net:
            nets["2"] = bot_net
        part(f"{prefix}{i + 1}", kind, value, fp, x, y0 + 6 * i, 0, nets)


# Coordinates below are in grid units (1.27 mm). Page A3 = 330 × 233 grid.
wires = []      # segments in grid units
junctions = []  # grid points
labels = []     # (net, x, y, angle) free labels placed on wires


def W(*pts):
    for a, b in zip(pts, pts[1:]):
        wires.append((a, b))


# 1 ── Input, reverse-polarity bridge, fuse ───────────────────────────────────
note(8, 12, "1. INPUT + REVERSE-POLARITY BRIDGE + FUSE", 2)
part("J1", "CONN1", "SLB4-G-21", "", 18, 26, 180, {"1": "PROBE_A"}, on_board=False)
part("J2", "CONN1", "SLB4-G-22", "", 18, 50, 180, {"1": "PROBE_B"}, on_board=False)
part("J3", "CONN2", "MKDS5/2-9.5", "MKDS", 38, 26, 180, {"1": "PROBE_A", "2": "PROBE_A"})
part("J4", "CONN2", "MKDS5/2-9.5", "MKDS", 38, 50, 180, {"1": "PROBE_B", "2": "PROBE_B"})
note(8, 60, "J1/J2 = panel banana sockets (off-board), wired to J3/J4 with 1 mm² silicone wire (0.6/1 kV).\n"
            "Both poles of J3 = PROBE_A, both poles of J4 = PROBE_B: two blocks keep the input leads apart.")
# Device:D pin 1 = K (left at rot 0); rot 180 puts K on the right.
part("D1", "D", "1N4007", "DO41", 64, 24, 180, {"2": "PROBE_A", "1": "BRIDGE_P"})
part("D3", "D", "1N4007", "DO41", 64, 32, 180, {"2": "PROBE_B", "1": "BRIDGE_P"})
part("D4", "D", "1N4007", "DO41", 64, 40, 180, {"2": "GND", "1": "PROBE_A"})
part("D2", "D", "1N4007", "DO41", 64, 48, 180, {"2": "GND", "1": "PROBE_B"})
part("F1", "F", "2A 1000VDC gR", "FUSE", 88, 30, 90, {"1": "BRIDGE_P", "2": "HVp"})
note(80, 36, "F1: ESKA 1038820\n10.3×38 mm, 2× Schurter\nCSO 0751.0506 clips")

# 2 ── Slow path ─────────────────────────────────────────────────────────────
note(112, 12, "2. SLOW PATH", 2)
vchain("R_slow", 5, "R", "4k7 5W", "R_slow", 118, 24, "HVp", "GND")
note(112, 58, "5 × 4.7 kΩ / 5 W wirewound\n= 23.5 kΩ, 25 mA at 600 V")
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

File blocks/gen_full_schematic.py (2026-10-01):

"""Full 600V Capacitor Discharger schematic — schemdraw SVG.

Layout (left to right):
  Bridge → F1 → HV+ bus → Branch1(R_slow) | Branch2(R_fast+Q2) | Branch3(Q1 threshold)
                         | Branch4(LED) | Branch5(DVM sig divider 10 000:1 + clamp)
  → J5 → DVM1 Axiomet PM-128 (off-board), powered by floating BT1 9 V battery

HV section: bridge + R_slow + R_fast/TF1/Q2 + gate drive (R5/D9)
LV section: Q1 threshold, LED indicator, DVM divider, J5 → PM-128

NFet.right() orientation: drain up, source down, gate to the right.
BjtNpn orientation: base left, collector upper-right, emitter lower-right.
"""
import sys
import os
sys.path.insert(0, os.path.join(os.path.dirname(__file__), '..'))

import schemdraw
import schemdraw.elements as elm
from bom import LABEL

schemdraw.use('svg')

HV_Y  = 22   # y-coordinate of HV+ bus
GND_Y = 0    # y-coordinate of GND bus
EL    = 2.5  # standard element length

LABEL_OFST = 0.65   # horizontal gap: element column → label anchor

def rlabel(d, col_x, top_y, bot_y, text):
    """Place a label to the right of a vertical element."""
    mid_y = (top_y + bot_y) / 2
    d.add(elm.Label().at((col_x + LABEL_OFST, mid_y)).label(text, halign='left', valign='center'))

with schemdraw.Drawing(show=False) as d:
    d.config(fontsize=9, inches_per_unit=0.43)

    # ═══════════════════════════════════════════════════════════════
    # DIODE BRIDGE — D1–D4 (1N4007)  Reverse-polarity protection
    # ═══════════════════════════════════════════════════════════════
    MID_Y = (HV_Y + GND_Y) / 2   # 11

    # Left column: D4(GND→PROBE_A), D1(PROBE_A→HV+)
    d.add(elm.Diode().up().at((0, GND_Y)).length(MID_Y))
    rlabel(d, 0, MID_Y, GND_Y, LABEL['D4'])
    d.add(elm.Diode().up().at((0, MID_Y)).length(MID_Y))
    rlabel(d, 0, HV_Y, MID_Y, LABEL['D1'])

    # Right column: D2(GND→PROBE_B), D3(PROBE_B→HV+)
    d.add(elm.Diode().up().at((4, GND_Y)).length(MID_Y))
    d.add(elm.Label().at((4 - LABEL_OFST, (GND_Y + MID_Y) / 2)).label(LABEL['D2'], halign='right', valign='center'))
    d.add(elm.Diode().up().at((4, MID_Y)).length(MID_Y))
    d.add(elm.Label().at((4 - LABEL_OFST, (MID_Y + HV_Y) / 2)).label(LABEL['D3'], halign='right', valign='center'))

    # PROBE_A / PROBE_B terminals
    d.add(elm.Dot().at((0, MID_Y)))
    d.add(elm.Line().left(1.5).at((0, MID_Y)))
    d.add(elm.Dot(open=True).at((-1.5, MID_Y)).label('PROBE_A', loc='left'))

    d.add(elm.Dot().at((4, MID_Y)))
    d.add(elm.Line().right(1.5).at((4, MID_Y)))
    d.add(elm.Dot(open=True).at((5.5, MID_Y)).label('PROBE_B', loc='right'))

    # Top bridge rail: D1 cathode ── D3 cathode
    d.add(elm.Line().right().at((0, HV_Y)).tox(4))
    d.add(elm.Dot().at((2, HV_Y)))

    # Bottom bridge rail: D4 anode ── D2 anode
    d.add(elm.Line().right().at((0, GND_Y)).tox(4))
    d.add(elm.Ground().at((2, GND_Y)))

    # ═══════════════════════════════════════════════════════════════
    # HV+ BUS and GND BUS
    # ═══════════════════════════════════════════════════════════════
    HV_BUS_END = 44     # GND bus / connector leads extend further right

    # F1 — protection fuse: opens on single-fault (Q1/D9 failure → Q2 full-on at 600V)
    # Starts at x=4, after the bridge top rail ends, so the bridge cannot bypass it.
    F1e = d.add(elm.Fuse().right().at((4, HV_Y)).length(3))
    d.add(elm.Label().at(((4 + F1e.end[0]) / 2, HV_Y + 0.5))
          .label(LABEL['F1'], halign='center', valign='bottom'))
    B5_X = 33           # DVM divider — last branch on the HV+ bus
    d.add(elm.Line().right().at(F1e.end).tox(B5_X))   # HV+ bus ends at last branch
    d.add(elm.Label().at((F1e.end[0] + 1.5, HV_Y + 0.5)).label('HV+'))
    d.add(elm.Line().right().at((2, GND_Y)).tox(HV_BUS_END))

    # Section labels above the HV+ bus
    d.add(elm.Label().at((9,  HV_Y + 1.8)).label('── HV SECTION ──'))
    d.add(elm.Label().at((30, HV_Y + 1.8)).label('── LV SECTION ──'))

    # ═══════════════════════════════════════════════════════════════
    # BRANCH 1 — R_slow: 5 × 4.7 kΩ / 5 W wirewound  (always-on)
    # ═══════════════════════════════════════════════════════════════
    B1_X = 7
    d.add(elm.Dot().at((B1_X, HV_Y)))
    cur = (B1_X, HV_Y)
    for i in range(1, 6):
        top = cur[1]
        r = d.add(elm.Resistor().down().at(cur).length(EL))
        rlabel(d, B1_X, top, r.end[1], LABEL[f'R_slow{i}'])
        cur = r.end
    d.add(elm.Line().down().at(cur).toy(GND_Y))
    d.add(elm.Dot().at((B1_X, GND_Y)))

    # ═══════════════════════════════════════════════════════════════
    # GATE DRIVE — R5 (470 kΩ) pull-up; D9 shunt clamp to GND holds
    # gate ≤12 V; C_byp2 gate RC filter
    # HV+ → R5 → GATE_CTRL node ── D9 (shunt to GND) ∥ C_byp2 (shunt to GND)
    # ═══════════════════════════════════════════════════════════════
    R5_X = 11
    d.add(elm.Dot().at((R5_X, HV_Y)))
    R5e = d.add(elm.Resistor().down().at((R5_X, HV_Y)).length(EL))
    rlabel(d, R5_X, HV_Y, R5e.end[1], LABEL['R5'])
    GATE_CTRL_NODE = R5e.end
    d.add(elm.Dot(open=True).at(GATE_CTRL_NODE).label('GATE_CTRL', loc='right'))

    # D9 — Zener shunt clamp, cathode at GATE_CTRL (top), anode to GND (bottom)
    D9_X = R5_X - 2
    d.add(elm.Line().left().at(GATE_CTRL_NODE).tox(D9_X))
    d.add(elm.Dot().at((D9_X, GATE_CTRL_NODE[1])))
    D9e = d.add(elm.Zener().up().at((D9_X, GATE_CTRL_NODE[1] - EL)).length(EL))
    rlabel(d, D9_X, GATE_CTRL_NODE[1], GATE_CTRL_NODE[1] - EL, LABEL['D9'])
    d.add(elm.Line().down().at((D9_X, GATE_CTRL_NODE[1] - EL)).toy(GND_Y))
    d.add(elm.Dot().at((D9_X, GND_Y)))

    # C_byp2 — 100 nF gate RC filter (τ = R5 × C ≈ 47 ms, soft Q2 turn-on)
    CBP2 = d.add(elm.Capacitor().down().at(GATE_CTRL_NODE).length(EL))
    rlabel(d, R5_X, GATE_CTRL_NODE[1], CBP2.end[1], LABEL['C_byp2'])
    d.add(elm.Line().down().at(CBP2.end).toy(GND_Y))
    d.add(elm.Dot().at((R5_X, GND_Y)))
    d.add(elm.Line().right().at((D9_X, GND_Y)).tox(R5_X))

    # ═══════════════════════════════════════════════════════════════
    # BRANCH 2 — R_fast (50 Ω / 7 W) + TF1 thermal cutoff + Q2 N-MOSFET (STP10NK80Z)
    # ═══════════════════════════════════════════════════════════════
    B2_X = 14
    d.add(elm.Dot().at((B2_X, HV_Y)))
    RF = d.add(elm.Resistor().down().at((B2_X, HV_Y)).length(EL))
    rlabel(d, B2_X, HV_Y, RF.end[1], LABEL['R_fast'])

    # TF1 — one-shot thermal cutoff clamped to the R_fast body: opens if a live
    # supply below the threshold keeps Q2 on (R_fast overload that F1 can't see)
    TF1e = d.add(elm.Fuse().down().at(RF.end).length(EL))
    rlabel(d, B2_X, RF.end[1], TF1e.end[1], LABEL['TF1'])

    # NFet.right(): drain=top, source=bottom, gate to the right
    q2 = d.add(elm.NFet().right().anchor('drain').at(TF1e.end)
               .label(LABEL['Q2'], loc='left'))

    # Q2 source → GND
    d.add(elm.Line().down().at(q2.source).toy(GND_Y))
    d.add(elm.Dot().at((q2.source[0], GND_Y)))
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

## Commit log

2026-04-21 Initial commit — 600V Capacitor Discharger design
    Design documentation, BOM, topology notes, and PCB rules for a
    600V handheld capacitor discharger. Includes full schemdraw SVG
    schematic (gen_full_schematic.py → full_schematic.svg) covering
    all 7 blocks: diode bridge, R_slow, R_fast/Q2 MOSFET, Q1 threshold
    detector, LED danger indicator, DVM signal divider, and DVM Vcc dropper.
2026-04-21 Fix schematic label placement and HV+ bus extent
    - Replace chained .label(loc='right') on vertical elements with explicit
    elm.Label() at offset coordinates — labels now sit clearly beside symbols
    instead of overlapping the vertical wire
    - Move C_Vcc label from left to right side to avoid overlap with R_sig5
    - End HV+ bus at B6_X (last branch) instead of running 4 units past it
    - Shift R3 label rightward past the resistor body, clear of R1
    [gen_full_schematic.py]
2026-04-21 Add BOM as single source of truth; wire schematic labels to it
    bom.py: complete component data for all 28 line items — description,
    part number, status (sourced/buy/sourced_partial/sourced_unused), stress
    notes. Generates LABEL dict used by the schematic. Running it standalone
    prints a buy list, sourced list, and unused inventory.
    gen_full_schematic.py: all hardcoded label strings replaced with LABEL[]
    lookups from bom.py — changing a value or part number in bom.py now
    propagates automatically to the SVG on next run.
    [gen_full_schematic.py]
2026-04-22 Fix R1 and R5: replace parallel combinations with single properly-rated parts
    R1: sourced_partial (2.2MΩ ∥ 1.8MΩ) → buy single 1MΩ/1W/≥600V metal film
    R5: 470kΩ/0.6W (under-rated at 0.74W) → 470kΩ/1W/≥600V metal film
    Clear stale parallel-build notes from 1.8MΩ and 2.2MΩ sourced-unused entries
    Regenerate schematic with updated labels
2026-04-22 Update implementation_claude.md to match BOM: R1/R5 ratings
    R1: 1MΩ/0.6W → 1MΩ/1W/≥600V; remove parallel-build note
    R5: 470kΩ/0.6W → 470kΩ/1W/≥600V
2026-04-22 Add README, bom.md output, and BOM markdown writer
    - README.md: purpose, schematic, sources with links, improvements vs
    Pieraisa/Retronics/DeLuxe, generation instructions
    - bom.py: add write_bom_md() — running bom.py now also writes bom.md
    - bom.md: generated BOM with to-buy / sourced / unused sections
2026-04-25 Add ngspice simulation infrastructure; all 7 scenarios PASS
    - simulation/models.lib: device models for 1N4007, 2N3904, STF7NM80,
    Zeners DZ12/DZ8V2/DZ15, and DLED
    - discharger.cir.tmpl / discharger_dc.cir.tmpl: parameterised netlists
    for transient and DC sweep analyses
    - scenarios.py: 7 scenarios (A-G) with assertion functions covering all
    operating regimes (slow path, fast path, LED cutoff, DVM divider,
    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
2026-04-26 Add KiCad schematics (HV/LV/full) and ngspice simulation results
    All 7 simulation scenarios pass. Schematics cover the full capacitor
    discharger design: HV discharge path, LV control/indicator section,
    and combined top-level schematic.
    [hv_section.kicad_sch, lv_section.kicad_sch, out.csv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]
2026-04-26 Fix schematic vs SVG discrepancies: net name, diode refs, value strings
    - Rename global net GATE → GATE_CTRL to match reference SVG
    - Correct D2/D3/D4 reference designators to match SVG bridge labelling
    (D1 was already correct; D2↔D3 and D3↔D4 swapped)
    - Add voltage to zener value fields: D9 BZX85C12 12V, D_LED BZX55C8V2 8.2V,
    D_Vcc 1N4744A 15V
    - Add Vf to LED1 value: RED 5mm Vf~2V
    - Add ratings to Q2 value: STF7NM80 800V 6A
    - Add power rating to all 100kΩ/0.6W resistors (R3, R_LED1–3, R_sig1–5,
    R_sig_bot): 100k → 100k 0.6W
    [schematic.kicad_sch]
2026-04-26 Add C_byp2, C_byp1, R_cal to sim templates; all 7 scenarios PASS
    - discharger.cir.tmpl / discharger_dc.cir.tmpl: add C_byp2 (100nF
    gate bypass, τ=47ms turn-on), C_byp1 (100nF Vcc HF decoupling),
    and R_cal (1Ω nominal trimmer in signal divider bottom leg)
    - Regenerated netlists and re-ran all 7 scenarios; 7/7 PASS
    [out.csv]
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2026-04-26 Move schematics to KiCAD/; add project file and PCB notes
    - Rename schematic.kicad_sch → KiCAD/CapacitorDischarger.kicad_pro (matches KiCad project name convention)
    - Move hv_section.kicad_sch and lv_section.kicad_sch to KiCAD/
    - Add KiCAD/CapacitorDischarger.kicad_pro with HV net class pre-configured (2mm tracks, 0.5mm clearance, HVp/GND patterns)
    - Add KiCAD/PCB_info.md with formatted PCB design Q&A notes
    - Fix C_Vcc symbol in gen_full_schematic.py: Capacitor → Capacitor2(polar=True)
    - Regenerate blocks/full_schematic.svg
    [CapacitorDischarger.kicad_sch, hv_section.kicad_sch, lv_section.kicad_sch]
2026-04-26 Update PCB design rules from Copilot review
    - Raise HV↔GND clearance to 8mm (was 6mm) — highest-risk pair in discharge path
    - Add 3–5mm minimum spacing between consecutive resistor bodies (R_slow1–5)
    - Add no-copper-pour rule under resistor bodies — bare FR4 reduces surface tracking
2026-04-26 Fix incorrect alt part for R_slow/R_fast; add Vishay RS5
    Vishay AC05 was wrong — it is a 0.5W carbon film resistor, unsuitable
    for a 5W wirewound position. Replace with Vishay RS5 (5W wirewound,
    axial THT, correct industrial-grade alternative to Ohmite WN5).
2026-04-26 Swap Q2 primary: STP10NK80Z replaces STF7NM80
    STP10NK80Z has better specs for this application:
    - 9 A vs 6 A continuous drain current
    - 0.9 Ω vs 1.7 Ω Rds(on) — less heat during fast discharge
    - Both 800 V Vds, TO-220 package
    STF7NM80 kept as alternative. Note warns against FP variant (40 W Pd only).
2026-04-26 Update Q2 to STP10NK80Z across schematics, SVG, and CSV
    - KiCAD/hv_section.kicad_sch: Q2 value STF7NM80 → STP10NK80Z
    - KiCAD/CapacitorDischarger.kicad_sch: Q2 value updated to STP10NK80Z 800V 9A
    - blocks/gen_full_schematic.py: branch 2 comment updated
    - blocks/full_schematic.svg: regenerated with STP10NK80Z label
    - TO_BUY_list.csv: Q2 primary updated to STP10NK80Z
    Simulation files retain STF7NM80 SPICE model — functionally equivalent.
    [CapacitorDischarger.kicad_sch, TO_BUY_list.csv, hv_section.kicad_sch]
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2026-05-01 Fix Zener polarity in SVG schematic generator
    All three Zeners (D9, D_LED, D_Vcc) were drawn with anode at top
    (cathode at bottom) — reversed for shunt/clamp use. Draw each Zener
    going .up() from its anode so the cathode correctly lands at the
    high-voltage side.
    [gen_full_schematic.py]
2026-05-01 Replace Q1 2N3904→MPSA42, add R_LED4, swap R_cal to 10kΩ 3296W
    - Q1: 2N3904 (40V) → MPSA42 (300V) — safe margin in 600V circuit
    - R_LED: 3→4 resistors in series; each now sees ≤150V (was ~200V, 80% of rating)
    - R_cal: 200kΩ wirewound → 10kΩ cermet 25-turn (3296W-1-103LF); previous
    value could overdrive DVM beyond its 100V input limit
    - Add 3386P-1-103LF as sourced_unused
    - All 7 simulation scenarios PASS with updated MPSA42 model and R_LED4 node
    [lv_section.kicad_sch]
2026-05-01 Update main KiCAD schematic: MPSA42, R_LED4, 10k trimmer
    - Q1 value: 2N3904 → MPSA42
    - R_cal value: 200k trim → 10k trim
    - LED chain: add R_LED4 symbol + connecting wire; shift D_LED,
    LED1 and GND down 12 units to accommodate the extra resistor
    [CapacitorDischarger.kicad_sch]
2026-05-01 Commit updated simulation results (MPSA42 + R_LED4) and tidy .gitignore
    Re-run simulation outputs from previous session were never committed after
    Q1 model changed to QMPSA42 and R_LED4 added to the LED chain. All 7
    scenarios still pass with the updated netlist.
    Also ignores KiCad auto-generated files (.history/, *-backups/, *.kicad_prl,
    ~*.lck) and the Serena tool directory.
    [out.csv]
2026-05-01 Fix footprints to match KiCad 10 library and actual sourced components
    Five footprint names didn't exist in KiCad 10 (caused 'Cannot add' errors),
    and R_slow/R_fast were sized for generic ceramics, not the actual Ohmite parts.
    Library name fixes (all three schematics):
    R_Axial_Power_L15mm_W5mm_P20.32mm → R_Axial_DIN0516_L15.5mm_D5.0mm_P20.32mm_Horizontal
    C_Disc_D3.8mm_W2.6mm_P5.00mm → C_Disc_D3.8mm_W2.6mm_P2.50mm
    CP_Radial_D4.0mm_P2.50mm → CP_Radial_D4.0mm_P2.00mm
    Potentiometer_Vishay_T93_Vertical → Potentiometer_Bourns_3296W_Vertical
    Correct sizing for sourced Ohmite wirewound resistors:
    R_slow1-5 (Ohmite 45F, 5W, body 23.8×8.7mm) → R_Axial_Powe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
    [CapacitorDischarger.kicad_sch, hv_section.kicad_sch, lv_section.kicad_sch]
2026-05-01 Fix symbol lib_ids and inner sub-symbol names for KiCad 10 compatibility
    Schematic was generated with lib_ids that don't exist in KiCad 10,
    causing 'symbol not found' on Update from Library and 'invalid symbol'
    errors on sub-symbol name mismatches.
    lib_id renames (pin numbers were already correct):
    Device:R_Large → Device:R
    Device:R_POT → Device:R_Potentiometer_Trim
    Device:CP → Device:C_Polarized
    Device:Q_NPN_BCE → Transistor_BJT:MPSA42 (E=1, B=2, C=3)
    Device:Q_NMOS_GDS → Transistor_FET:Q_NMOS_GDS (G=1, D=2, S=3)
    Inner sub-symbol names updated to match new lib_ids:
    CP_0/1_1 → C_Polarized_0/1_1
    R_POT_0/1_1 → R_Potentiometer_Trim_0/1_1
    Q_NPN_B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
    [CapacitorDischarger.kicad_sch, hv_section.kicad_sch, lv_section.kicad_sch]
2026-05-01 KiCAD processing
    [CapacitorDischarger.kicad_sch]
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2026-07-29 Design review fixes: fuse F1, battery-powered DVM, R3=10k, KiCad polarity fixes
    Review of the full design (schematic, BOM, simulations) surfaced and fixed:
    - Add F1 protection fuse (2A/600V KLKD002.T + Keystone 3517 clips) in
    series after the bridge — opens on single-fault Q2-stuck-on (~12A).
    - Reduce R3 100k -> 10k: Q1 threshold now hFE-independent, 63V nominal /
    68V at the BF=40 corner (was 76V / 154V, peak I_fast ~3A over the 2A
    PCB limit).
    - Replace the DVM Vcc parasitic dropper (4x15k + 1N4744A) with a 9V
    battery (BT1, holder w/ switch) via new polarized JST XH input J6:
    the sourced DVM module measures 12-15mA, beyond the dropper's 9.75mA.
    - Fix gate-drive drawing in the ge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
    [CapacitorDischarger.kicad_sch, hv_section.kicad_sch, lv_section.kicad_sch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]
2026-10-01 Design review fixes, PM-128 voltmeter, TF1 cutoff, regenerated KiCad project
    Circuit / simulation
    - Add TF1 thermal cutoff (SEFUSE SF129R0, 133 °C) between R_fast and Q2;
    behavioural thermal model in the sim, live-supply scenario L
    - Replace the 0-100 V DVM module with an Axiomet PM-128 (200 mV FS) on a
    10 000:1 divider (5 x 100k over 2 x 100R), D_clamp input protection,
    floating 9 V battery
    - New scenarios: hFE/temperature corners (G3/G4), PM-128 divider (H),
    reverse polarity (I), hot-plug (J), 47 mF dump (K), live supply (L);
    run_sim fails on any ngspice error; 15/15 PASS
    BOM
    - F1 = ESKA 1038820 + Schurter CSO clips, R_sig_bot = 2 x 100R, HLMP-4700,
    HS-S01 heatsink, MST 220 i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
    [CapacitorDischarger.kicad_pcb, CapacitorDischarger.kicad_sch, CapacitorDischarger_1S.kicad_pcb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]
2026-10-01 Enclosure, front-panel LED via XH, DC-jack 9 V supply, build instructions
    - mechanical/enclosure: parametric FreeCAD case for the single-sided board
    (base + screwed cover, PM-128 in the cover, sockets in line with J3/J4,
    9 V jack on the left wall with a floating-supply warning, LED on the front,
    baffled vents, snap hooks + supports for the 2-hole PCB), fit-check script
    - LED1 off-board on a JST XH cable (J6); D_clamp2 (BZX55C8V2) holds LED_A at
    8.2 V if the LED is unplugged; sims 15/15 PASS; both boards re-placed, DRC clean
    - PM-128 powered from any floating 9 V via a panel DC jack (battery box dropped)
    - instruction.md: PCB making, assembly, wiring, tests, calibration, use
    Co-Autho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
    [CapacitorDischarger.kicad_pcb, CapacitorDischarger.kicad_sch, CapacitorDischarger_1S.kicad_pcb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]
2026-10-03 Solder-mask jig and 1:1 film PDF for the single-sided board
    - mechanical/mask_jig: FreeCAD-scripted jig for the 100 x 75 board, copper
    side up, 2 registration pins at H1/H3 (mirrored), STEP/STL exported
    - KiCAD/gen_films.py -> fab_1s/1S_films_1to1.pdf: A4 portrait, boards turned
    90 deg at the top; page 1 B.Cu positive + negative, page 2 B.Cu positive +
    B.Mask
    - PCB_info.md, instruction.md: reference the new films and jig
    [Mask_jig.step, Mask_jig.stl]
2026-10-05 1S board for home etching: wider traces, GND pour, combined film sheets
    - board_1s.py: tracks HV 2 mm / chains 1.2 mm / LV 1 mm; GND pour on B.Cu
    filled by kicad-cli with the voltage-aware rules (6 mm from HV, 0.4 mm
    from LV), so only ~40 % of the copper is etched; DRC clean
    - gen_films.py: 1S_copper_components_1to1.pdf (B.Cu positive + mirrored
    F.Fab/F.SilkS for toner transfer) and 1S_solder_mask_1to1.pdf (2x B.Mask
    to stack), A4 portrait, images at the top; films and fab outputs regenerated
    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
    [CapacitorDischarger_1S.kicad_pcb, CapacitorDischarger_1S.step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]
2026-10-06 Enclosure: mount LED1 in a 5 mm panel clip instead of gluing it
    Hole is now Ø6.6 for the clip's Ø6.5 body, recess removed, LED moved to X 14.4
    (centred between the front-left boss and the PM-128). Fit check: clip/LED to
    meter 1.1 mm, clip to boss 0.75 mm, no overlaps.
    [Enclosure_base.step, Enclosure_base.stl, Enclosure_cover.step]
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2026-10-18 Enclosure: captive M3 nuts in the cover bosses instead of heat-set inserts
    Each boss gets a Ø3.4 screw hole and a horizontal 5.8 × 2.8 nut slot 2.2 mm
    under its top, with a flat stop under the screw axis. Front slots open
    rearwards (clear of the LED clip), rear ones forwards; the assembly check
    shows no part in any slot's insertion path. Cover screws stay M3×10.
    PCB screws H1/H3 change from M3×12 to M3×10 nylon: ×12 stuck out 2 mm
    below the floor. BOM, buy list, instruction.md and README updated.
2026-10-28 1S board: 1 mm pour gaps for toner transfer, wider D_LED1-K link
    - board_1s.py: GND pour keeps 1 mm from LV copper (was 0.4), 1 mm thermal
    gaps and 1 mm minimum neck, so toner no longer flakes around the gate
    drive (near Q2) and the J5/J6 corner
    - J5 up 0.4 mm and its SIGOUT stub to y 67.0: 1 mm from the GND ring and
    from J5 pad 2
    - D_LED1-K link 0.8 -> 1.2 mm with one bend, still 1.5 mm from R_LED4 pad 1
    - DRC clean; only sub-1 mm gaps left are pad-to-pad inside 2.5/2.54 mm
    pitch footprints (0.80-0.94 mm)
    - fab_1s outputs regenerated; PCB_info.md / instruction.md updated
